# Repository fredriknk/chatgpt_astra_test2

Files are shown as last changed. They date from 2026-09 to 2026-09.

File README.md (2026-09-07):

# Codex EE-design test, human foreword
So, background, i saw the Chatgpt Astra demo for kicad design and wanted to try it out myself, i just have an Open AI plus subscription, so i had to use the LOW setting to not nuke my usage immidiatly. But it managed to make this design within my three usage resets. Im pretty damn impressed with the result, its not perfect, but it is a fully routed design with no drc errors made in under 3 hours with a 20$ subscription. I would say the most lacking part is the schematic, it is not very human readable, but i do understand why it is made as it is as ive tried multiple MCP's for ee design and wires in schematics becomes a hot mess with more than a few components. But now im out of resets so i thought i stop here. 

Initial repo: [my kicad template](https://github.com/fredriknk/kicad_template)
Initial promt: [prompt](https://github.com/fredriknk/chatgpt_astra_test2/blob/main/Prompt.md)

After the initial prompt i basically just said "Sounds like a good idea" to any questions

# ESP32 24 V current-loop interface - Rev A

A 100 x 80 mm, four-layer prototype with an ESP32-S3, one protected 4-20 mA input, and one sourcing 4-20 mA output. Power and signal grounds are shared; this is not an isolated interface.

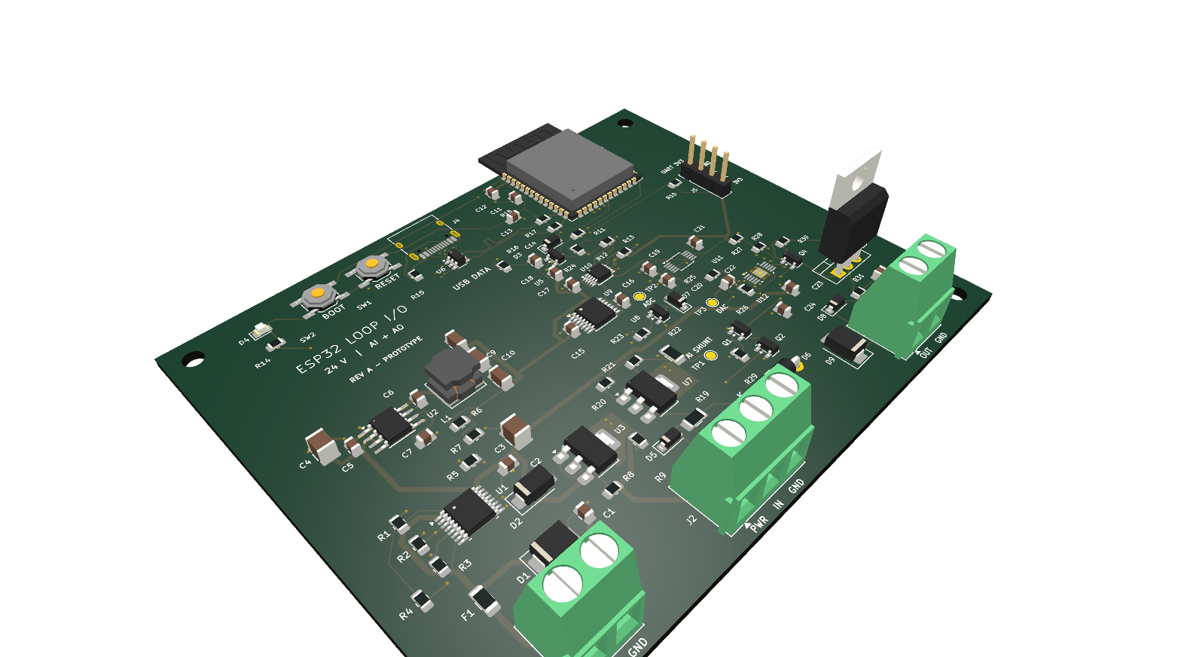
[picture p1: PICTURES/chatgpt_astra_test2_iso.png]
Rev A PCB


The layout is fully routed. Final KiCad 9 checks report **zero ERC violations, zero DRC violations, zero unconnected items, and zero schematic/PCB parity errors**. The independent connectivity check covers 93 components and 273 connected pins. Hardware accuracy, fault survival, thermal performance, EMC and USB interoperability still require prototype testing.

| Start here | Contents |
|---|---|
| [Design and bring-up guide](DOCUMENTATION/DESIGN.md) | Wiring, protection, firmware interface, calibration and bench tests |
| [Fabrication notes](DOCUMENTATION/FABRICATION.md) | Stackup, USB impedance, assembly and procurement |
| [KiCad project](CAD/chatgpt_astra_test2/chatgpt_astra_test2.kicad_pro) | Editable schematic and PCB, with local libraries |
| [Schematic PDF](DOCUMENTATION/chatgpt_astra_test2_schematic.pdf) | Five schematic sheets |
| [Board layers PDF](DOCUMENTATION/chatgpt_astra_test2_board_prints.pdf) | Copper, mask, silkscreen and assembly views |
| [Layout verification](DOCUMENTATION/board_review/README.md) | Checks, USB length audit and milestones |
| [Manufacturing outputs](PRODUCTION/20260907_1303_chatgpt_astra_test2/) | Four copper layers, masks, silk, paste, outline, drills, BOM and placement CSV |
| [CI build log](DOCUMENTATION/ci_build.log) | Successful complete output-pipeline run |

## Regenerate and check

On Windows with KiCad 9 installed, run `generate_outputs.bat`. The equivalent command is:

```text
python build_outputs.py --project CAD/chatgpt_astra_test2/chatgpt_astra_test2.kicad_pro --iso --zip
```

The script fails on ERC/DRC violations and generates a new timestamped production folder. It does not place an order. `generate_outputs.sh` provides the same entry point on systems with KiCad on PATH. Set `KICAD9_3DMODEL_DIR` to the installed KiCad model library if needed.

The BOM is an engineering BOM: semiconductor part numbers are in Value fields, while several passives retain value/rating specifications rather than purchasing MPNs. Review procurement before ordering. Three installed 3D models are missing (USB connector, DAC and current driver); their footprints are present, but the STEP/render is not a complete mechanical assembly model.

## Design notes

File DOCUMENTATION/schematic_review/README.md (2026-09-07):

# Revision A schematic review

Open [the KiCad project](../../CAD/chatgpt_astra_test2/chatgpt_astra_test2.kicad_pro), then its root schematic. The design has five A3 sheets and 93 physical components. Project-local symbol and footprint libraries are included.

## Sheet previews

1. [System interfaces](svg/chatgpt_astra_test2.svg)
2. [Power and sensor supply](svg/chatgpt_astra_test2-02%20_%20POWER%20AND%20SENSOR%20SUPPLY.svg)
3. [ESP32 and USB](svg/chatgpt_astra_test2-03%20_%20ESP32%20AND%20USB.svg)
4. [Current input](svg/chatgpt_astra_test2-04%20_%20PROTECTED%20CURRENT%20INPUT.svg)
5. [Current output](svg/chatgpt_astra_test2-05%20_%20PRECISION%20CURRENT%20OUTPUT.svg)

## Implemented decisions

- TPS26600 entry protection: approximately 399 mA current limit, 16.66 V nominal rising UV threshold and 33.80 V nominal rising OV threshold. RTN is deliberately separate from GND. Its exposed pad connects to RTN.
- LMR36510, 22 uH inductor, 100k/43.2k divider, three 22 uF output capacitors: nominal 3.315 V supply. Capacitor effective capacitance under bias and the exact inductor order code still require purchasing review.
- LT3092 sensor supply limiter: approximately 40.2 mA. LT3092 input limiter: approximately 30.1 mA. Both are configured as floating two-terminal limiters. This replaces the preliminary MAX14626 choice and avoids its bypass ground-current error.
- Input uses 100 ohm shunt, 1 kohm ADC series resistor, LM4040 3 V clamp, TMUX1511 powered-off isolation, and ADS1115.
- ESP32-S3-WROOM-1-N8, native USB-C data/programming, manual boot/reset, UART header and status LED. The board requires 24 V while programming. USB VBUS only serves USB-side ESD protection.
- TPS3839G33 supervises 3.3 V. Its SYS_OK signal inhibits the ADC switch and output enable during undervoltage. A diode couples the supervisor to ESP_EN without shorting the push-pull supervisor output when RESET is pressed.
- DAC80501Z is strapped to I2C address 0x49; ADS1115 uses 0x48. DAC firmware must select REF-DIV=1 and BUFF-GAIN=1 before enabling output.
- XTR111 uses 1.00 kohm RSET. Its local 3 V regulator pulls OD high independently of MCU power. Two series NMOS devices require both AO_ENABLE and SYS_OK to enable the output.
- IRF9540N TO-220 P-MOSFET, PNP current limiter, output RC and reverse-blocking diode. The PNP limit is approximately 33–37 mA per the reference approach, deliberately above the controlled output range. This supersedes the provisional 28–30 mA hardware-limit estimate.

## Checks completed

KiCad 9.0.7 loaded and exported all five sheets. ERC reports **zero errors and zero warnings**, with no exclusions introduced. The exported netlist contains 93 components and 97 nets. An independent export check matched 273 connected physical pins to the capture intent and checked every symbol pin against its assigned footprint's numbered pads. Results are in [verification.json](verification.json) and [erc.json](erc.json).

The schematic was rendered to SVG and PNG for visual review. Supply rails and return branches are connected visibly where aligned; named nets connect the remaining functional blocks. Labels marked as global connect between sheets.

## Engineering limits and bench work

This is a populated engineering prototype schematic, not a fabrication release. ERC does not prove analog performance or fault survival.

1. **Accuracy:** ±16 uA after calibration remains a room-temperature target. Quantify ADC gain/nonlinearity, shunt and RSET tolerance/drift, DAC/reference error, clamp leakage and ADC input loading. Validate independent midpoint readings after two-point calibration.
2. **Input protection:** test sustained +30 V and -30 V miswiring, limiter startup overshoot, 3 V clamp recovery and powered-off isolation. D6 and R19 provide transient limiting, but their pulse-energy coordination has not been qualified to an IEC surge level. The 33 V entry TVS likewise does not establish a downstream 33 V clamp.
3. **Thermal:** the input limiter may dissipate about 0.8 W during a positive miswire; the sensor limiter about 1.2 W into a short at 30 V. Allocate copper for each SOT-223 tab's own net. The output MOSFET dissipates roughly 0.6 W into a short at 20 mA/30 V. A -30 V externally forced output can roughly double this; assess heatsinking and DC SOA before promising continuous negative-output fault survival.
4. **Compliance:** at 18 V and 20 mA/500 ohms, 8 V remains for driver, resistors, diode, cable and entry losses. This looks feasible but requires worst-case and bench confirmation. Sensor voltage is reduced by BOTH sensor-supply and input protection drops; verify the actual sensor's minimum voltage, especially at 18 V.
5. **Startup/failure:** test reset, supply ramps and brownout. XTR111 OD does not guarantee absolutely zero startup glitch. No independent firmware watchdog is fitted; a firmware stall that leaves AO_ENABLE asserted can hold the last current command.
6. **Procurement/layout:** finalize exact fuse, inductor, precision resistor and capacitor manufacturer codes, verify package dimensions, and review the layout before manufacturing. Footprint pad coverage is checked; it is not a substitute for the final manufacturer land-pattern review. The PCB file remains the original empty template.

## Firmware pin assignment

| Function | ESP32 GPIO |
|---|---|
| I2C SDA / SCL | 8 / 9 |
| AO enable, active high | 10 |
| AO fault, active low | 11 |
| ADC ready | 12 |
| Status LED | 13 |
| USB D- / D+ | 19 / 20 |
| UART TX / RX | 43 / 44 |
| ROM boot strap | 0 |

## Reproducibility

[build_schematic.py](../../CODE/build_schematic.py) generated the schematic and local libraries. It overwrites generated schematic files when run; preserve manual KiCad edits before regenerating. It reads the existing local KiCad libraries specified near its top. [check_schematic.py](../../CODE/check_schematic.py) checks a freshly exported XML netlist and ERC report. The editable KiCad files do not require either script to open.

Manufacturer references are embedded in IC properties and linked in the [design plan](../esp32_4-20mA_design_plan.md). Additional references: [LT3092](https://www.analog.com/media/en/technical-documentation/data-sheets/lt3092.pdf), [LM4040](https://www.ti.com/lit/ds/symlink/lm4040-n.pdf), [TMUX1511](https://www.ti.com/lit/ds/symlink/tmux1511.pdf), [TPS3839](https://www.ti.com/lit/ds/symlink/tps3839.pdf).

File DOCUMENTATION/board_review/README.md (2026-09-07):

# Rev A layout verification

The prototype is fully routed: **0 DRC violations, 0 unconnected items and 0 schematic-parity errors**. See [native DRC JSON](drc.json), [CI DRC report](../chatgpt_astra_test2_drc.rpt) and [USB audit](usb_audit.json).

| Property | Final state |
|---|---|
| Board | 100 x 80 mm, nominal 1.6 mm, four copper layers |
| Components | 93 schematic components plus four M3 mounting holes |
| Copper | 1010 track segments and 106 vias |
| F.Cu / In2.Cu / B.Cu segments | 898 / 75 / 37 |
| In1.Cu | Ground-reference plane; no signal tracks |
| USB | Manual pair, top-layer protected section, symmetric connector joins |
| USB pair skew | Approximately 0.10 mm for both USB-C orientations |
| Thermal copper | U1 EF_RTN and U3/U7 OUT heat-spreading areas; correct nets verified |

[Top copper](routing.svg), [bottom copper](routing_bottom.svg), [top assembly render](../../PICTURES/chatgpt_astra_test2_top.png), [isometric render](../../PICTURES/chatgpt_astra_test2_iso.png), and [board-layer PDF](../chatgpt_astra_test2_board_prints.pdf).

USB data contacts use two through-board transitions per electrical path at the connector-side crossover. Ground return vias and a local In2.Cu ground area reference that bottom-layer section. The remainder runs on F.Cu above In1.Cu. The ESD device's equivalent channels were exchanged consistently in schematic and PCB, and the series resistors moved close to the module. The reported skew measures copper paths plus nominal via depth; internal component paths are excluded. Length matching does not certify impedance: order the specified stackup and have the fabricator confirm 90 ohms differential, +/-10%.

The overall prototype still needs the electrical, thermal and fault tests in [DESIGN.md](../DESIGN.md). CAD checks do not establish measured accuracy, surge immunity or continuous-fault survival. [FABRICATION.md](../FABRICATION.md) records procurement and mechanical-model limitations.

## Milestones

| Commit | Checkpoint |
|---|---|
| 26806e6 | Schematic |
| 2561262 | 100 x 80 mm placement |
| 73e48d3 | Initial buck and DAC routing |
| 2b1e08d | Feedback and analog sensing |
| 8d3c7f9 | Corrected persisted routing classes and fabrication constraints |
| 7b6780f | Bulk routing |
| ae18761 | Ground stitch and routing review |
| 490d238 | Fully connected, DRC-clean PCB |
| 024ed17 | USB refinement, thermal copper and named stackup |

The placement PNG/SVG/JSON and `board_3d.png` in this folder are historical placement-checkpoint artifacts. Use the current routing drawings and `PICTURES/` renders for Rev A.

The Python layout scripts record individual construction steps and expect their respective input checkpoints. **Do not run the placement/schematic generators over the finished project**: they can overwrite routed copper, local footprint refinements and later layout decisions. Open the current KiCad files for normal editing. The repeatable final output entry point is `generate_outputs.bat` or `generate_outputs.sh`.

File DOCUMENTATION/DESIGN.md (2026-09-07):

# Rev A design and bring-up guide

## Purpose and status

This board accepts nominal 24 V DC, measures one 4-20 mA process signal, and generates one sourcing 4-20 mA signal under ESP32-S3 control. The schematic and PCB are complete and the output pipeline passes. Firmware is not included.

The intended input range is 18-30 V DC. The room-temperature accuracy target is approximately +/-16 uA after calibration; this is not a measured specification. There is no galvanic isolation or system-level IEC qualification.

## Connector wiring

Pin numbers refer to the schematic and square/pin-1 PCB pads. Field terminals also have silkscreen labels.

| Connector | Pin | Function |
|---|---:|---|
| J1, DC input | 1 | Positive nominal 24 V |
| J1 | 2 | GND |
| J2, current input | 1 | Current-limited sensor supply, approximately 40 mA limit |
| J2 | 2 | AI_IN: positive current input |
| J2 | 3 | GND |
| J3, current output | 1 | AO_OUT: sourcing current output |
| J3 | 2 | GND / receiver return |
| J4 | USB-C | Native ESP32 USB data; does not power the board |
| J5 | 1 | GND |
| J5 | 2 | ESP32 UART TX, GPIO43 |
| J5 | 3 | ESP32 UART RX, GPIO44 |
| J5 | 4 | Board 3.3 V; logic reference, not a second power input |

For a two-wire loop-powered transmitter, connect J2.1 to its positive supply terminal and its negative/current return terminal to J2.2. For an independently powered current output, connect its output to J2.2 and its reference to J2.3; leave J2.1 unused. Do not parallel J2.1 with another supply.

Connect J3.1 to a passive receiver's current-input positive terminal and its return to J3.2. This output supplies loop current; it is not a two-wire passive transmitter. Available load compliance depends on supply voltage, cable resistance and driver/transistor/protection drops. Verify it at minimum supply voltage and maximum intended load. All field and USB grounds are common.

## Power and protection

| Block | Devices and intended behavior |
|---|---|
| Input protection | F1 500 mA fuse, D1 SMBJ33CA TVS and U1 TPS26600 eFuse |
| eFuse settings | R1/R2: nominal 16.66 V undervoltage threshold; R3/R4: nominal 33.80 V overvoltage threshold; R5: approximately 399 mA current limit; C2: controlled startup ramp |
| Protected rail | V24_PROT, with bulk capacitance and D2 negative-output clamp |
| Logic regulator | U2 LMR36510, L1 22 uH and R6/R7 feedback; nominal 3.315 V |
| Sensor supply | U3 LT3092 and R8/R9 limit J2.1 current to approximately 40.2 mA |
| Reset supervision | U5 TPS3839 monitors 3.3 V; D3 couples its output to ESP_EN without shorting the supervisor's push-pull output when RESET is pressed |

Thresholds/current limits are nominal calculations; tolerances, hysteresis and transients matter. Protection must be verified with a current-limited source before deployment. The eFuse's RTN/thermal pad is its own net, not GND. LT3092 tabs are OUT. Q3's tab is its drain. The layout preserves these net assignments.

## Current input

The path is J2.2 -> D5 -> R19 -> D6/U7 protection -> R22 shunt -> GND. U7 limits abnormal positive input current to approximately 30.1 mA. R22 is 100 ohms, 0.01%, target 10 ppm/degree C. It develops 0.4 V at 4 mA and 2.0 V at 20 mA.

R23, U8 LM4040-3.0 and D7 clamp the measurement node. U9 TMUX1511 disconnects the ADC path when SYS_OK is low. U10 ADS1115 measures AI_ADC single-ended against ground. The shunt has a dedicated sense takeoff and a return to the reference plane.

For ADS1115 configured to +/-4.096 V full scale:

```text
Vshunt = signed_adc_code * 125 uV
Iinput = Vshunt / 100 ohms = signed_adc_code * 1.25 uA
```

Ideal readings are approximately 3200 counts at 4 mA and 16000 counts at 20 mA. The ADC range setting does not permit the input pin to exceed its supply rails. Reject communication failures and out-of-range readings in firmware; choose filtering/data rate for the required response and noise level.

## Current output

U11 DAC80501Z drives U12 XTR111. R26 is 1 kohm, 0.01%, target 10 ppm/degree C:

```text
Ioutput = 10 * Vdac / R26 = 10 mA/V * Vdac
```

Configure the DAC for an effective 2.5 V full-scale span: internal reference enabled, REF-DIV=1 and BUFF-GAIN=1. Nominal 4 mA and 20 mA codes are approximately 10486 and 52429. Confirm register programming and actual DAC span during bring-up before enabling the output.

R25/C22 filter the DAC output. Q3 IRF9540 provides high-side drive. Q4/R30 add a fallback current limit, nominally 33-37 mA rather than a precision limit. R31/C25, D8 and D9 provide output filtering and fault/transient protection. Load compliance must account for their series drops.

R27 pulls XTR_OD high, disabling output independently of the MCU supply. Q1/Q2 pull it low only when AO_ENABLE and SYS_OK are high. AO_FAULT_N reports the driver's active-low error output. The design defaults to disabled at reset, but startup/shutdown current glitches still require measurement. There is no independent watchdog that forces zero current if firmware stalls with AO_ENABLE high.

## Firmware interface

| Signal | ESP32-S3 GPIO | Notes |
|---|---:|---|
| I2C SDA / SCL | 8 / 9 | 4.7 kohm pull-ups to 3.3 V |
| AO_ENABLE | 10 | Active high; keep low until analog configuration is verified |
| AO_FAULT_N | 11 | Active-low XTR111 fault |
| ADC_RDY | 12 | ADS1115 ALERT/RDY, with pull-up |
| Status LED | 13 | Green LED through R14 |
| USB D- / D+ | 19 / 20 | Native USB, 22 ohm series resistors and ESD protection |
| UART TX / RX | 43 / 44 | J5, 3.3 V logic |
| BOOT | 0 | BOOT button / download strap |

ADS1115 uses 7-bit address **0x48**; DAC80501 uses **0x49**. Select ESP32 firmware/USB settings appropriate to the module and programming method.

Startup sequence:

1. Hold AO_ENABLE low, initialize GPIOs/I2C, and verify both analog devices respond.
2. Configure the DAC reference/divider/gain and write a safe code while output remains disabled.
3. Configure ADS1115 channel/range/rate and discard unsettled readings.
4. Load valid calibration coefficients, check supply state and AO_FAULT_N, then enable output deliberately.
5. Clamp normal commands to the supported range. Disable output on detected analog communication or supply faults and define recovery behavior explicitly.

## Calibration

Calibrate at stable temperature using instruments comfortably more accurate than the target board accuracy. For input calibration, apply known currents I1/I2 near 4/20 mA and record codes C1/C2. Use `I = I1 + (C-C1)*(I2-I1)/(C2-C1)`. Check intermediate points and repeat after power cycling.

For output calibration, measure currents at two safe DAC codes and derive code-versus-current slope/offset. Validate at 4, 8, 12, 16 and 20 mA with representative loads. Store coefficients with a version/checksum, board serial number, date, temperature and reference instrument. Reject missing/corrupt calibration rather than presenting calibrated accuracy.

## Bring-up and acceptance tests

| Step | Check |
|---|---|
| Unpowered inspection | Orientation, bridges, exposed-pad joints, precision grades, polarity and rail resistance |
| First power | Current-limited source, no field loads; inspect V24_PROT, 3.3 V, consumption and temperature |
| Programming | RESET/BOOT, UART, both USB-C orientations, enumeration, sustained transfers and reconnects |
| Analog supplies | XTR regulator and DAC reference/span; AO_ENABLE low must leave output disabled |
| Input transfer | 0, 4, 12, 20 and modest overrange current, noise/settling, power-off injection |
| Output transfer | Representative loads, minimum-supply compliance, open/short load and fault indication |
| Sequencing | Ramps, brownouts, rapid cycling, USB-only connection, loss of MCU supply, reset during output |
| Faults | Incremental current-limited field miswiring/reversal; record clamp waveforms and temperature |
| Thermal | Maximum normal load and sensor/output shorts at intended ambient/enclosure conditions |

TP1 is the shunt node, TP2 the ADC-side node, and TP3 the filtered DAC voltage. Use a nearby ground when probing fast clamp behavior.

U3 can dissipate approximately 1.2 W during a 30 V sensor-supply short; U7 can approach 0.8 W during a positive input fault. Copper spreads heat but does not replace thermal testing. Q3 dissipates roughly 0.6 W at 20 mA into a short from a 30 V rail; externally forcing the output negative increases dissipation. Establish fault duration and any heatsink/ambient derating before sustained-fault use.

## References

- [Espressif layout guidance](https://docs.espressif.com/projects/esp-hardware-design-guidelines/en/latest/esp32s3/pcb-layout-design.html): reference plane and USB requirements.
- [TPS2660](https://www.ti.com/lit/ds/symlink/tps2660.pdf), [LMR36510](https://www.ti.com/lit/ds/symlink/lmr36510.pdf): power/protection.
- [LT3092](https://www.analog.com/media/en/technical-documentation/data-sheets/3092fc.pdf): current limiting/thermal behavior.
- [ADS1115](https://www.ti.com/lit/ds/symlink/ads1115.pdf), [DAC80501](https://www.ti.com/lit/ds/symlink/dac80501.pdf), [XTR111](https://www.ti.com/lit/ds/symlink/xtr111.pdf): conversion and configuration.
- [ST USBLC6-2](https://www.st.com/resource/en/datasheet/usblc6-2.pdf): equivalent ESD channels and short reference connections.

Earlier planning notes retain calculation history. This guide and the current CAD files describe final Rev A.

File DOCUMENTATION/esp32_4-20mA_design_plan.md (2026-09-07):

# ESP32 24 V / 4–20 mA controller — preliminary design

Status: revision A schematic captured, 2026-09-07. Five sheets, 93 components, zero KiCad ERC violations. See the [schematic review](schematic_review/README.md) for implemented component choices, verification and remaining bench work. The preliminary choices below are retained as planning context; the schematic review supersedes them where noted.

## Scope and provisional requirements

Confirmed: ESP32 controller, nominal 24 V input, read and generate 4–20 mA.

Accepted architecture: one input and one output; common ground; input accepts an externally powered transmitter or a two-wire transmitter powered from a dedicated board terminal; output sources current into a passive receiver. The output is not a passive two-wire loop-powered transmitter. Exact connected equipment is not yet specified.

## Protection recommendation, 2026-09-07

- Main entry: fuse, bidirectional TVS, TPS26600-class eFuse with reverse polarity blocking, adjustable overvoltage cutoff, current limiting and soft start. Provisional cutoff about 33 V and current limit about 0.4 A; finalize tolerances and inrush. Coordinate TVS clamping at the specified pulse current with eFuse ratings and downstream transient exposure. A nominal TVS voltage is not its clamping voltage.
- Sensor supply: separate current-limited switch, provisionally 35–50 mA, so a cable short does not reset the controller; verify sensor startup current.
- Analog input: MAX14626 is a purpose-built candidate with 27–33 mA current limit, reverse-input blocking and thermal protection. It requires additional transient coordination and ADC protection. Its ground current (40 µA typical, 56 µA maximum under specified conditions) can bypass the shunt in the conventional connection, exceeding the 16 µA accuracy target before calibration. Do not freeze this part until residual error and drift are budgeted; use a lower-leakage limiter/disconnect arrangement if needed. Allow up to 2.8 V protector drop at 24 mA per datasheet. At 33 mA, the 100 ohm shunt develops 3.3 V, so resistor tolerance, limiter overshoot and ADC power-off protection matter.
- ADC branch: series resistance, RC filtering and low-leakage voltage clamps or a fault-protected switch that remains protective with 3.3 V off. Do not rely on internal ADC diodes or a rail clamp that back-powers 3.3 V.
- Analog output: datasheet XTR111 external current-limit network, thermally sized P-MOSFET, reverse-current blocking toward the driver and coordinated terminal transient clamp. Check both polarities of externally applied terminal voltage, including when the board is off. Provisional hardware current limit about 28–30 mA, subject to tolerance and thermal analysis.
- USB: low-capacitance data-line ESD array at connector; keep VBUS out of board power path for this revision.

Protection targets are sustained ±30 V field miswiring where applicable, output/sensor shorts and ordinary handling/hot-plug transients. No IEC surge or ESD compliance is claimed without a selected test level and validation.

Sources: [TPS2660 family](https://www.ti.com/product/TPS2660), [MAX14626 datasheet](https://www.analog.com/media/en/technical-documentation/data-sheets/max14626.pdf), and XTR111 reference below. Component values remain preliminary.

- Supply target: 18–30 V DC continuous.
- Input measurement range: 0–25 mA, nominal signal 4–20 mA.
- Output nominal range: 4–20 mA; allow controlled diagnostic overrange up to about 24 mA.
- Load target: 0–500 ohms including cable resistance, across supply range.
- Update target: 10 readings/s and 10 output updates/s.
- Initial accuracy target: ±16 µA (0.1% of 16 mA span), after individual two-point calibration at room temperature. Temperature range and drift requirement remain open; resolution alone does not establish accuracy.
- Provisional boot/reset behavior: output disabled until DAC configuration and application initialization succeed. Running-firmware failure requires an independent watchdog if guaranteed shutdown is required.

## Circuit blocks and candidate parts

1. Power: fused/current-limited entry, reverse-polarity protection and coordinated TVS clamp; LMR36510-class 65 V / 1 A buck to 3.3 V. Filter the analog supply locally. Choose final clamp and surge circuitry against the lowest rated downstream part, not only the buck rating. XTR111 operating supply tops out at 44 V.
2. MCU: ESP32-S3-WROOM-1 module; select memory variant later. USB data programming, ESD protection, boot/reset controls and UART test pads. Initially require 24 V board power while programming; USB VBUS must not backfeed the board. Follow Espressif supply, strap-pin and antenna rules.
3. Input: protected low-side 100 ohm precision shunt, Kelvin sensing, RC filtering, ADS1115 at 3.3 V. Start with ±4.096 V PGA range to preserve overrange measurement; analog pins still must remain within their supply limits.
4. Output: DAC80501 at 3.3 V with 2.5 V output range, XTR111, external P-channel MOSFET and datasheet current-limiting circuit. Use RSET = 1.00 kohm, preferably 0.01%, low temperature coefficient. Filter DAC output with settling time appropriate for 10 Hz operation.
5. Diagnostics: route XTR111 error flag to MCU with compatible pull-up; hardware default-disable on OD with sequencing checked. Add test points for shunt voltage, DAC voltage, protected supply and 3.3 V. Error flag does not replace measured output-current feedback.

## Calculations

Input: V = I × 100 ohms. At 4 / 20 / 25 mA, voltage is 0.4 / 2.0 / 2.5 V. Shunt dissipation at 25 mA is 62.5 mW; start with a 0.25 W precision part and verify derating. At ±4.096 V ADC range, nominal LSB is 125 µV, equivalent to 1.25 µA. Noise and error budget must be assessed separately.

A direct 24 V miswire across 100 ohms would dissipate 5.76 W. Therefore the bare shunt plus ADC clamp is insufficient. Select a series fault-current limiter/disconnect and coordinated clamps; verify continuous 30 V miswire, reverse voltage, leakage error and power-off behavior before schematic release. Extra series voltage drop reduces available sensor voltage.

Output: XTR111 transfer is IOUT = 10 × VIN / RSET. With 1.00 kohm, 0.4 V gives 4 mA and 2.0 V gives 20 mA; 2.4 V gives 24 mA. A 2.5 V / 16-bit DAC gives approximately 0.381 µA per code. Firmware shall clamp the normal command range and calibration results.

At 20 mA through 500 ohms, the load consumes 10 V. At 18 V input, 8 V remains before supply protection, cable and driver losses. At 24 mA it leaves 6 V. Complete the worst-case compliance calculation using the chosen transistor and protection network.

At 30 V and a near-zero-ohm load, total linear output-stage dissipation approaches 0.60 W at 20 mA or 0.72 W at 24 mA. Select the MOSFET using DC safe operating area and thermal resistance, not only on-resistance; allocate PCB copper and test short-circuit temperatures.

Reserve 3.3 V × 1 A = 3.3 W supply capacity for MCU and local electronics; this is a design allowance, not a measured consumption. Two 24 mA loops add up to 48 mA from the field supply. At 18 V and assumed 85% buck efficiency the combined allowance is about 0.264 A before margin and auxiliary loads. Start with a 24 V / 0.5 A bench supply; finalize fuse, inrush and sensor-power limits separately.

## Proposed terminals and wiring

| Connector | Pins | Purpose |
|---|---|---|
| J1 | VIN24, GND | Board power |
| J2 | SENSOR_PWR, AI_IN, GND | Protected sensor supply and current input |
| J3 | AO_OUT, GND | Sourcing current output |
| J4 | USB | Programming/data; 24 V required initially |

Two-wire input sensor: SENSOR_PWR → sensor +; sensor − → AI_IN. Current returns through the board shunt. Sensor-power terminal needs its own current limit. Minimum sensor voltage is protected supply minus shunt, protection and cable drops.

Externally powered current transmitter: signal current output → AI_IN, signal return → GND, provided the transmitter supports this common-ground connection. Leave SENSOR_PWR unused.

Output: AO_OUT → passive receiver +; receiver − → GND. Do not connect this sourcing output to a receiver terminal that supplies loop power.

All GND terminals and USB ground are electrically common. Isolation remains an architectural decision before schematic capture.

## KiCad structure and layout

Use existing CAD/chatgpt_astra_test2 project. Proposed sheets: top-level interfaces; power/protection; ESP32/USB; analog input; analog output.

Four-layer PCB with continuous ground plane. Keep switch-node copper compact and away from ADC, shunt and DAC. Kelvin-route the shunt and RSET ground return. Place terminal protection near connectors. Keep output transistor heat away from precision resistors. Follow module antenna copper/component keepout. Final dimensions and mounting holes remain open.

## Verification and remaining design work

Before capture: settle channel count/isolation/receiver type; choose exact protection parts and MOSFET; complete worst-case error, compliance and thermal budgets; check all pin logic levels, DAC startup variant, watchdog behavior and power sequencing.

After capture: verify symbols/footprints against manufacturer pinouts, run ERC and review loop paths. After layout: DRC, thermal/return-path review and fabrication outputs.

Bench acceptance: current-limited power-up at 18/24/30 V; input readings at 0/4/12/20/25 mA; output measurements at 4/12/20 mA into 0/250/500 ohms; two-point calibration with independent midpoint checks; open-loop and short-load behavior; reset/brownout/firmware-stall behavior; controlled miswire tests after protection analysis; Wi-Fi activity noise check. Temperature accuracy requires a separately agreed range and test.

## Manufacturer references

- [XTR111 datasheet](https://www.ti.com/lit/ds/symlink/xtr111.pdf): transfer function, compliance, external transistor and protection recommendations.
- [ADS1115](https://www.ti.com/product/ADS1115): ADC ranges and specifications.
- [DAC80501](https://www.ti.com/product/DAC80501): DAC supply, range, reference and startup variants.
- [LMR36510](https://www.ti.com/product/LMR36510): buck candidate.
- [ESP32-S3 schematic checklist](https://docs.espressif.com/projects/esp-hardware-design-guidelines/en/latest/esp32s3/schematic-checklist.html): MCU implementation requirements.

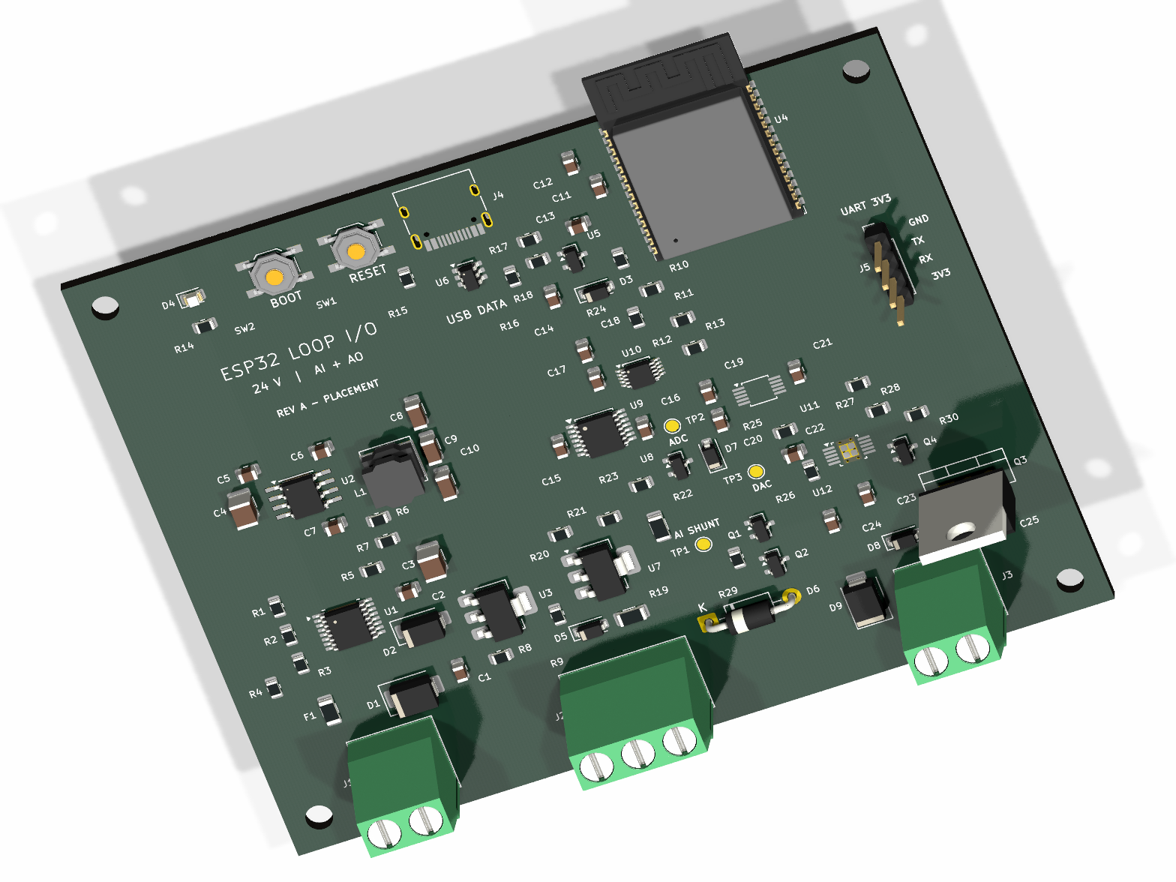
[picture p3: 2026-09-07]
DOCUMENTATION/board_review/board_3d.png

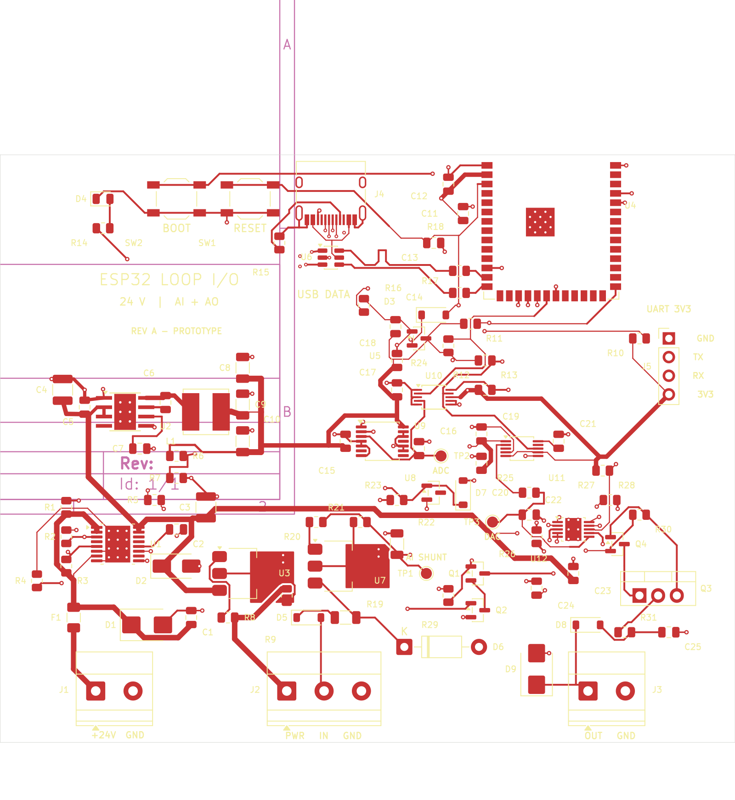
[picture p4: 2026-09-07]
DOCUMENTATION/board_review/routing.png

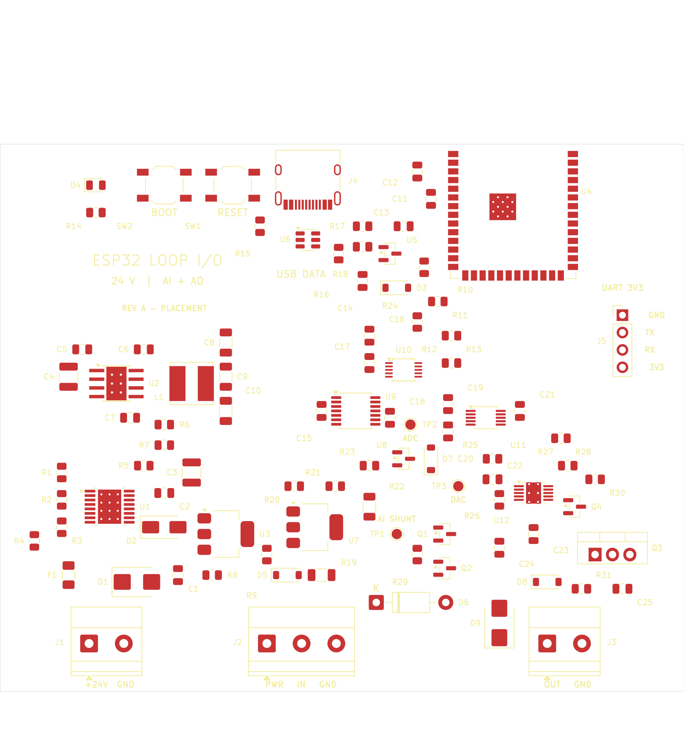
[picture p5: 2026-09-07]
DOCUMENTATION/board_review/placement.png

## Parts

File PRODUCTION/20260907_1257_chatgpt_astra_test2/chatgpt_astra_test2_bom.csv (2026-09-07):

Refs | Value | Footprint | Qty | Manufacturer | MPN | Datasheet | DNP
C1 | 100n / 100V | LoopIO:C_0805_2012Metric | 1 |  |  | ~
C2 | 10n / 50V | LoopIO:C_0805_2012Metric | 1 |  |  | ~
C3 | 22u / 63V | LoopIO:C_1210_3225Metric | 1 |  |  | ~
C4 | 2.2u / 100V | LoopIO:C_1210_3225Metric | 1 |  |  | ~
C5 | 220n / 100V | LoopIO:C_0805_2012Metric | 1 |  |  | ~
C6,C12,C14-C17,C19,C21 | 100n / 16V | LoopIO:C_0805_2012Metric | 8 |  |  | ~
C7,C18,C20,C22,C24 | 1u / 16V | LoopIO:C_0805_2012Metric | 5 |  |  | ~
C8-C10 | 22u / 10V | LoopIO:C_1206_3216Metric | 3 |  |  | ~
C11 | 10u / 10V | LoopIO:C_0805_2012Metric | 1 |  |  | ~
C13 | 1u / 10V | LoopIO:C_0805_2012Metric | 1 |  |  | ~
C23 | 100n / 50V | LoopIO:C_0805_2012Metric | 1 |  |  | ~
C25 | 10n / 100V | LoopIO:C_0805_2012Metric | 1 |  |  | ~
D1,D9 | SMBJ33CA | LoopIO:D_SMB | 2 |  |  | ~
D2 | SS110 | LoopIO:D_SMA | 1 |  |  | ~
D3,D7 | BAT54W | LoopIO:D_SOD-123 | 2 |  |  | ~
D4 | GREEN | LoopIO:LED_0805_2012Metric | 1 |  |  | ~
D5,D8 | BAV21W | LoopIO:D_SOD-123 | 2 |  |  | ~
D6 | BZX85C33 / 1.3W | LoopIO:D_DO-41_SOD81_P10.16mm_Horizontal | 1 |  |  | ~
F1 | 500mA / >=60V | LoopIO:Fuse_1206_3216Metric | 1 |  |  | ~
J1 | 18-30 V DC | LoopIO:TerminalBlock_Phoenix_MKDS-1,5-2-5.08_1x02_P5.08mm_Horizontal | 1 |  |  | ~
J2 | CURRENT INPUT | LoopIO:TerminalBlock_Phoenix_MKDS-1,5-3-5.08_1x03_P5.08mm_Horizontal | 1 |  |  | ~
J3 | CURRENT OUTPUT | LoopIO:TerminalBlock_Phoenix_MKDS-1,5-2-5.08_1x02_P5.08mm_Horizontal | 1 |  |  | ~
J4 | USB-C | LoopIO:USB_C_Receptacle_HRO_TYPE-C-31-M-12 | 1 |  |  | https://www.usb.org/sites/default/files/documents/usb_type-c.zip
J5 | UART / 3.3 V ONLY | LoopIO:PinHeader_1x04_P2.54mm_Vertical | 1 |  |  | ~
L1 | 22uH / Isat >=2A | LoopIO:L_Bourns_SRN6045TA | 1 |  |  | ~
Q1,Q2 | 2N7002 | LoopIO:SOT-23 | 2 |  |  | https://www.onsemi.com/pub/Collateral/NDS7002A-D.PDF
Q3 | IRF9540NPBF | LoopIO:TO-220-3_Vertical | 1 |  |  | http://www.irf.com/product-info/datasheets/data/irf9540n.pdf
Q4 | MMBT3906 | LoopIO:SOT-23 | 1 |  |  | https://www.onsemi.com/pdf/datasheet/pzt3906-d.pdf
R1 | 130k / 0.1% | LoopIO:R_0805_2012Metric | 1 |  |  | ~
R2,R4 | 10k / 0.1% | LoopIO:R_0805_2012Metric | 2 |  |  | ~
R3 | 274k / 0.1% | LoopIO:R_0805_2012Metric | 1 |  |  | ~
R5 | 30.1k / 1% | LoopIO:R_0805_2012Metric | 1 |  |  | ~
R6 | 100k / 0.1% | LoopIO:R_0805_2012Metric | 1 |  |  | ~
R7 | 43.2k / 0.1% | LoopIO:R_0805_2012Metric | 1 |  |  | ~
R8 | 40.2k / 0.1% | LoopIO:R_0805_2012Metric | 1 |  |  | ~
R9,R21 | 10R / 0.1% | LoopIO:R_0805_2012Metric | 2 |  |  | ~
R10,R11,R24,R27,R28 | 10k | LoopIO:R_0805_2012Metric | 5 |  |  | ~
R12,R13 | 4.7k | LoopIO:R_0805_2012Metric | 2 |  |  | ~
R14,R25 | 1k | LoopIO:R_0805_2012Metric | 2 |  |  | ~
R15,R16 | 5.1k / 1% | LoopIO:R_0805_2012Metric | 2 |  |  | ~
R17,R18 | 22R | LoopIO:R_0805_2012Metric | 2 |  |  | ~
R19 | 33R / pulse rated | LoopIO:R_1206_3216Metric | 1 |  |  | ~
R20 | 30.1k / 0.1% | LoopIO:R_0805_2012Metric | 1 |  |  | ~
R22 | 100R / 0.01% / 10ppm | LoopIO:R_1206_3216Metric | 1 |  |  | ~
R23 | 1k / 0.1% | LoopIO:R_0805_2012Metric | 1 |  |  | ~
R26 | 1k / 0.01% / 10ppm | LoopIO:R_0805_2012Metric | 1 |  |  | ~
R29 | 100k | LoopIO:R_0805_2012Metric | 1 |  |  | ~
R30,R31 | 15R | LoopIO:R_0805_2012Metric | 2 |  |  | ~
SW1 | RESET | LoopIO:SW_SPST_TL3342 | 1 |  |  | ~
SW2 | BOOT | LoopIO:SW_SPST_TL3342 | 1 |  |  | ~
TP1 | AI_SHUNT | LoopIO:TestPoint_Pad_D1.5mm | 1 |  |  | ~
TP2 | AI_ADC | LoopIO:TestPoint_Pad_D1.5mm | 1 |  |  | ~
TP3 | DAC_FILTER | LoopIO:TestPoint_Pad_D1.5mm | 1 |  |  | ~
U1 | TPS26600PWPR | LoopIO:HTSSOP-16-1EP_4.4x5mm_P0.65mm_EP3.4x5mm_Mask2.66x2.46mm_ThermalVias | 1 |  |  | https://www.ti.com/lit/ds/symlink/tps2660.pdf
U2 | LMR36510ADDAR | LoopIO:Texas_HTSOP-8-1EP_3.9x4.9mm_P1.27mm_EP2.95x4.9mm_Mask2.4x3.1mm_ThermalVias | 1 |  |  | http://www.ti.com/lit/ds/symlink/lmr36510.pdf
U3,U7 | LT3092EST#PBF | LoopIO:SOT-223-3_TabPin2 | 2 |  |  | https://www.analog.com/media/en/technical-documentation/data-sheets/lt3092.pdf
U4 | ESP32-S3-WROOM-1-N8 | LoopIO:ESP32-S3-WROOM-1 | 1 |  |  | https://www.espressif.com/sites/default/files/documentation/esp32-s3-wroom-1_wroom-1u_datasheet_en.pdf
U5 | TPS3839G33DBZR | LoopIO:SOT-23 | 1 |  |  | http://www.ti.com/lit/ds/sbvs193d/sbvs193d.pdf
U6 | USBLC6-2SC6 | LoopIO:SOT-23-6 | 1 |  |  | https://www.st.com/resource/en/datasheet/usblc6-2.pdf
U8 | LM4040AIM3-3.0 | LoopIO:SOT-23 | 1 |  |  | http://www.ti.com/lit/ds/symlink/lm4040-n.pdf
U9 | TMUX1511PWR | LoopIO:TSSOP-14_4.4x5mm_P0.65mm | 1 |  |  | https://www.ti.com/lit/ds/symlink/tmux1511.pdf
U10 | ADS1115IDGSR | LoopIO:TSSOP-10_3x3mm_P0.5mm | 1 |  |  | http://www.ti.com/lit/ds/symlink/ads1113.pdf
U11 | DAC80501ZDGSR | LoopIO:VSSOP-10_3x3mm_P0.5mm | 1 |  |  | https://www.ti.com/lit/ds/symlink/dac80501.pdf
U12 | XTR111AIDGQR | LoopIO:MSOP-10-1EP_3x3mm_P0.5mm_EP2.2x3.1mm_Mask1.83x1.89mm_ThermalVias | 1 |  |  | https://www.ti.com/lit/ds/symlink/xtr111.pdf

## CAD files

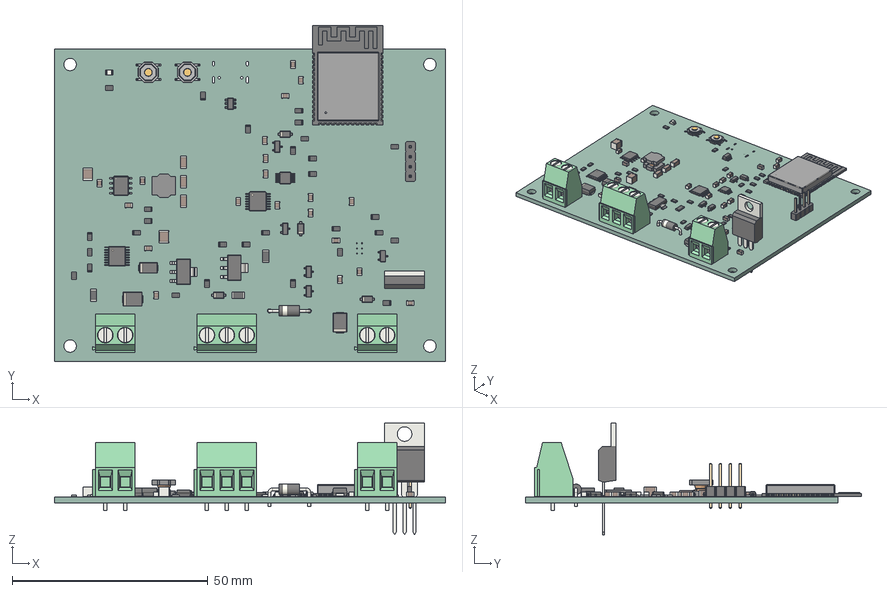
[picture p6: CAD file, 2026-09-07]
3D_MODEL/chatgpt_astra_test2.step
100.0 x 86.0 x 28.5 mm
R_0805_2012Metric x 29
C_0805_2012Metric x 20
D_SOD-123 x 4
TSSOP-14_4.4x5mm_P0.65mm
Texas_HTSOP-8-1EP_3.9x4.9mm_P1.27mm_EP2.85x4.9mm_Mask2.4x3.1mm_ ThermalVias
PinHeader_1x04_P2.54mm_Vertical
R_1206_3216Metric x 2
D_SMB x 2
TSSOP-10_3x3mm_P0.5mm
C_1210_3225Metric x 2
D_SMA
C_1206_3216Metric x 3
D_DO-41_SOD81_P10.16mm_Horizontal
SOT-223 x 2
ESP32-S3-WROOM-1
Fuse_1206_3216Metric
TerminalBlock_Phoenix_MKDS-1,5-2-5.08_1x02_P5.08mm_Horizontal x 2
TO-220-3_Vertical
LED_0805_2012Metric
SW_SPST_TL3342 x 2
SOT-23-6
HTSSOP-16-1EP_4.4x5mm_P0.65mm_EP3.4x5mm_Mask2.66x2.46mm
SOT-23 x 5
L_Bourns_SRN6045TA
TerminalBlock_Phoenix_MKDS-1,5-3-5.08_1x03_P5.08mm_Horizontal
chatgpt_astra_test2_PCB

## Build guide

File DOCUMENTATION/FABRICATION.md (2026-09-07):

# Rev A fabrication and assembly

| Item | Specification |
|---|---|
| Outline | 100 x 80 mm; X=50-150 mm, Y=50-130 mm |
| Mounting | Four 3.2 mm NPTH M3 holes, 92 x 72 mm centre spacing |
| Stackup | Nominal 1.6 mm, four layers; JLC04161H-7628 reference construction |
| Finish | ENIG selected in board stackup |
| Outer / inner copper | 35 um / 15.2 um nominal |
| Outer prepreg | 0.2104 mm FR4 7628 each side, nominal Dk 4.4 |
| Core | 1.065 mm FR4, nominal Dk 4.6 |
| Minimum trace / clearance | 0.15 / 0.15 mm; ordinary nets use 0.2 mm clearance |
| Ordinary vias | 0.6 mm land / 0.3 mm drill |
| USB-area vias | 0.5 mm land / 0.25 mm drill, with ground returns |
| Copper-to-edge | At least 0.3 mm, except intentional component overhang |
| USB impedance | Request 90 ohms differential, +/-10%; 0.25 mm width / 0.15 mm gap on paired sections, with local fanout exceptions |

Dielectric/copper values follow the [JLCPCB published stackup](https://jlcpcb.com/impedance). Finished thickness includes process tolerances and coatings; constituent dimensions are not an exact finished-thickness promise. For another fabricator/stackup, recalculate USB geometry. Obtain fabricator impedance confirmation; KiCad width/gap settings and length checks are not a field-solver result.

F.Cu contains primary routing and local thermal copper. In1.Cu is ground with no signal tracks. In2.Cu carries secondary routing and a local ground reference beneath the bottom-layer USB crossover. B.Cu contains short secondary routes and heat-spreading copper.

The antenna overhangs the board by approximately 6.2 mm. Preserve its keepout and allow enclosure clearance for antenna, plugs, terminal access and cable bends. Keep metal away from the antenna region.

## Assembly

- U1's thermal pad/copper is **EF_RTN**, not GND. U3/U7 tabs/copper are their respective **OUT** nets. Top/bottom copper and adjacent vias spread their heat.
- U1/U4/U12 exposed-pad footprints have 0.3 mm plated holes with 0.6 mm lands. Review paste coverage and via tenting/filling with the assembler to manage solder wicking.
- Q3's tab is its drain. Any heatsink must respect insulation/clearance; none is included in the mechanical model.
- All 93 electrical components are on top. Mounting holes are mechanical-only. Assemble through-hole parts separately; the generic position CSV is not a filtered SMT machine program.
- R22/R26 require their stated precision and temperature coefficient. Ceramic capacitors must retain suitable effective capacitance under DC bias. L1 needs the required inductance, saturation/current rating and physical fit.

The engineering BOM retains value/rating specifications for several passives; manufacturer/MPN columns are not fully populated. Confirm purchasing parts and substitutions before ordering or using an assembly service. No vendor-specific assembly package or purchasing order was generated.

## Package and mechanical model

The successful output run is `PRODUCTION/20260907_1303_chatgpt_astra_test2/`. Its ZIP includes Gerbers and drill files. Check the fabricator preview for four copper layers, masks, silk, outline, plated drills and NPTH drills. Paste layers are included for stencil use.

The STEP/renders omit three unavailable library models: J4 USB-C, U11 DAC and U12 XTR111. Their electrical footprints/BOM entries are present. Use PCB/F.Fab geometry and component drawings for those positions; the STEP is not a complete enclosure collision check.

This is a routed prototype with passing CAD checks. [Bring-up and fault tests](DESIGN.md) establish actual operating limits before deployment.

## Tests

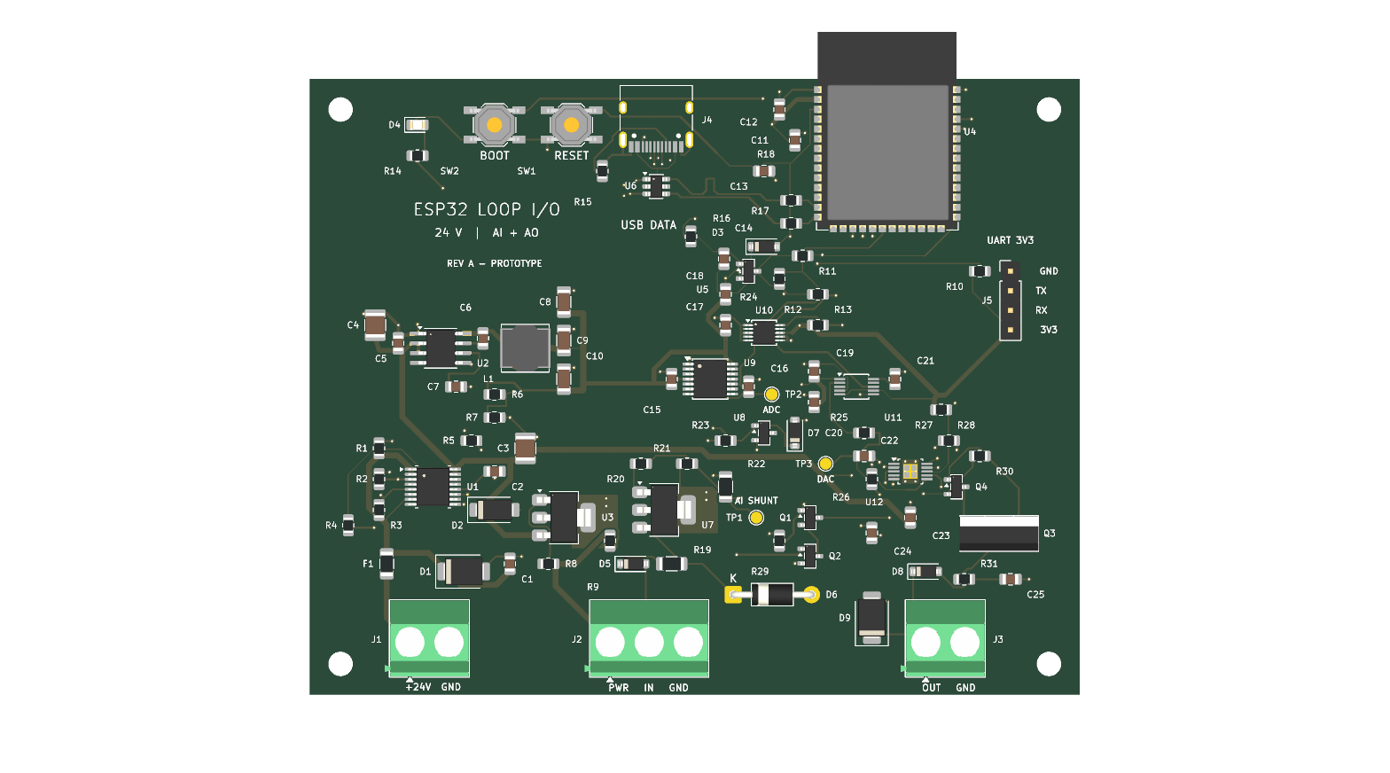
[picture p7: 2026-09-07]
PICTURES/chatgpt_astra_test2_top.png

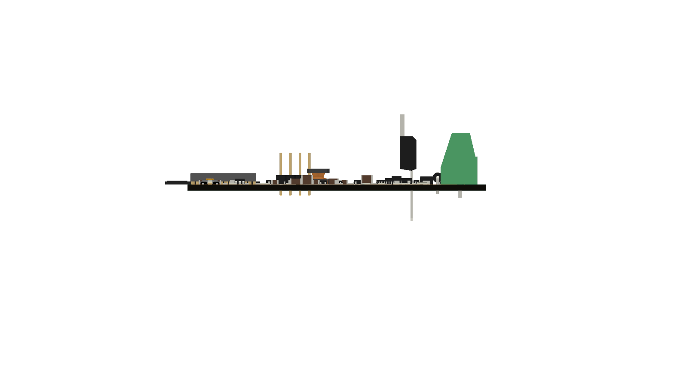
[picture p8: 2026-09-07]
PICTURES/chatgpt_astra_test2_side.png

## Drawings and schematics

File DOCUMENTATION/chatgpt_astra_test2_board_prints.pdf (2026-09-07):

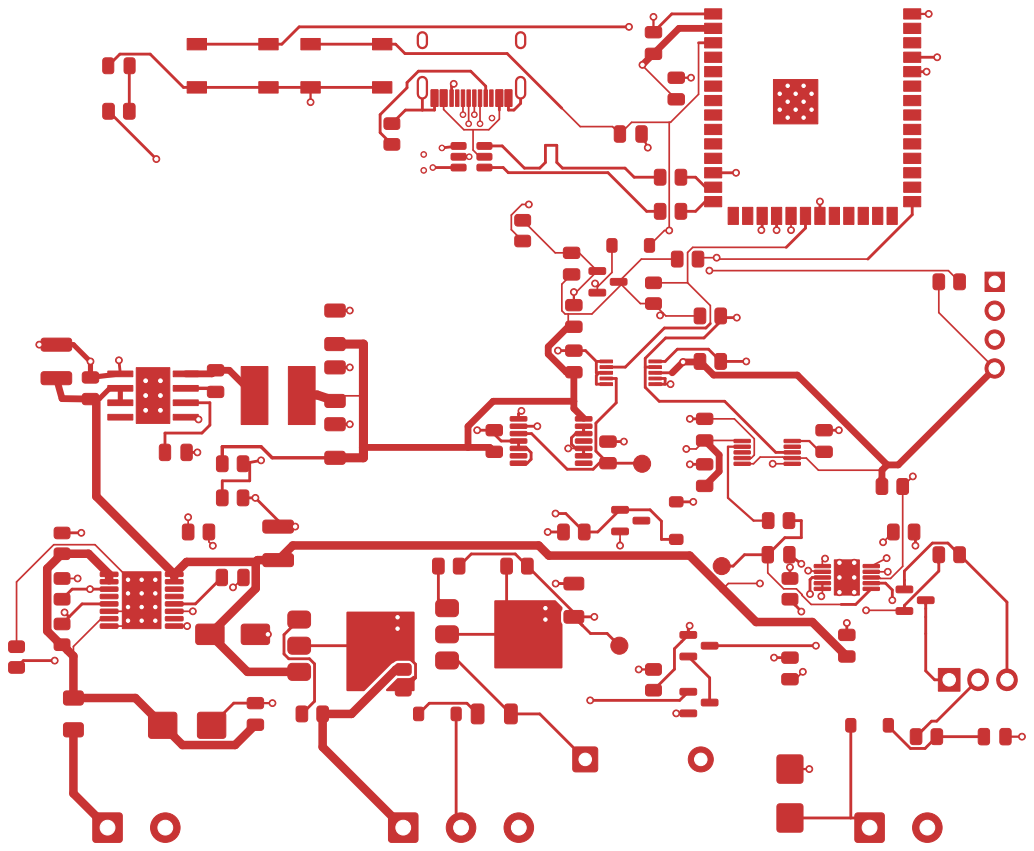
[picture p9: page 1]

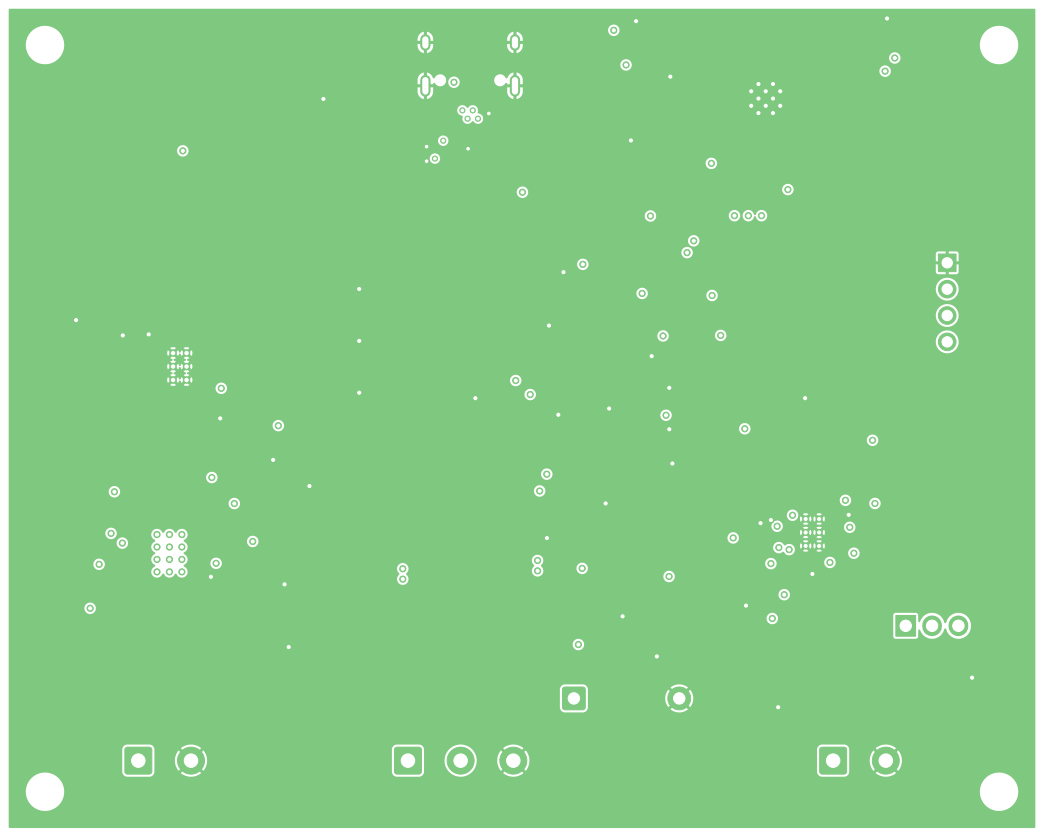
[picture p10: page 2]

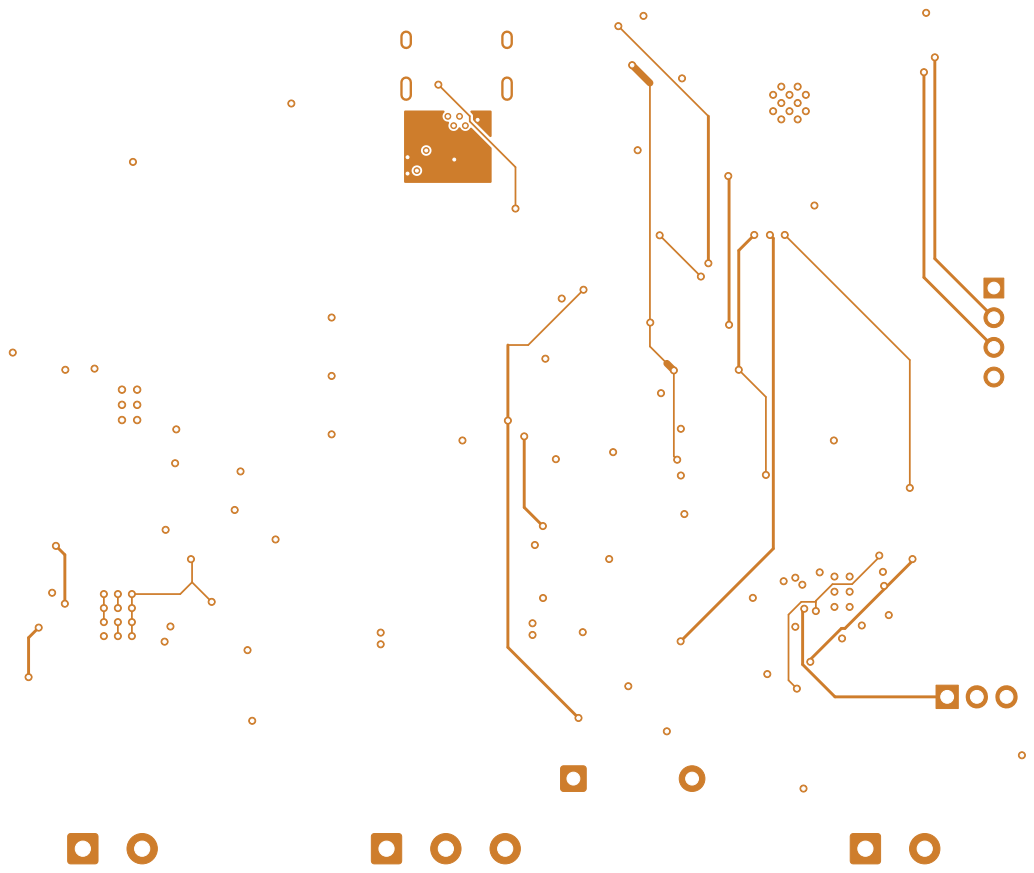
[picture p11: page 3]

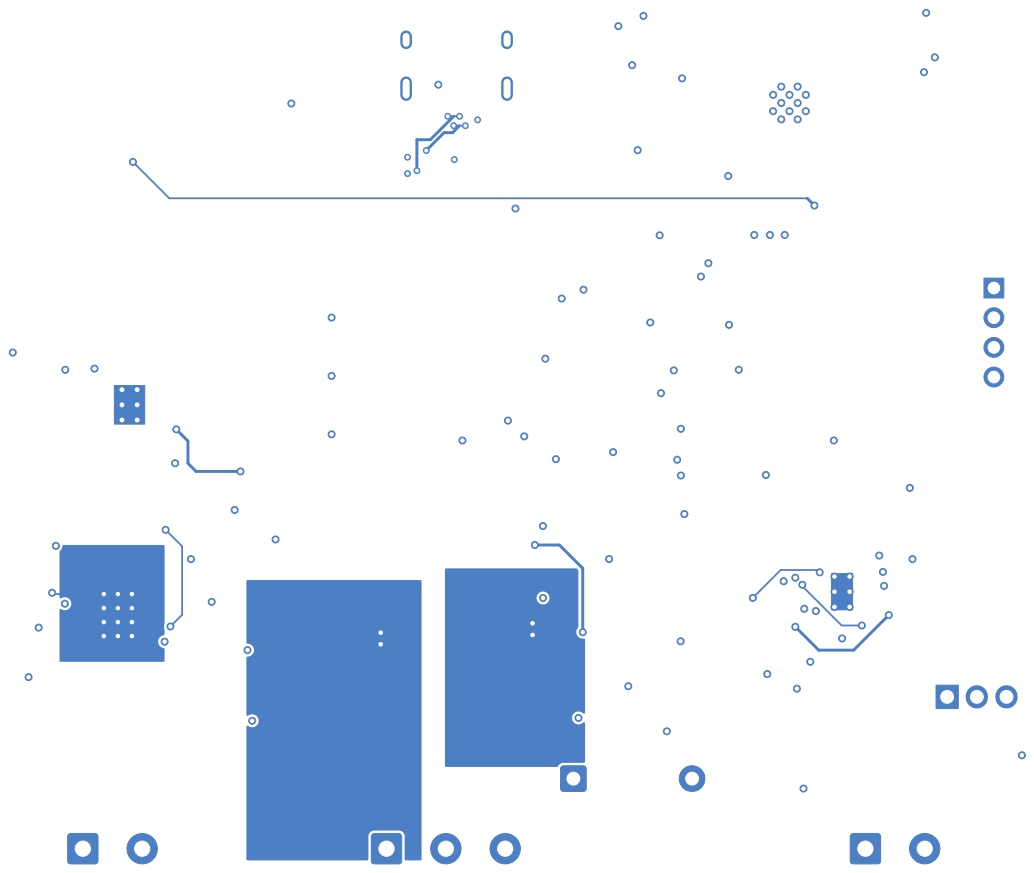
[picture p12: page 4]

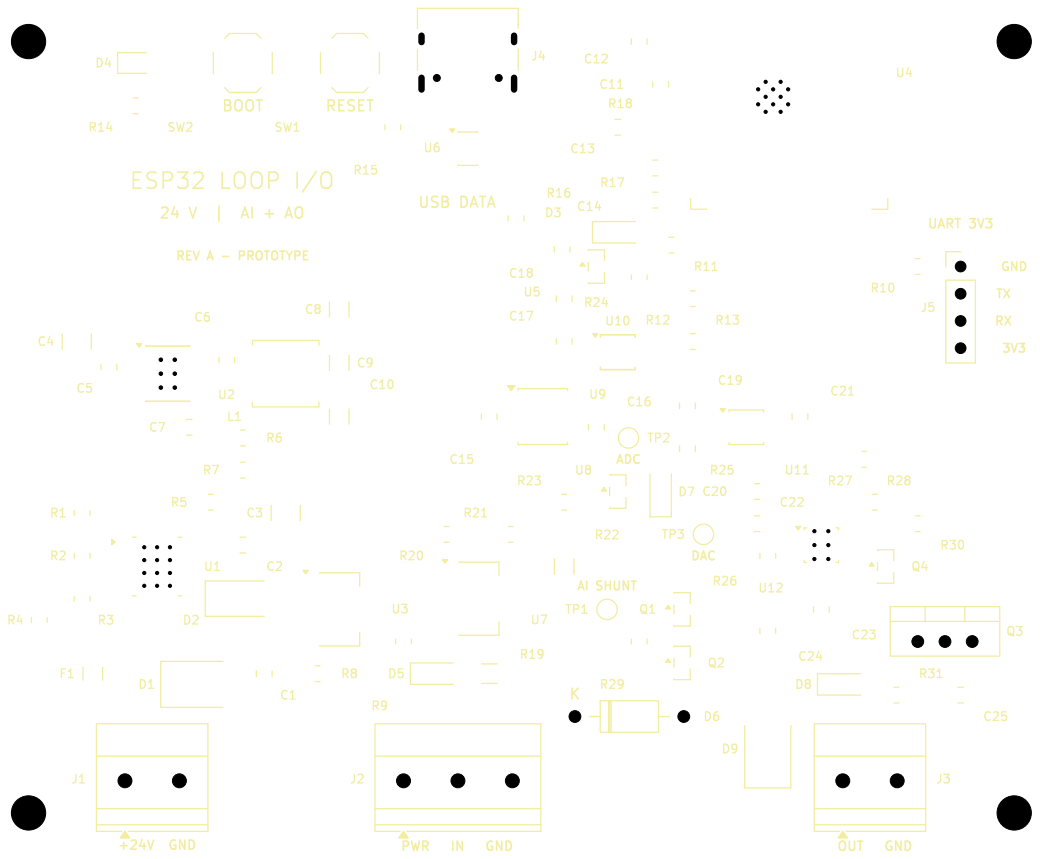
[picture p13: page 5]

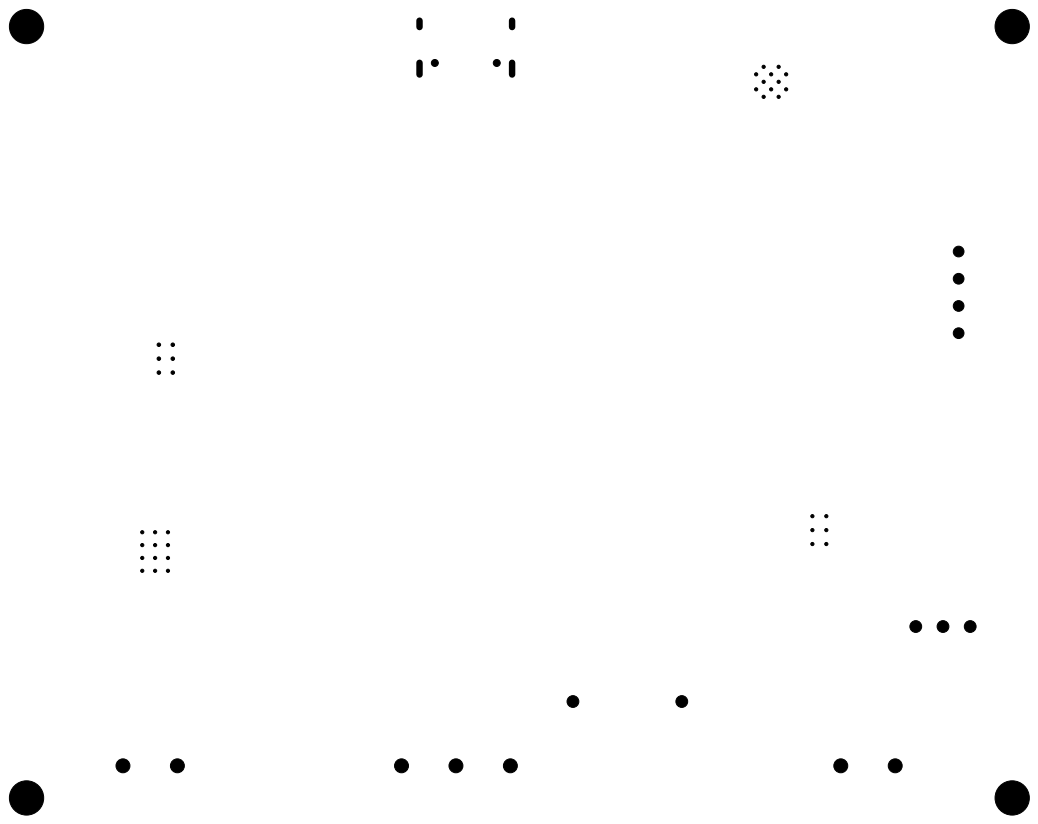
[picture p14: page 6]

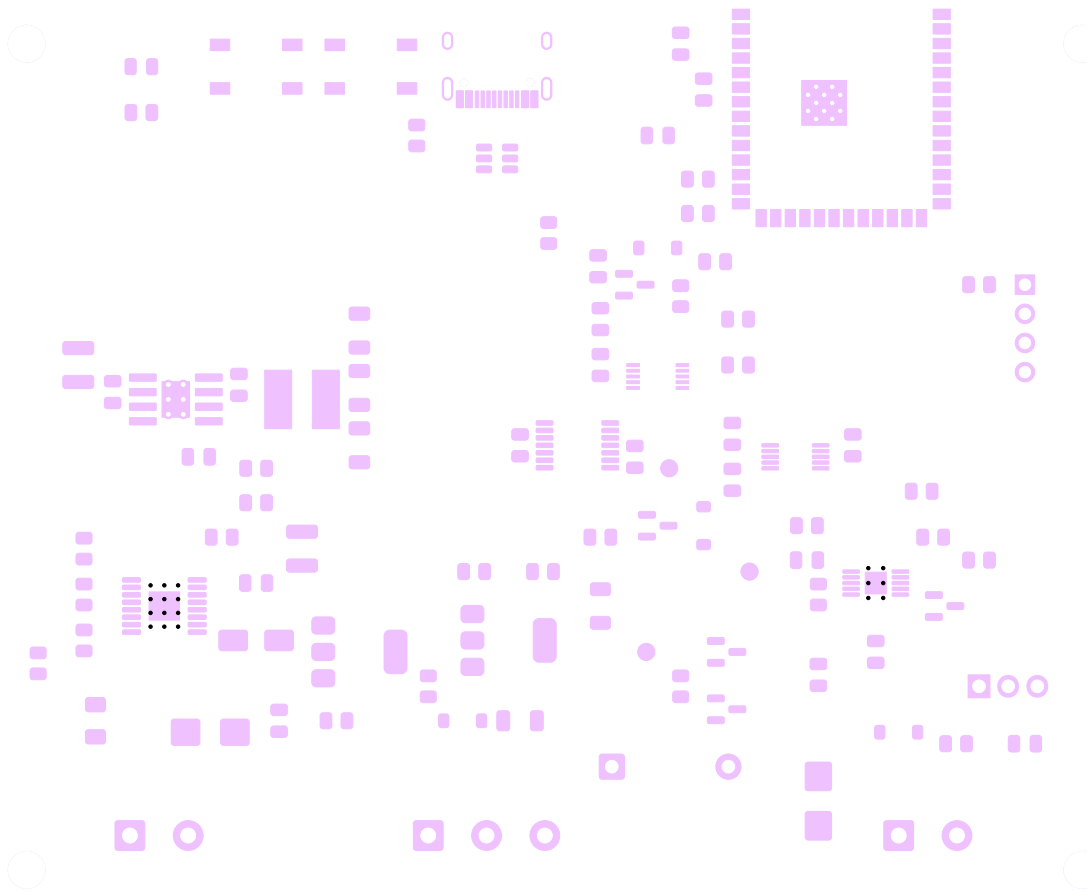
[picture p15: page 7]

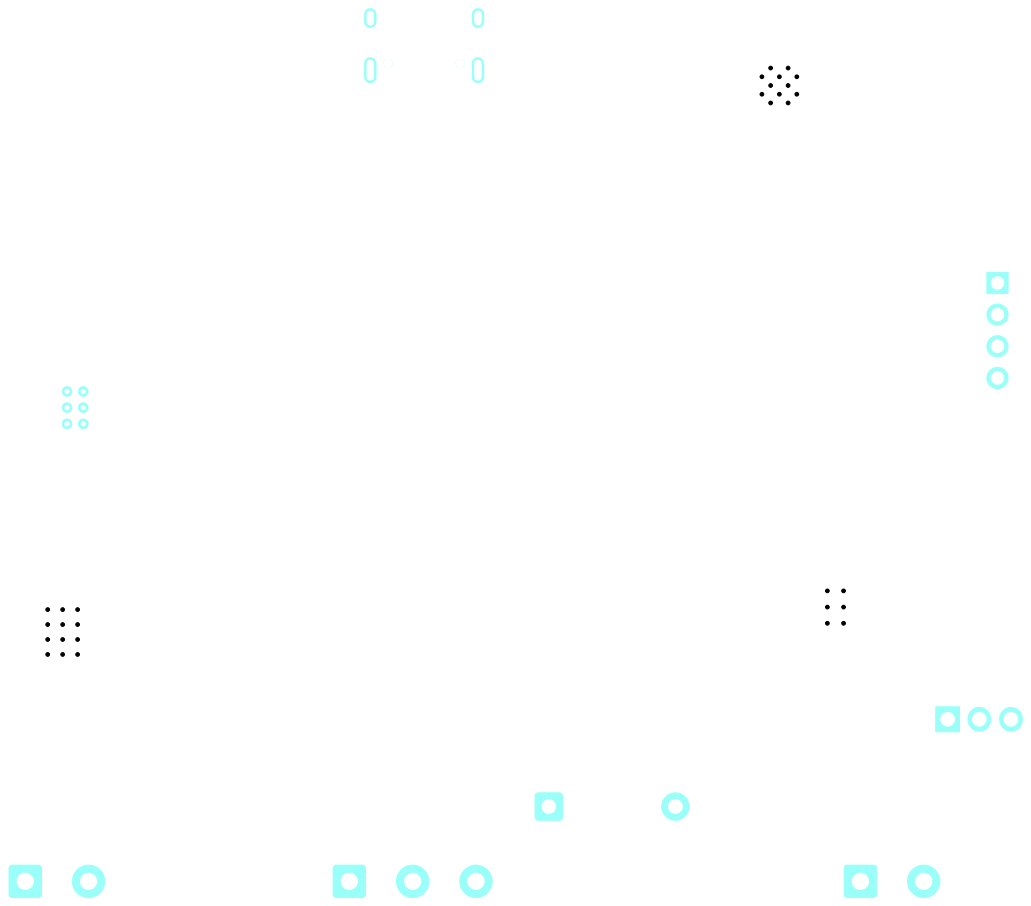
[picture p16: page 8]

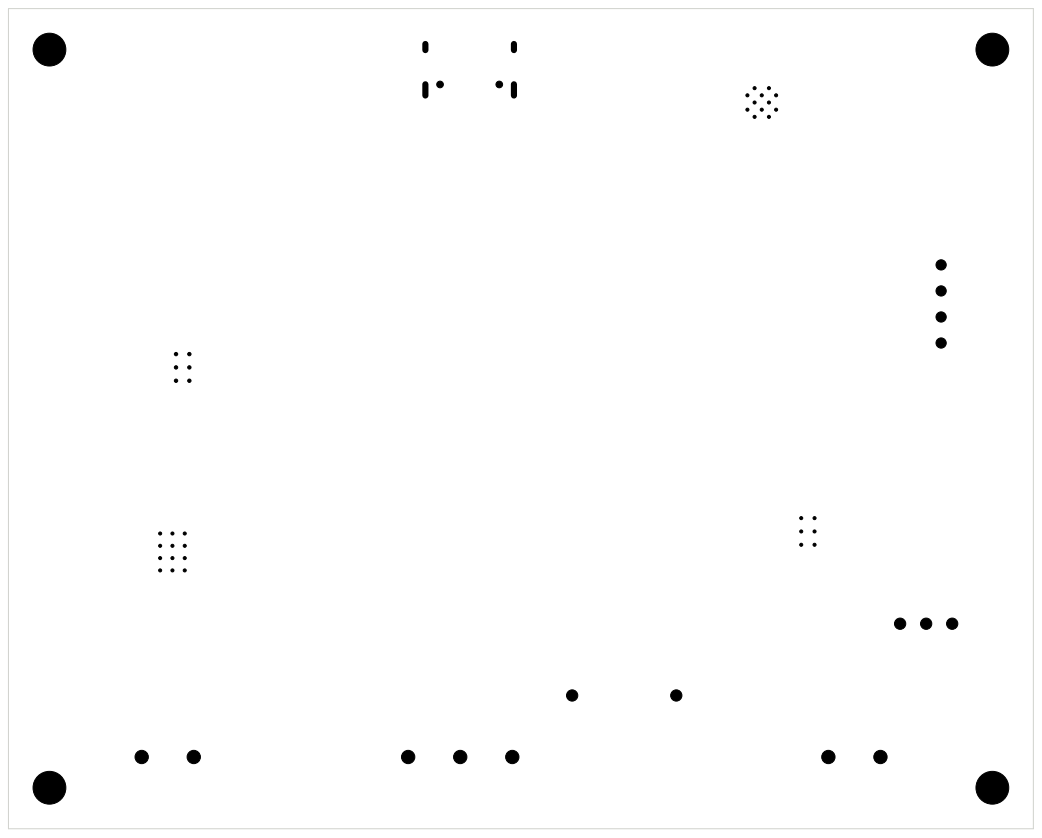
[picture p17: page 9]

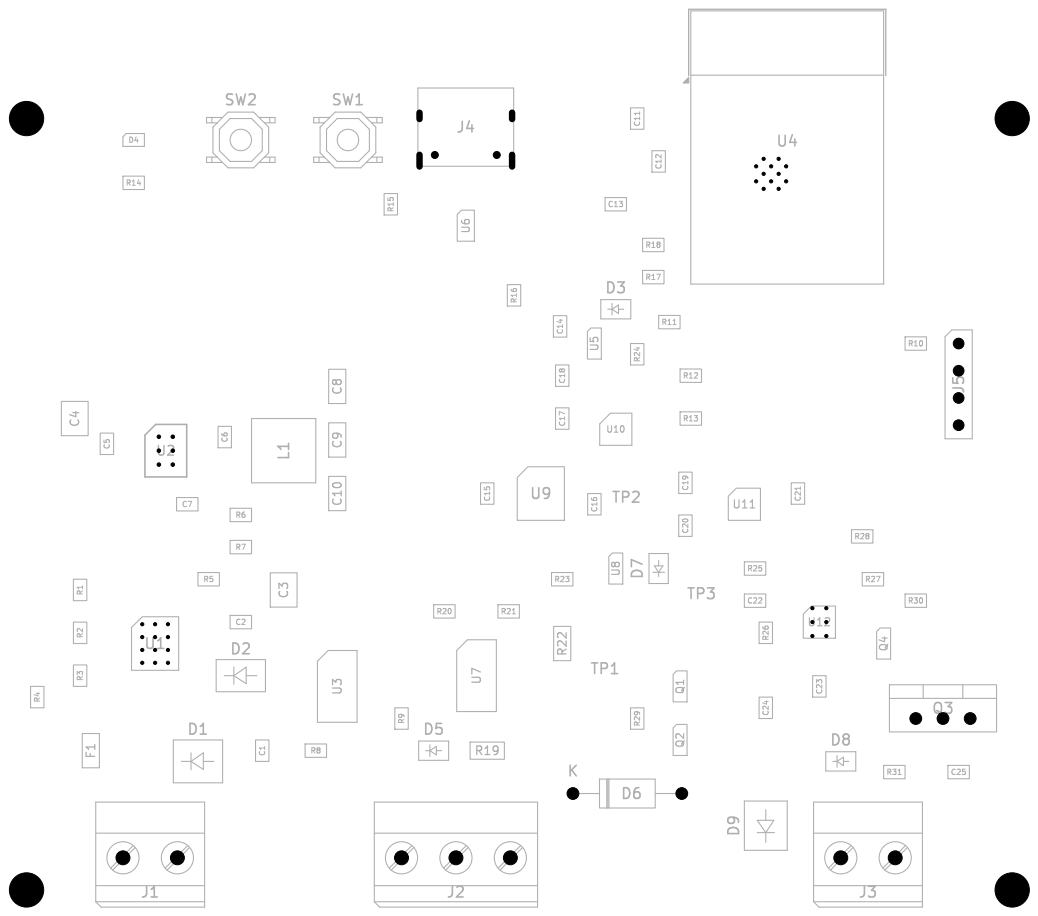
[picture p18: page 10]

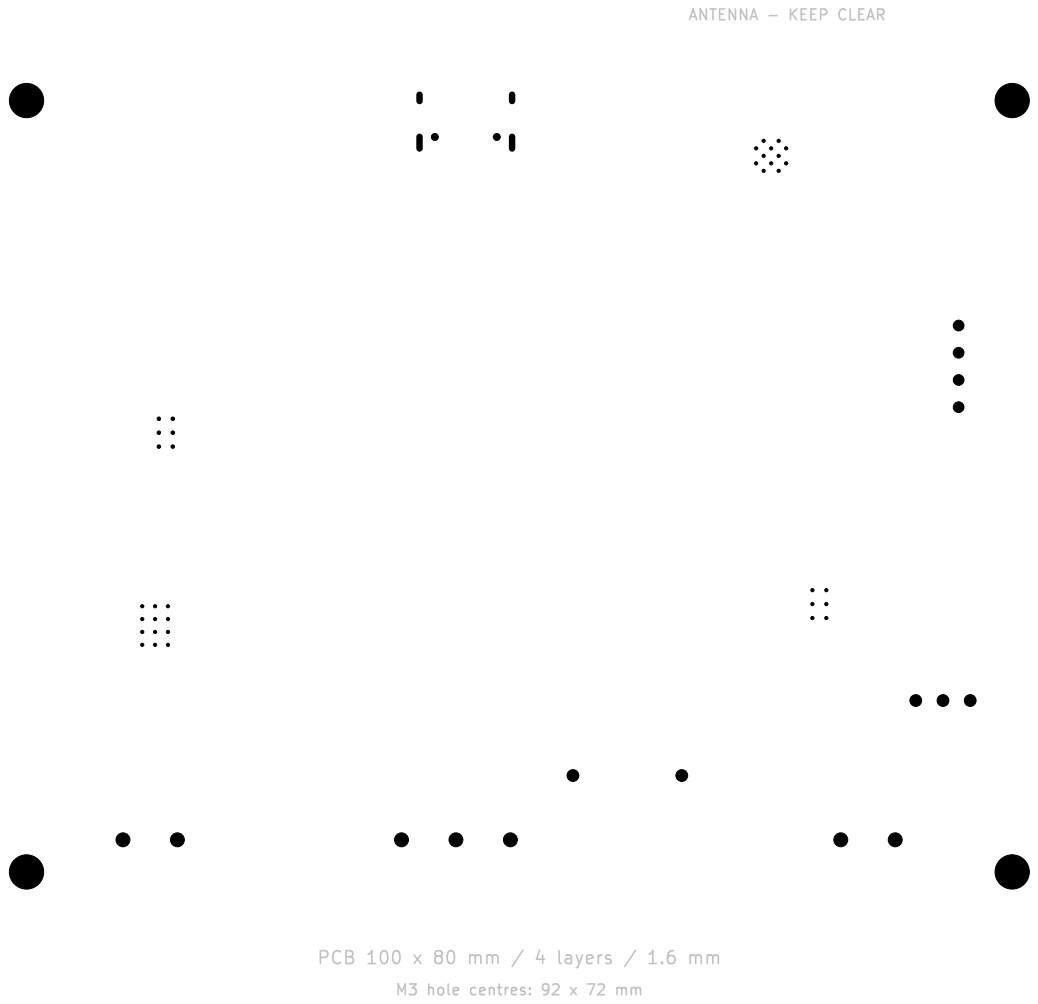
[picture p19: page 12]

PCB 100 x 80 mm / 4 layers / 1.6 mm

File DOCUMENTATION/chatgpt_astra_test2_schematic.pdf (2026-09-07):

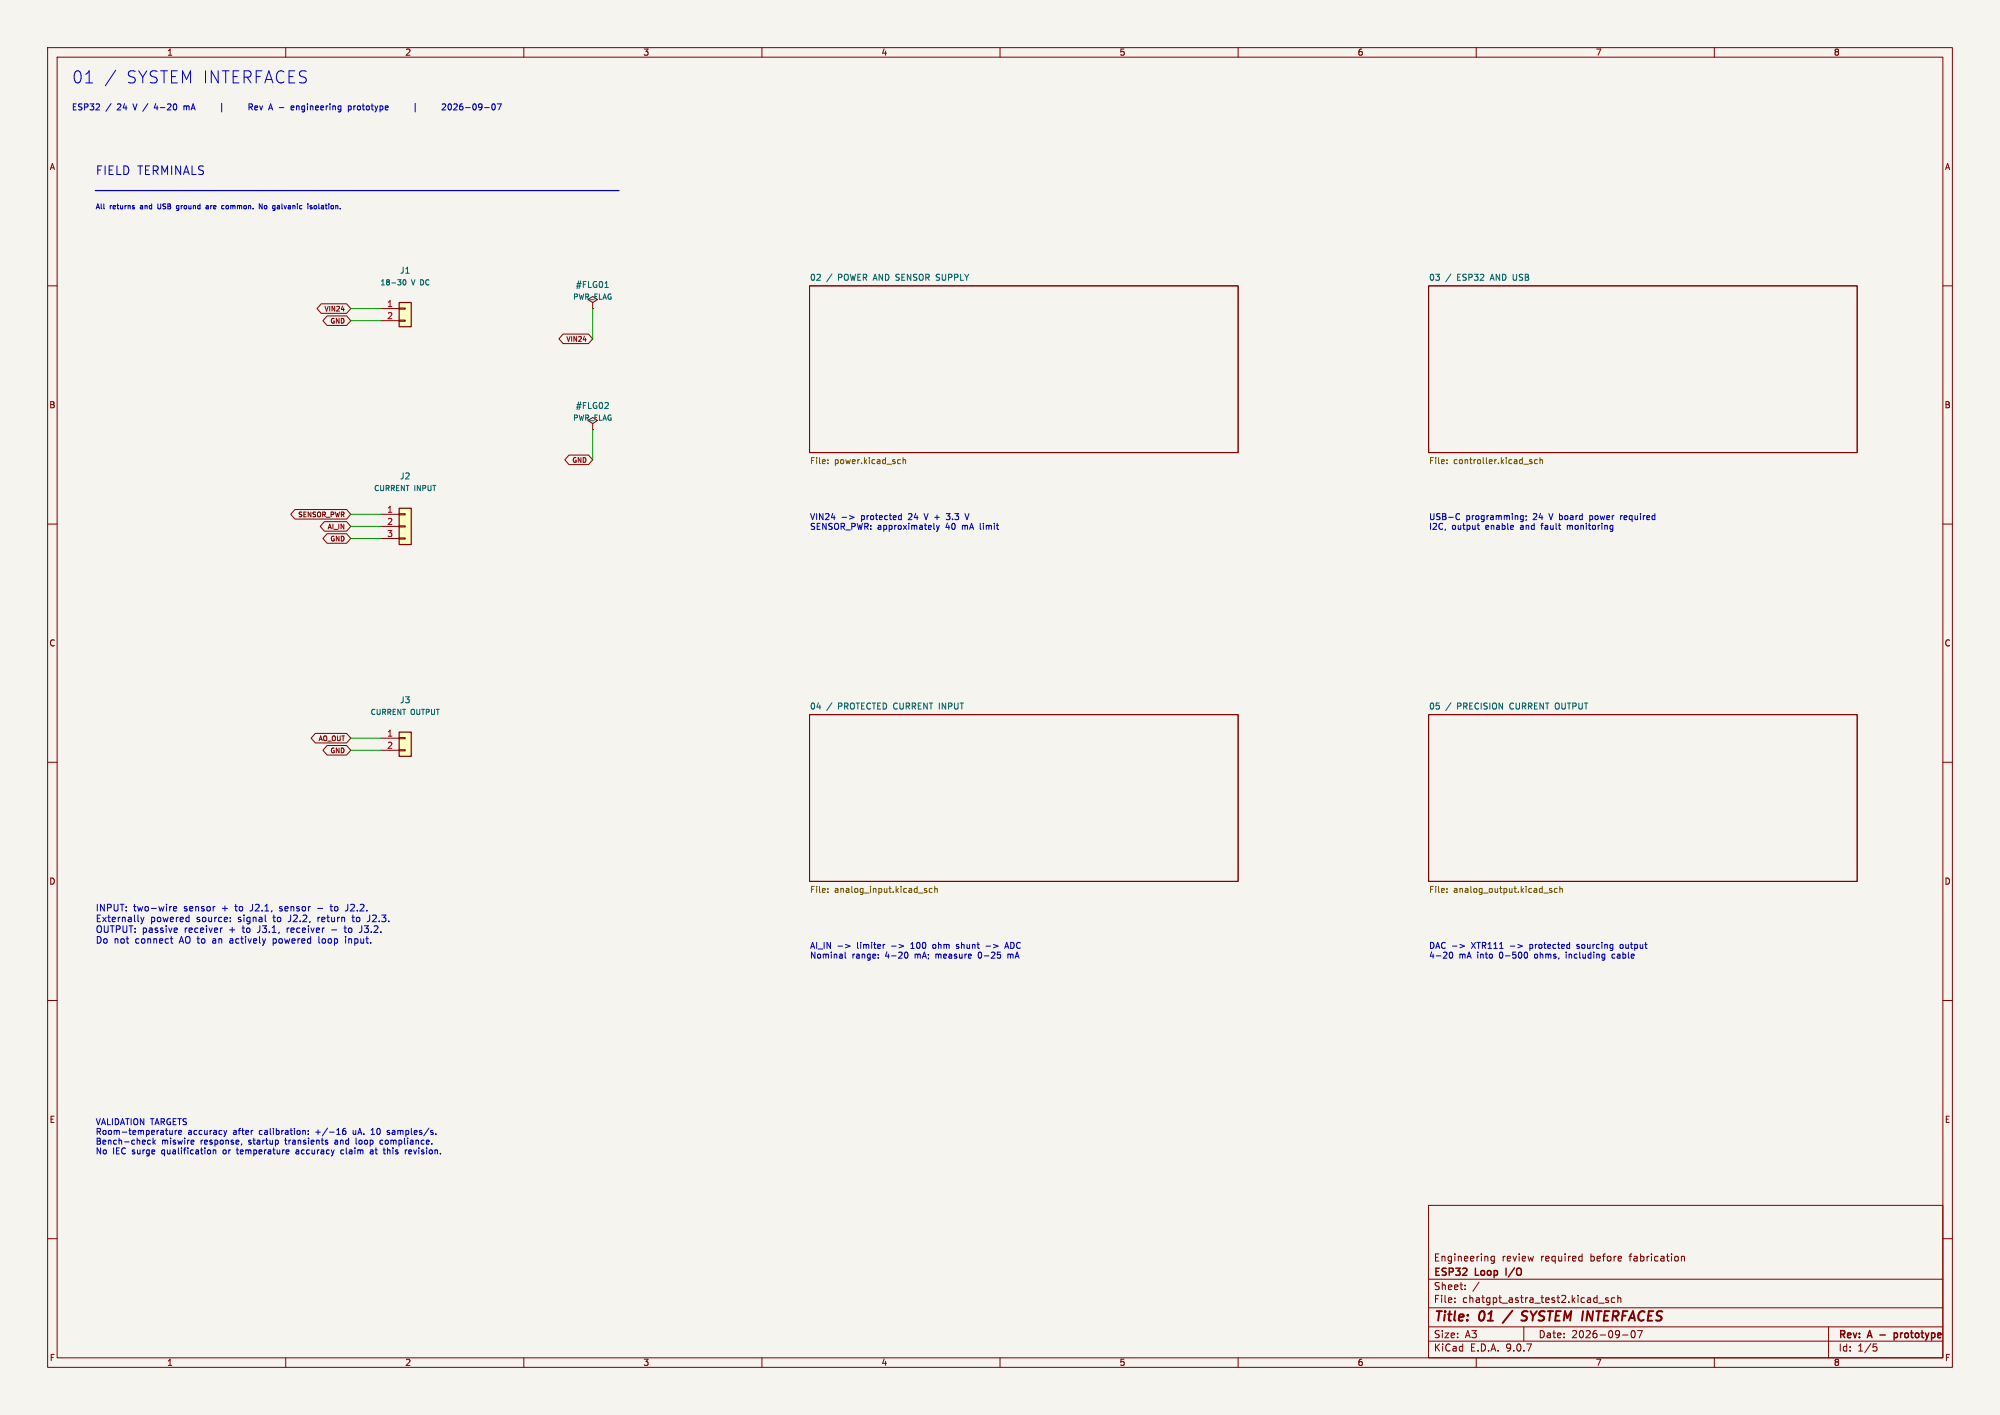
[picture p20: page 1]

02 / POWER AND SENSOR SUPPLY

I2C, output enable and fault monitoring

Id: 1/5 Title: 01 / SYSTEM INTERFACES


02 / POWER AND SENSOR SUPPLY

9 BOOT 7 SW 8 FB 5 PG 4 U2

SENSOR SUPPLY / 40 mA LIMIT

Id: 2/5 Title: 02 / POWER AND SENSOR SUPPLY


J5 UART / 3.3 V ONLY D4 GREEN PSRAM

Id: 3/5 Title: 03 / ESP32 AND USB


Id: 4/5 Title: 04 / PROTECTED CURRENT INPUT


3 2 Q4 MMBT3906 REGF 5 REGS 4 VIN 6 SET 7 VSP

Id: 5/5 Title: 05 / PRECISION CURRENT OUTPUT

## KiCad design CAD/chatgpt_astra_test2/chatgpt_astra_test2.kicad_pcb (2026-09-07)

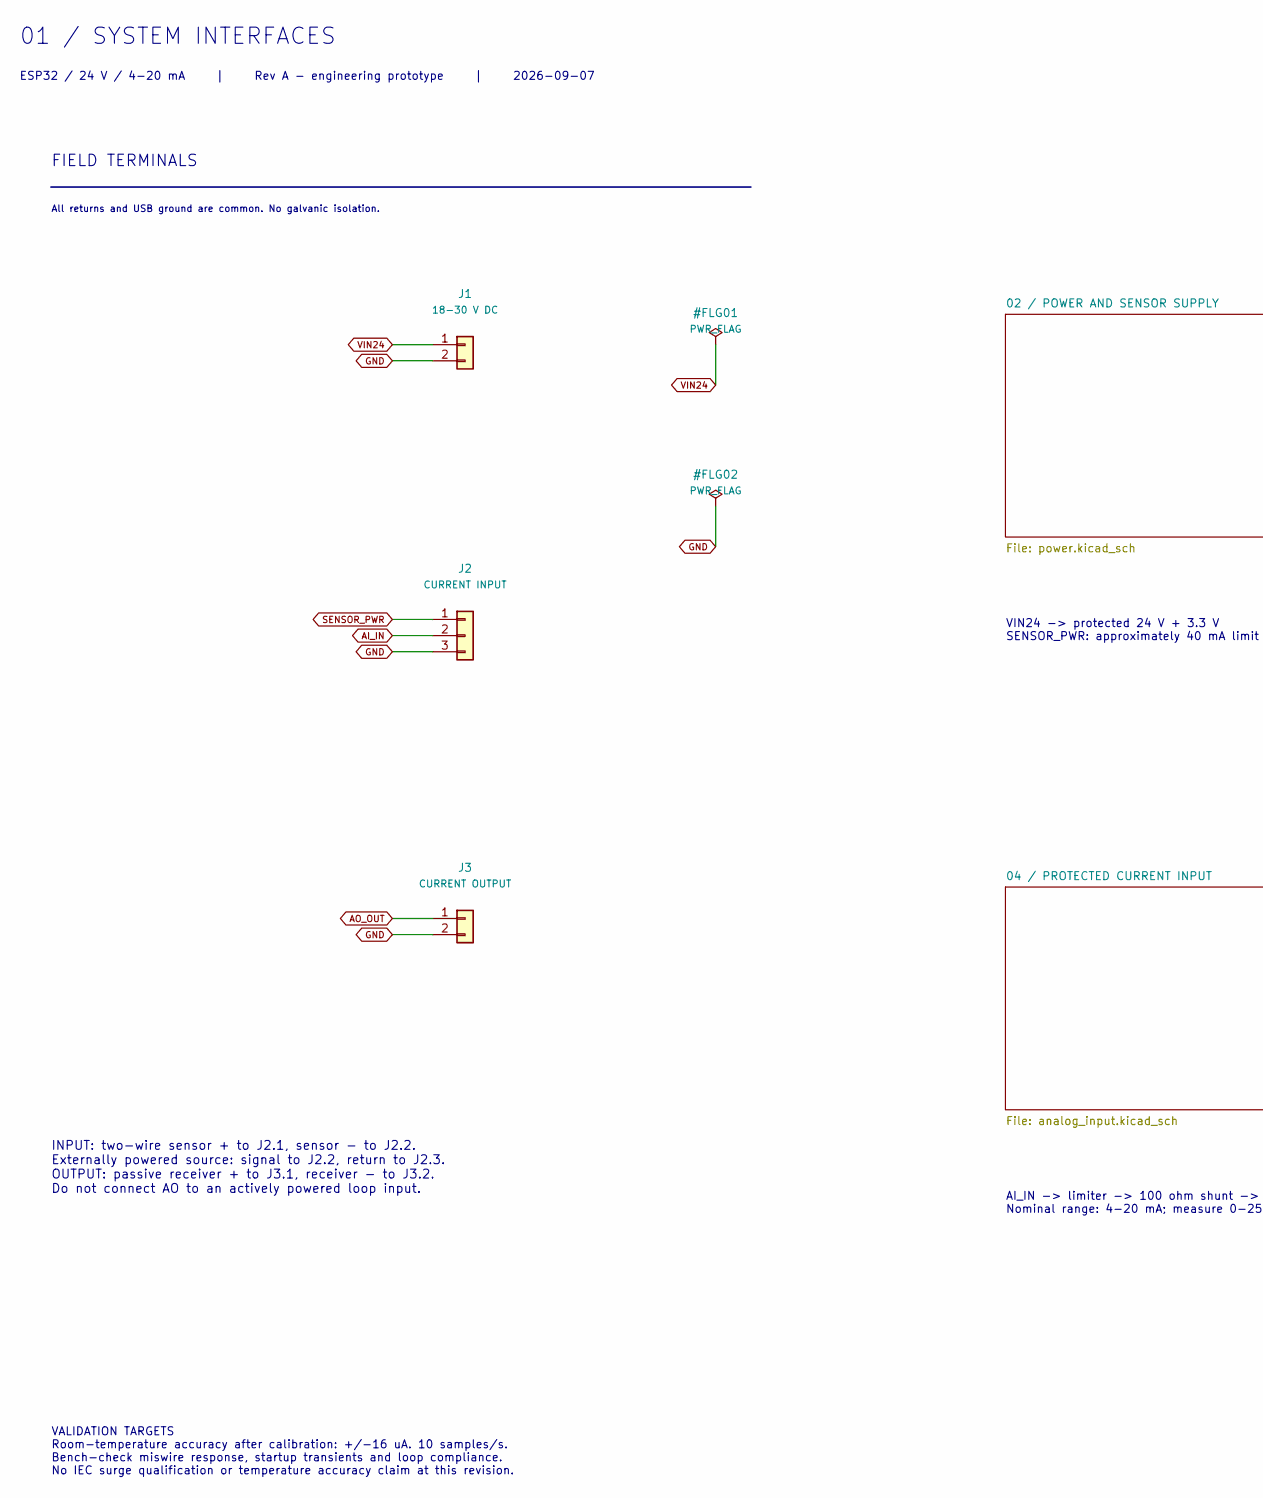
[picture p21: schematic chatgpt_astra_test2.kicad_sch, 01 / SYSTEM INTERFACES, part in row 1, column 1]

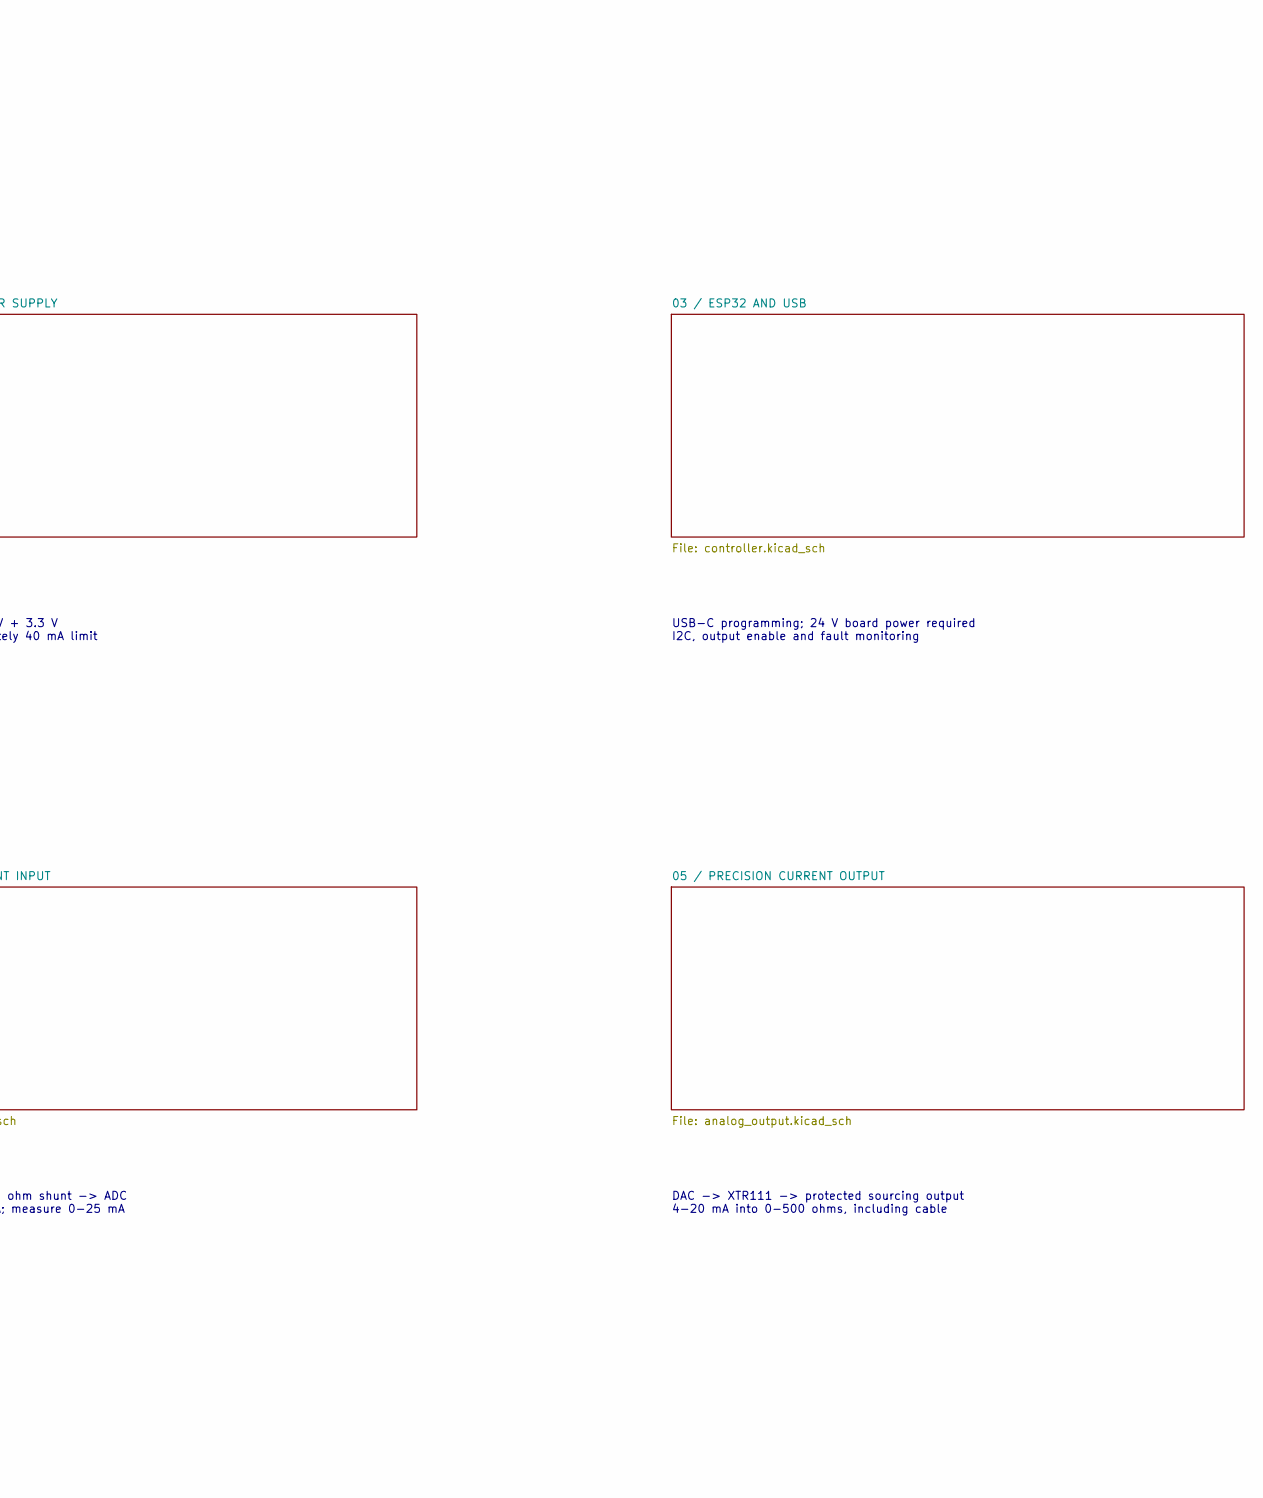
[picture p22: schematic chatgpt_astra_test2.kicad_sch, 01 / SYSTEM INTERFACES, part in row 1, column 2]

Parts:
J1: 18-30 V DC; TerminalBlock_Phoenix_MKDS-1,5-2-5.08_1x02_P5.08mm_Horizont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
J2: CURRENT INPUT; TerminalBlock_Phoenix_MKDS-1,5-3-5.08_1x03_P5.08mm_Horizont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
J3: CURRENT OUTPUT; TerminalBlock_Phoenix_MKDS-1,5-2-5.08_1x02_P5.08mm_Horizont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

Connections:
AI_IN: J2.2; also elsewhere on the board
AO_OUT: J3.1; also elsewhere on the board
GND: J1.2, J2.3, J3.2; also elsewhere on the board
SENSOR_PWR: J2.1; also elsewhere on the board
VIN24: J1.1; also elsewhere on the board

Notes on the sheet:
01 / SYSTEM INTERFACES
ESP32 / 24 V / 4-20 mA | Rev A - engineering prototype | 2026-09-07
FIELD TERMINALS
All returns and USB ground are common. No galvanic isolation.
INPUT: two-wire sensor + to J2.1, sensor - to J2.2. Externally powered source: signal to J2.2, return to J2.3. OUTPUT: passive receiver + to J3.1, receiver - to J3.2. Do not connect AO to an actively powered loop input.
VIN24 -> protected 24 V + 3.3 V SENSOR_PWR: approximately 40 mA limit
USB-C programming; 24 V board power required I2C, output enable and fault monitoring
AI_IN -> limiter -> 100 ohm shunt -> ADC Nominal range: 4-20 mA; measure 0-25 mA
DAC -> XTR111 -> protected sourcing output 4-20 mA into 0-500 ohms, including cable
VALIDATION TARGETS Room-temperature accuracy after calibration: +/-16 uA. 10 samples/s. Bench-check miswire response, startup transients and loop compliance. No IEC surge qualification or temperature accuracy claim at this revision.

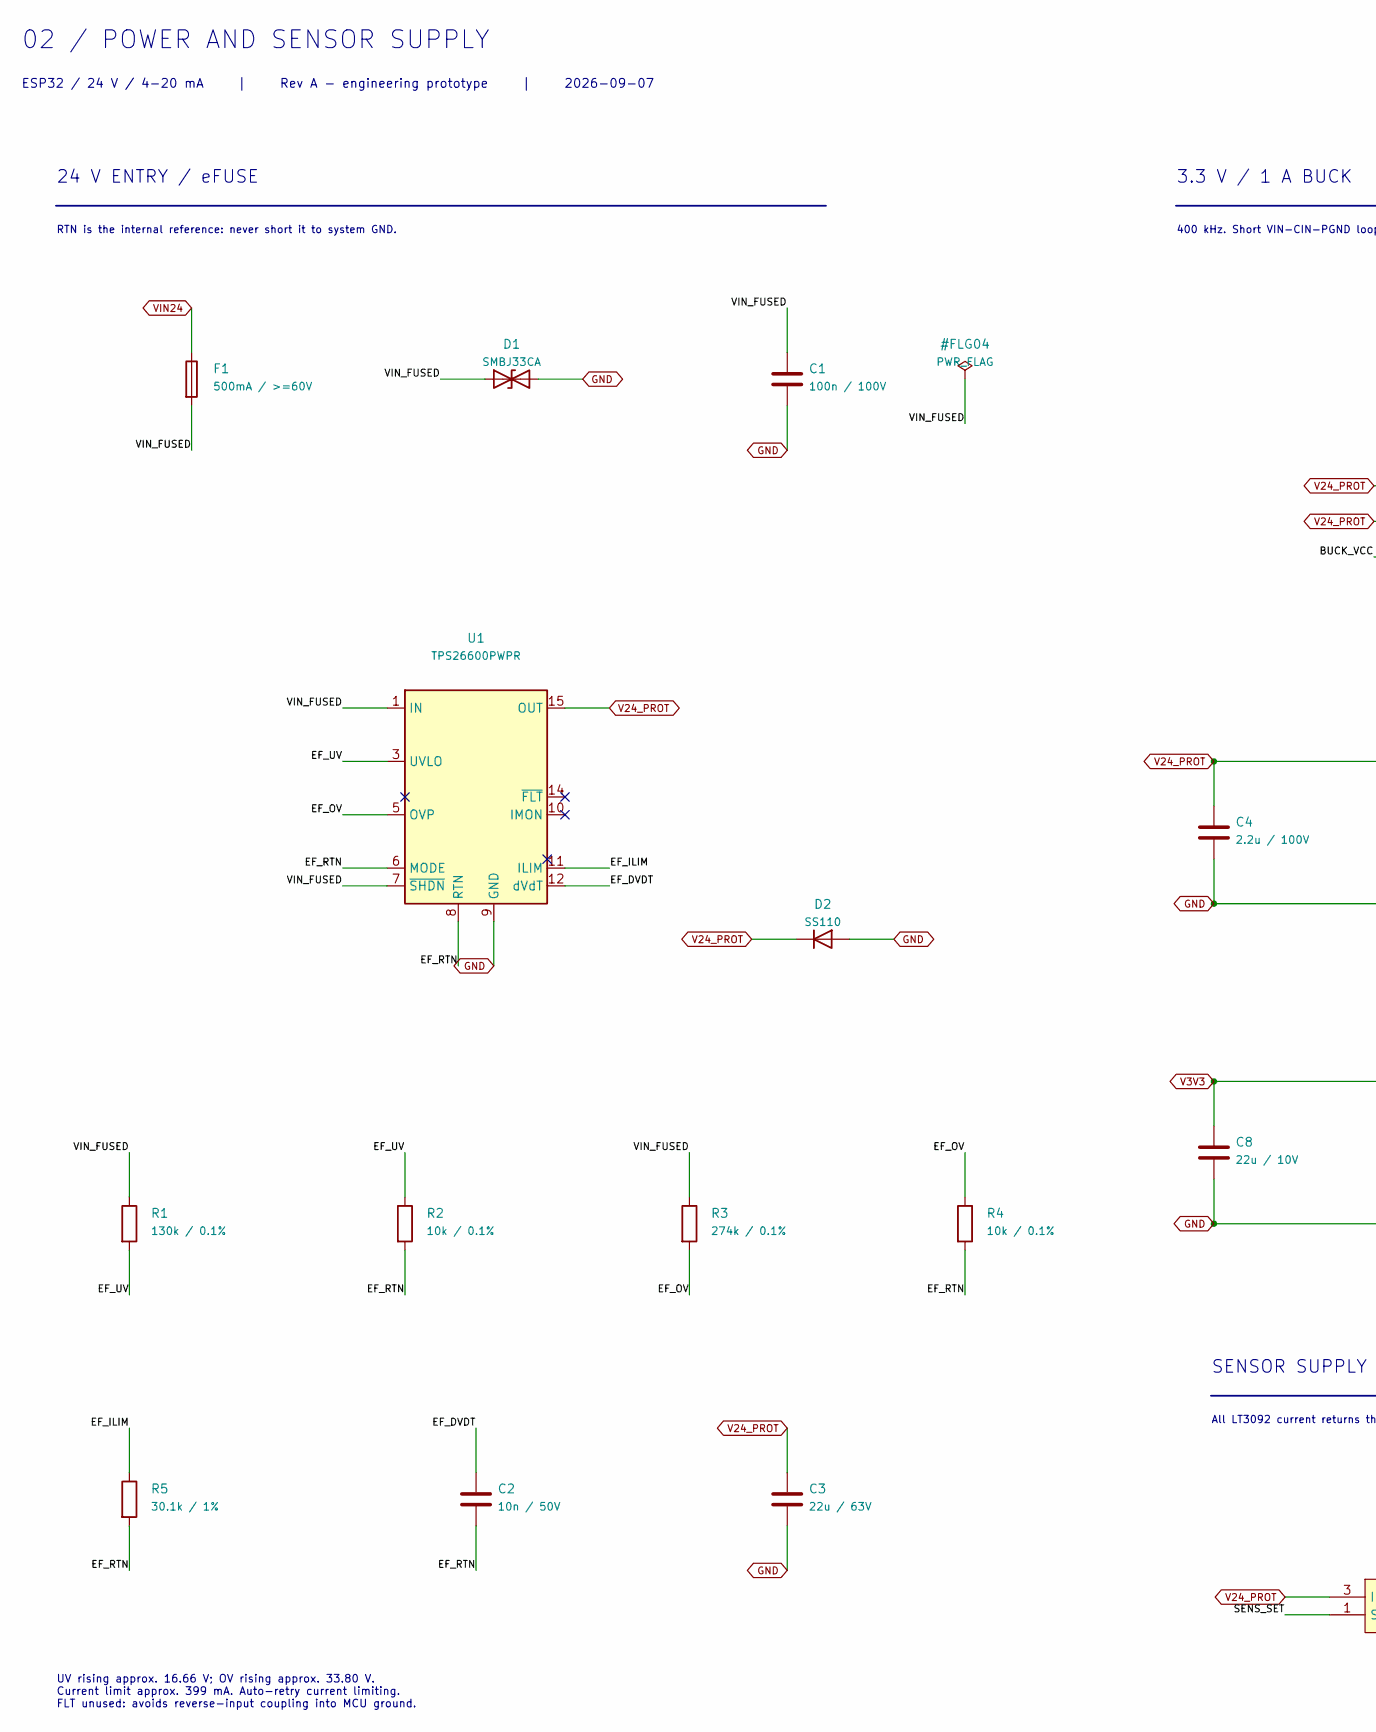
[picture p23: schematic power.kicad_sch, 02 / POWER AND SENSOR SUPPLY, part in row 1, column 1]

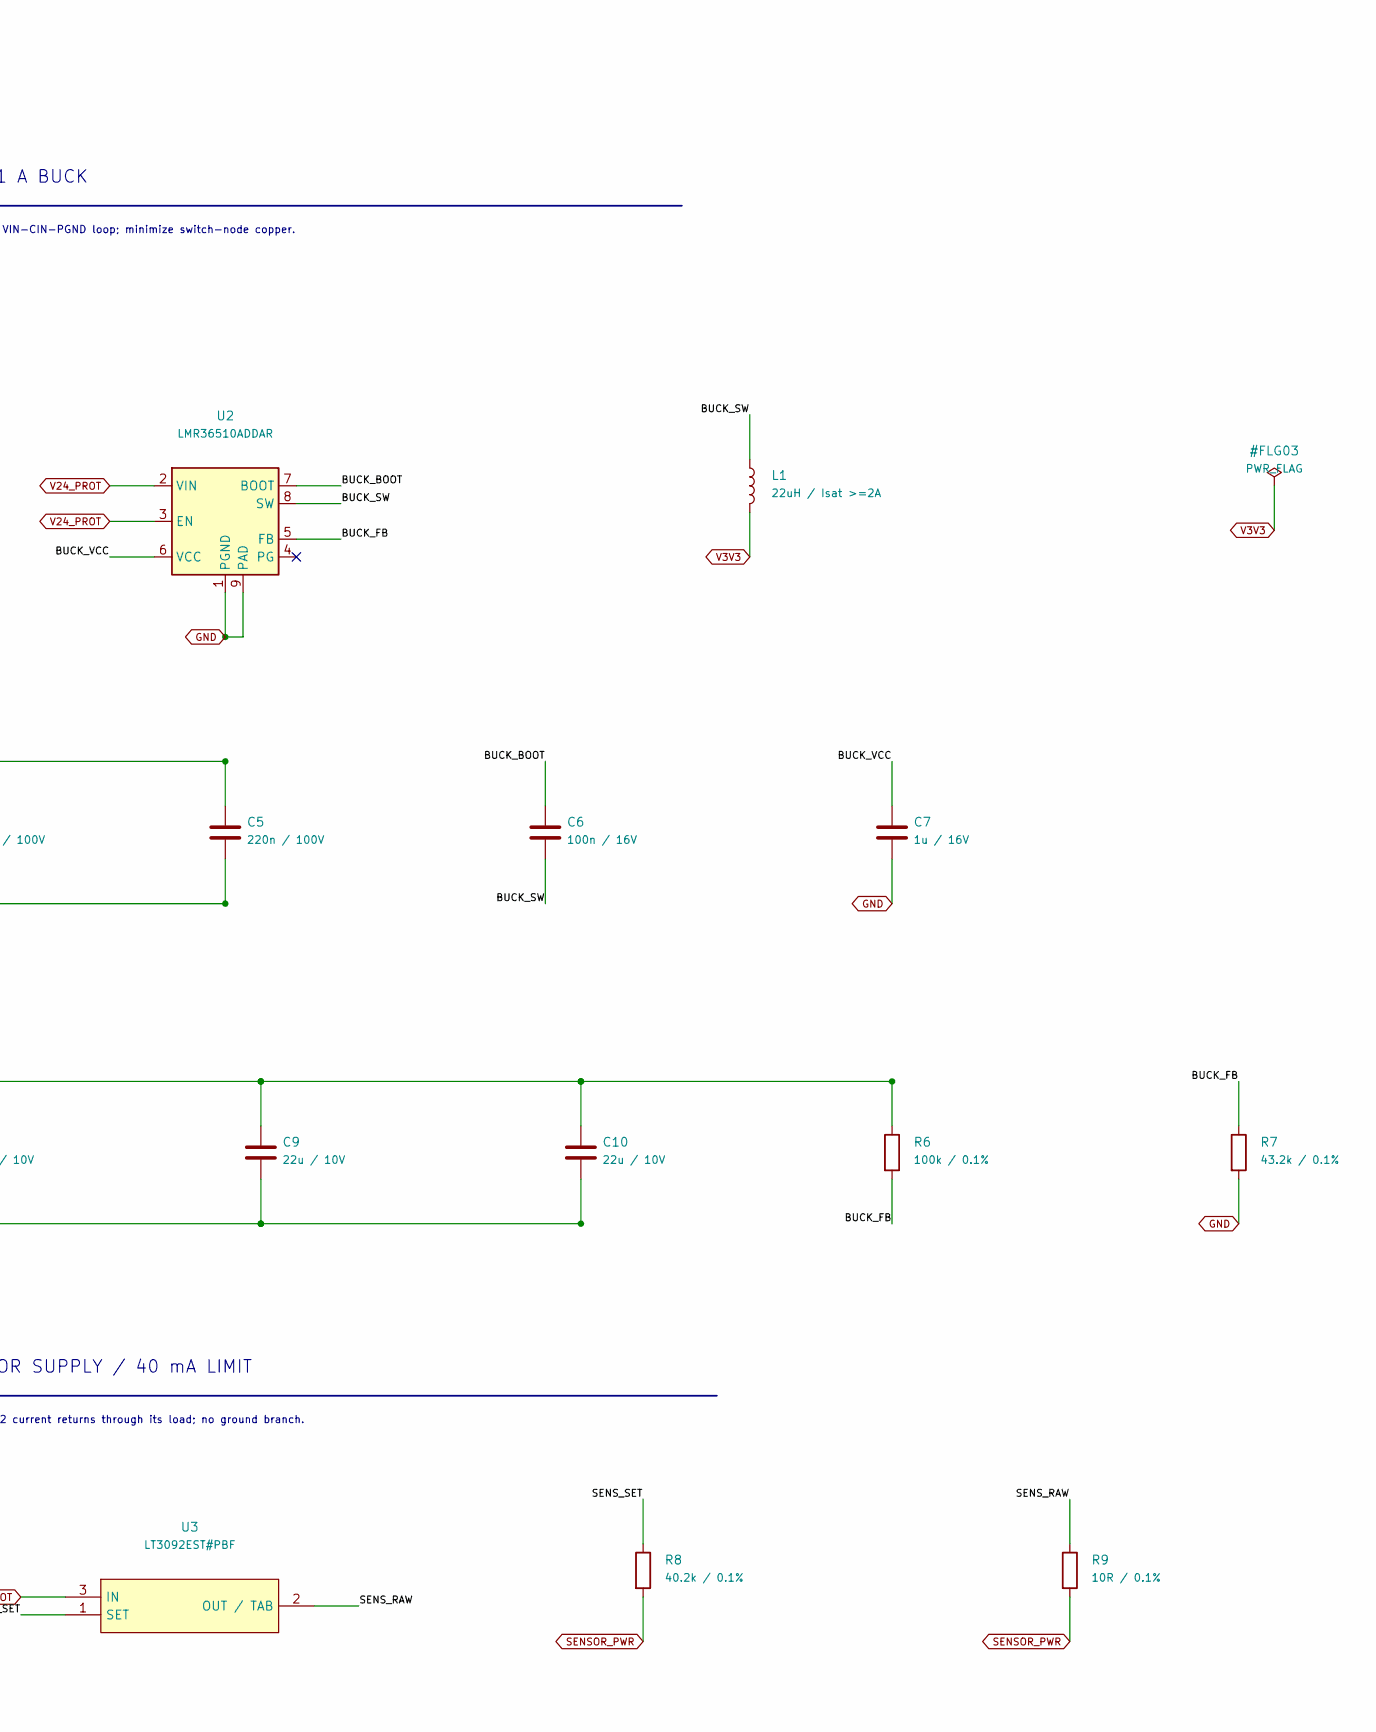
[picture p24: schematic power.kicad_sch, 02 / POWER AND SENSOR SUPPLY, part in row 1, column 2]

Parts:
C1: 100n / 100V; C_0805_2012Metric
C2: 10n / 50V; C_0805_2012Metric
C3: 22u / 63V; C_1210_3225Metric
C4: 2.2u / 100V; C_1210_3225Metric
C5: 220n / 100V; C_0805_2012Metric
C6: 100n / 16V; C_0805_2012Metric
C7: 1u / 16V; C_0805_2012Metric
C8, C9, C10: 22u / 10V; C_1206_3216Metric
D1: SMBJ33CA; D_SMB
D2: SS110; D_SMA
F1: 500mA / >=60V; Fuse_1206_3216Metric
L1: 22uH / Isat >=2A; L_Bourns_SRN6045TA
R1: 130k / 0.1%; R_0805_2012Metric
R2, R4: 10k / 0.1%; R_0805_2012Metric
R3: 274k / 0.1%; R_0805_2012Metric
R5: 30.1k / 1%; R_0805_2012Metric
R6: 100k / 0.1%; R_0805_2012Metric
R7: 43.2k / 0.1%; R_0805_2012Metric
R8: 40.2k / 0.1%; R_0805_2012Metric
R9: 10R / 0.1%; R_0805_2012Metric
U1: TPS26600PWPR; HTSSOP-16-1EP_4.4x5mm_P0.65mm_EP3.4x5mm_Mask2.66x2.46mm_The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
U2: LMR36510ADDAR; Texas_HTSOP-8-1EP_3.9x4.9mm_P1.27mm_EP2.95x4.9mm_Mask2.4x3.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
U3: LT3092EST#PBF; SOT-223-3_TabPin2

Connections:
/02 / POWER AND SENSOR SUPPLY/BUCK_BOOT: C6.1, U2.7 (BOOT)
/02 / POWER AND SENSOR SUPPLY/BUCK_FB: R6.2, R7.1, U2.5 (FB)
/02 / POWER AND SENSOR SUPPLY/BUCK_SW: C6.2, L1.1, U2.8 (SW)
/02 / POWER AND SENSOR SUPPLY/BUCK_VCC: C7.1, U2.6 (VCC)
/02 / POWER AND SENSOR SUPPLY/EF_DVDT: C2.1, U1.12 (dVdT)
/02 / POWER AND SENSOR SUPPLY/EF_ILIM: R5.1, U1.11 (ILIM)
/02 / POWER AND SENSOR SUPPLY/EF_OV: R3.2, R4.1, U1.5 (OVP)
/02 / POWER AND SENSOR SUPPLY/EF_RTN: C2.2, R2.2, R4.2, R5.2, U1.6 (MODE), U1.8 (RTN), U1.17 (RTN)
/02 / POWER AND SENSOR SUPPLY/EF_UV: R1.2, R2.1, U1.3 (UVLO)
/02 / POWER AND SENSOR SUPPLY/SENS_RAW: R9.1, U3.2 (OUT / TAB)
/02 / POWER AND SENSOR SUPPLY/SENS_SET: R8.1, U3.1 (SET)
/02 / POWER AND SENSOR SUPPLY/VIN_FUSED: C1.1, D1.1 (A1), F1.2, R1.1, R3.1, U1.1 (IN), U1.2 (IN), U1.7 (~SHDN)
GND: C1.2, C3.2, C4.2, C5.2, C7.2, C8.2, C9.2, C10.2, D1.2 (A2), D2.2 (A), R7.2, U1.9 (GND), U2.1 (PGND), U2.9 (PAD); also elsewhere on the board
SENSOR_PWR: R8.2, R9.2; also elsewhere on the board
V3V3: C8.1, C9.1, C10.1, L1.2, R6.1; also elsewhere on the board
V24_PROT: C3.1, C4.1, C5.1, D2.1 (K), U1.15 (OUT), U1.16 (OUT), U2.2 (VIN), U2.3 (EN), U3.3 (IN); also elsewhere on the board
VIN24: F1.1; also elsewhere on the board

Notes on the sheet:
02 / POWER AND SENSOR SUPPLY
ESP32 / 24 V / 4-20 mA | Rev A - engineering prototype | 2026-09-07
24 V ENTRY / eFUSE
RTN is the internal reference: never short it to system GND.
UV rising approx. 16.66 V; OV rising approx. 33.80 V. Current limit approx. 399 mA. Auto-retry current limiting. FLT unused: avoids reverse-input coupling into MCU ground.
3.3 V / 1 A BUCK
400 kHz. Short VIN-CIN-PGND loop; minimize switch-node copper.
SENSOR SUPPLY / 40 mA LIMIT
All LT3092 current returns through its load; no ground branch.

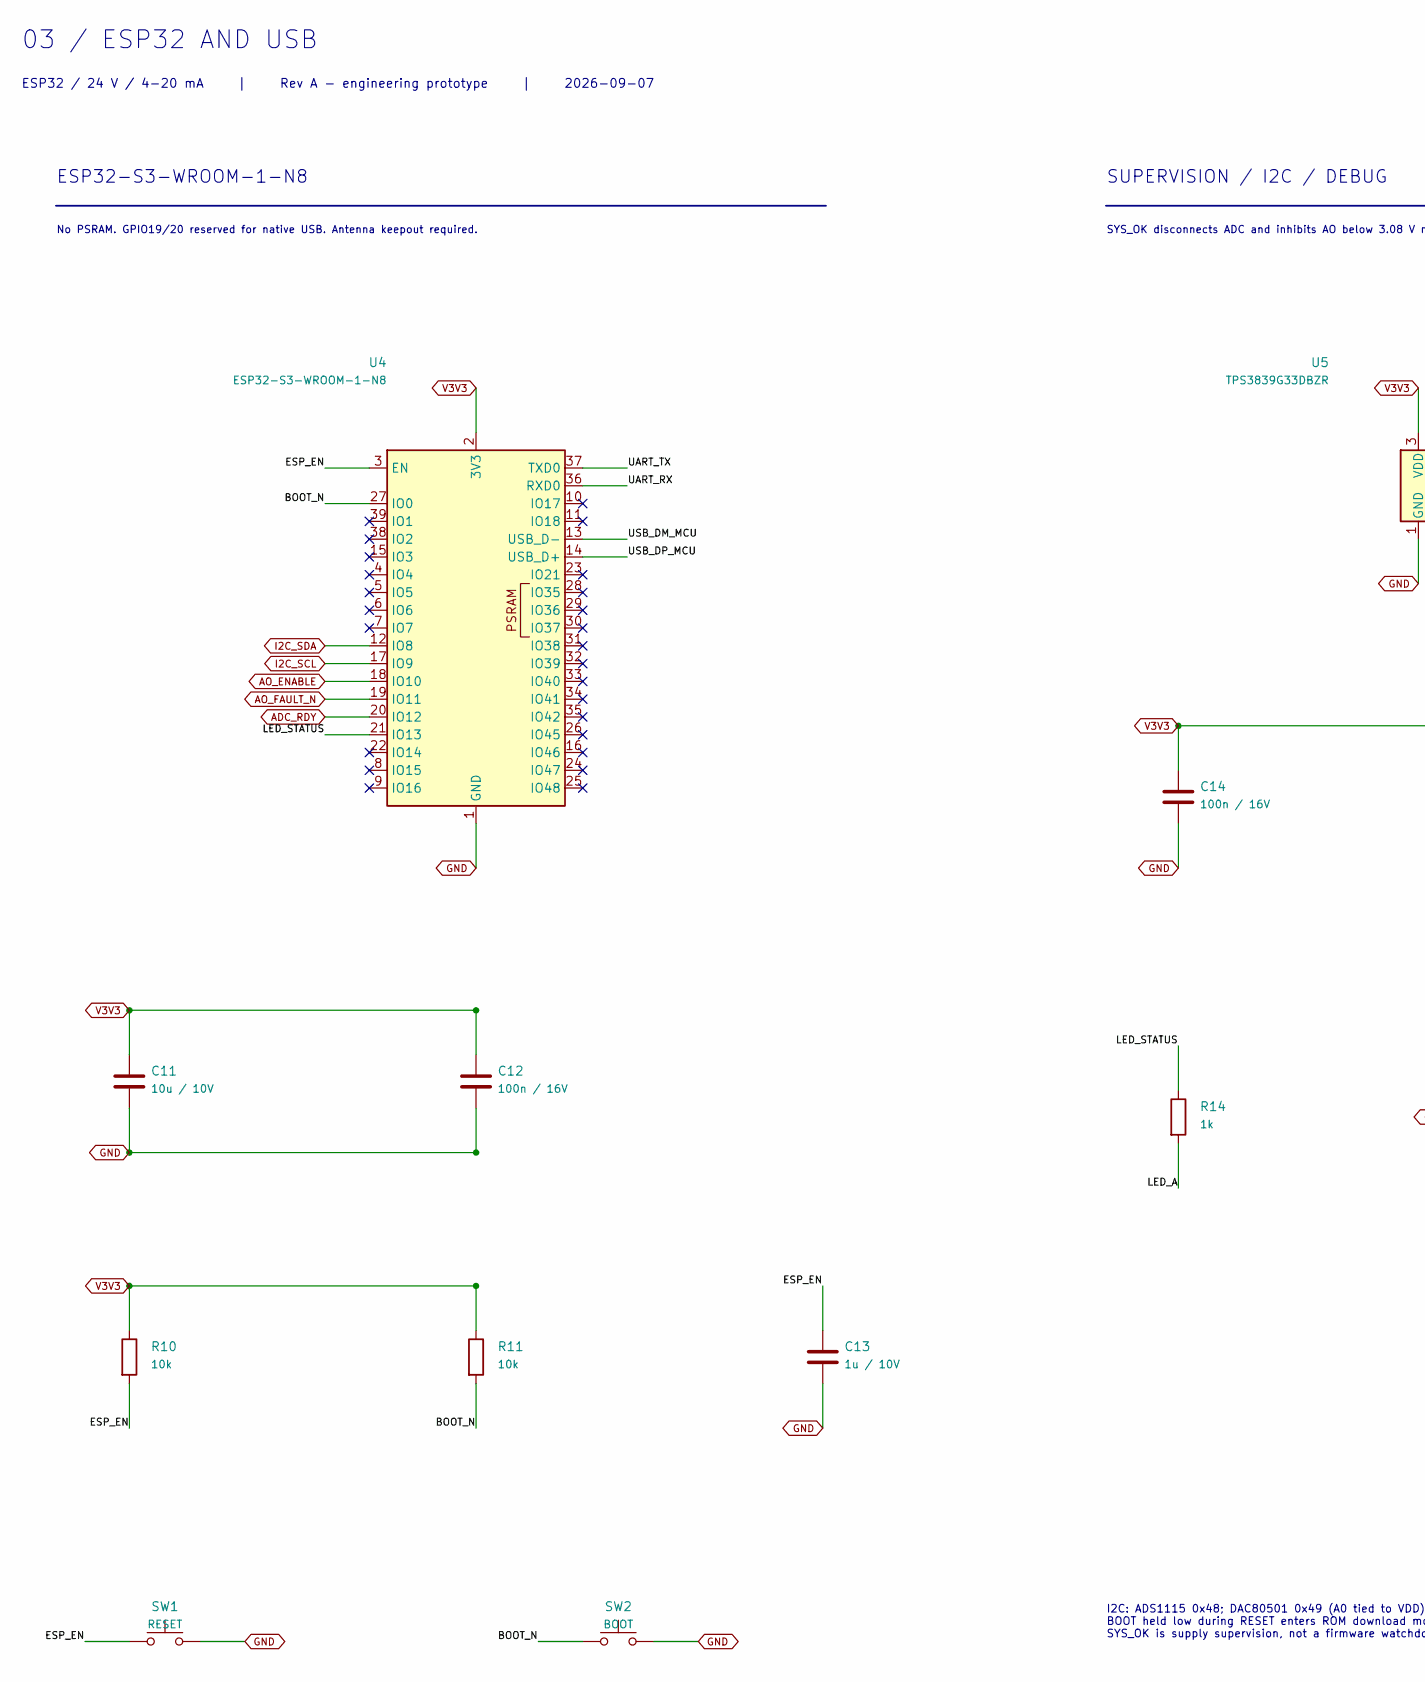
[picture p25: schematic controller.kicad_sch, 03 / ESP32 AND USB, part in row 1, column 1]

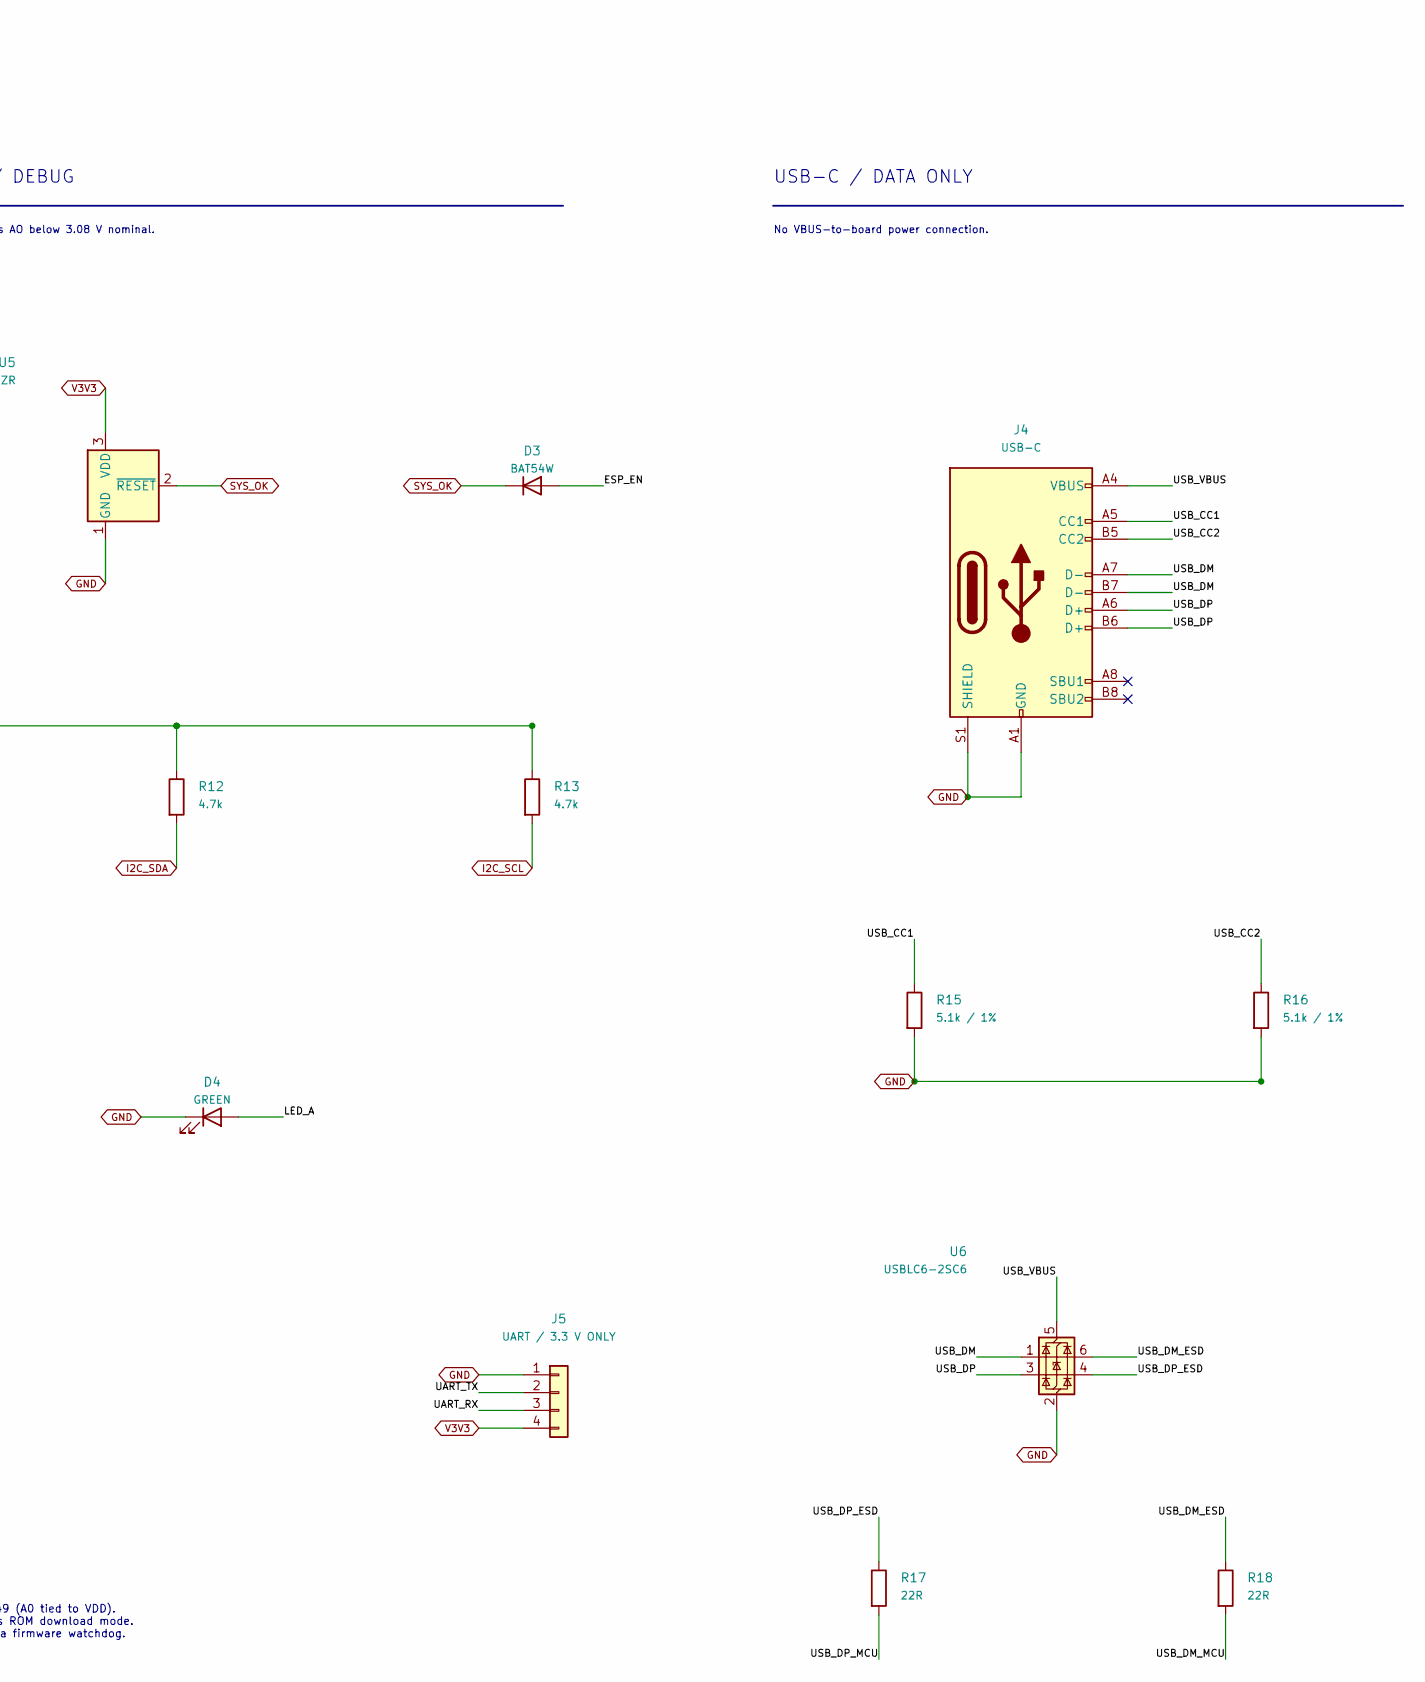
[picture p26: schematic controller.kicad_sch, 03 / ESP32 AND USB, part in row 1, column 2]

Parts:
C11: 10u / 10V; C_0805_2012Metric
C12, C14: 100n / 16V; C_0805_2012Metric
C13: 1u / 10V; C_0805_2012Metric
D3: BAT54W; D_SOD-123
D4: GREEN; LED_0805_2012Metric
J4: USB-C; USB_C_Receptacle_HRO_TYPE-C-31-M-12
J5: UART / 3.3 V ONLY; PinHeader_1x04_P2.54mm_Vertical
R10, R11: 10k; R_0805_2012Metric
R12, R13: 4.7k; R_0805_2012Metric
R14: 1k; R_0805_2012Metric
R15, R16: 5.1k / 1%; R_0805_2012Metric
R17, R18: 22R; R_0805_2012Metric
SW1: RESET; SW_SPST_TL3342
SW2: BOOT; SW_SPST_TL3342
U4: ESP32-S3-WROOM-1-N8; ESP32-S3-WROOM-1
U5: TPS3839G33DBZR; SOT-23
U6: USBLC6-2SC6; SOT-23-6

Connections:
/03 / ESP32 AND USB/BOOT_N: R11.2, SW2.1, U4.27 (IO0)
/03 / ESP32 AND USB/ESP_EN: C13.1, D3.2 (A), R10.2, SW1.1, U4.3 (EN)
/03 / ESP32 AND USB/LED_A: D4.2 (A), R14.2
/03 / ESP32 AND USB/LED_STATUS: R14.1, U4.21 (IO13)
/03 / ESP32 AND USB/UART_RX: J5.3, U4.36 (RXD0)
/03 / ESP32 AND USB/UART_TX: J5.2, U4.37 (TXD0)
/03 / ESP32 AND USB/USB_CC1: J4.A5 (CC1), R15.1
/03 / ESP32 AND USB/USB_CC2: J4.B5 (CC2), R16.1
/03 / ESP32 AND USB/USB_DM: J4.A7 (D-), J4.B7 (D-), U6.1 (I/O1)
/03 / ESP32 AND USB/USB_DM_ESD: R18.1, U6.6 (I/O1)
/03 / ESP32 AND USB/USB_DM_MCU: R18.2, U4.13 (USB_D-)
/03 / ESP32 AND USB/USB_DP: J4.A6 (D+), J4.B6 (D+), U6.3 (I/O2)
/03 / ESP32 AND USB/USB_DP_ESD: R17.1, U6.4 (I/O2)
/03 / ESP32 AND USB/USB_DP_MCU: R17.2, U4.14 (USB_D+)
/03 / ESP32 AND USB/USB_VBUS: J4.A4 (VBUS), J4.A9 (VBUS), J4.B4 (VBUS), J4.B9 (VBUS), U6.5 (VBUS)
ADC_RDY: U4.20 (IO12); also elsewhere on the board
AO_ENABLE: U4.18 (IO10); also elsewhere on the board
AO_FAULT_N: U4.19 (IO11); also elsewhere on the board
GND: C11.2, C12.2, C13.2, C14.2, D4.1 (K), J4.A1 (GND), J4.A12 (GND), J4.B1 (GND), J4.B12 (GND), J4.S1 (SHIELD), J5.1, R15.2, R16.2, SW1.2, SW2.2, U4.1 (GND), U4.40 (GND), U4.41 (GND), U5.1 (GND), U6.2 (GND); also elsewhere on the board
I2C_SCL: R13.2, U4.17 (IO9); also elsewhere on the board
I2C_SDA: R12.2, U4.12 (IO8); also elsewhere on the board
SYS_OK: D3.1 (K), U5.2 (~RESET); also elsewhere on the board
V3V3: C11.1, C12.1, C14.1, J5.4, R10.1, R11.1, R12.1, R13.1, U4.2 (3V3), U5.3 (VDD); also elsewhere on the board

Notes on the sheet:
03 / ESP32 AND USB
ESP32 / 24 V / 4-20 mA | Rev A - engineering prototype | 2026-09-07
ESP32-S3-WROOM-1-N8
No PSRAM. GPIO19/20 reserved for native USB. Antenna keepout required.
SUPERVISION / I2C / DEBUG
SYS_OK disconnects ADC and inhibits AO below 3.08 V nominal.
I2C: ADS1115 0x48; DAC80501 0x49 (A0 tied to VDD). BOOT held low during RESET enters ROM download mode. SYS_OK is supply supervision, not a firmware watchdog.
USB-C / DATA ONLY
No VBUS-to-board power connection.

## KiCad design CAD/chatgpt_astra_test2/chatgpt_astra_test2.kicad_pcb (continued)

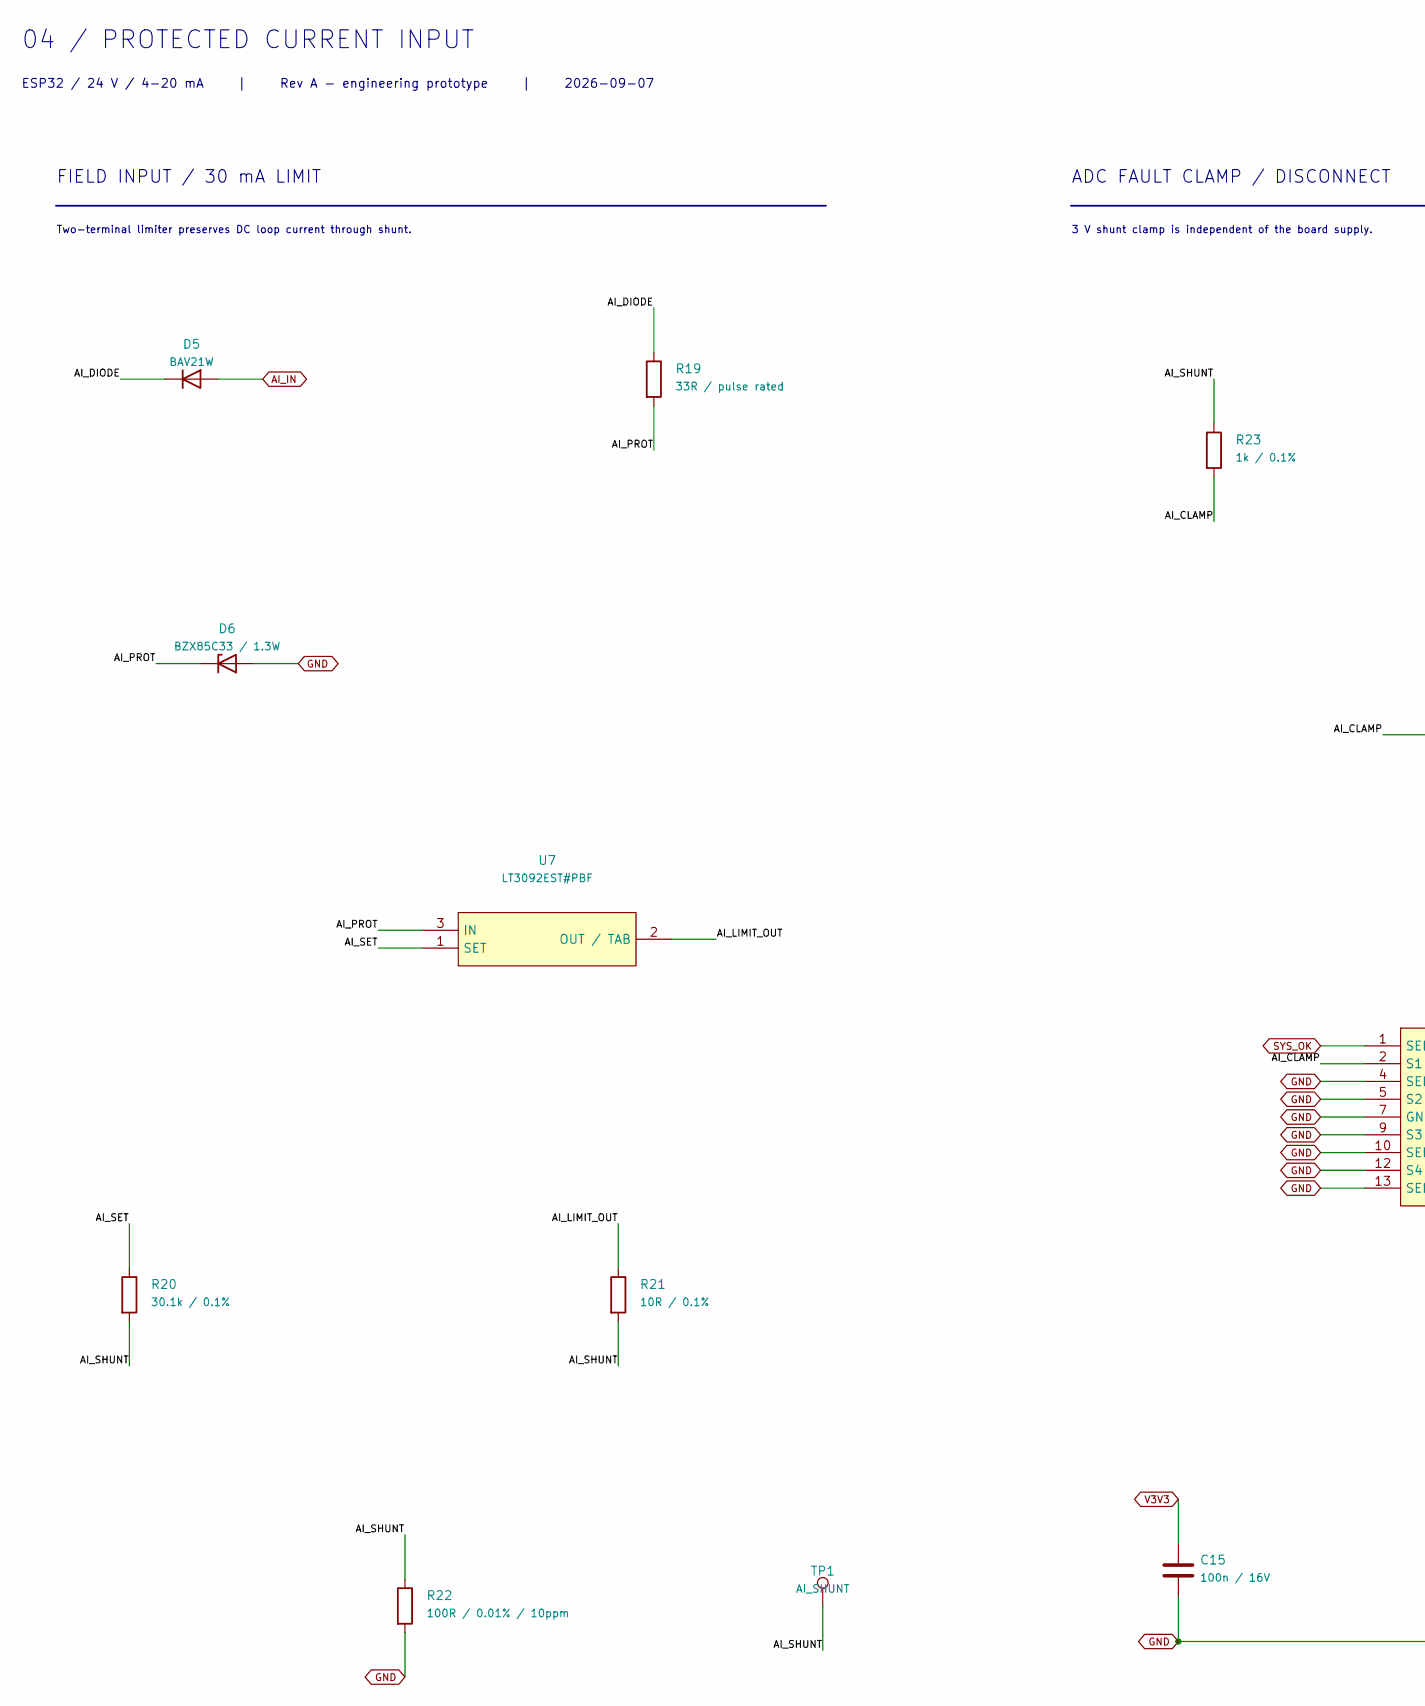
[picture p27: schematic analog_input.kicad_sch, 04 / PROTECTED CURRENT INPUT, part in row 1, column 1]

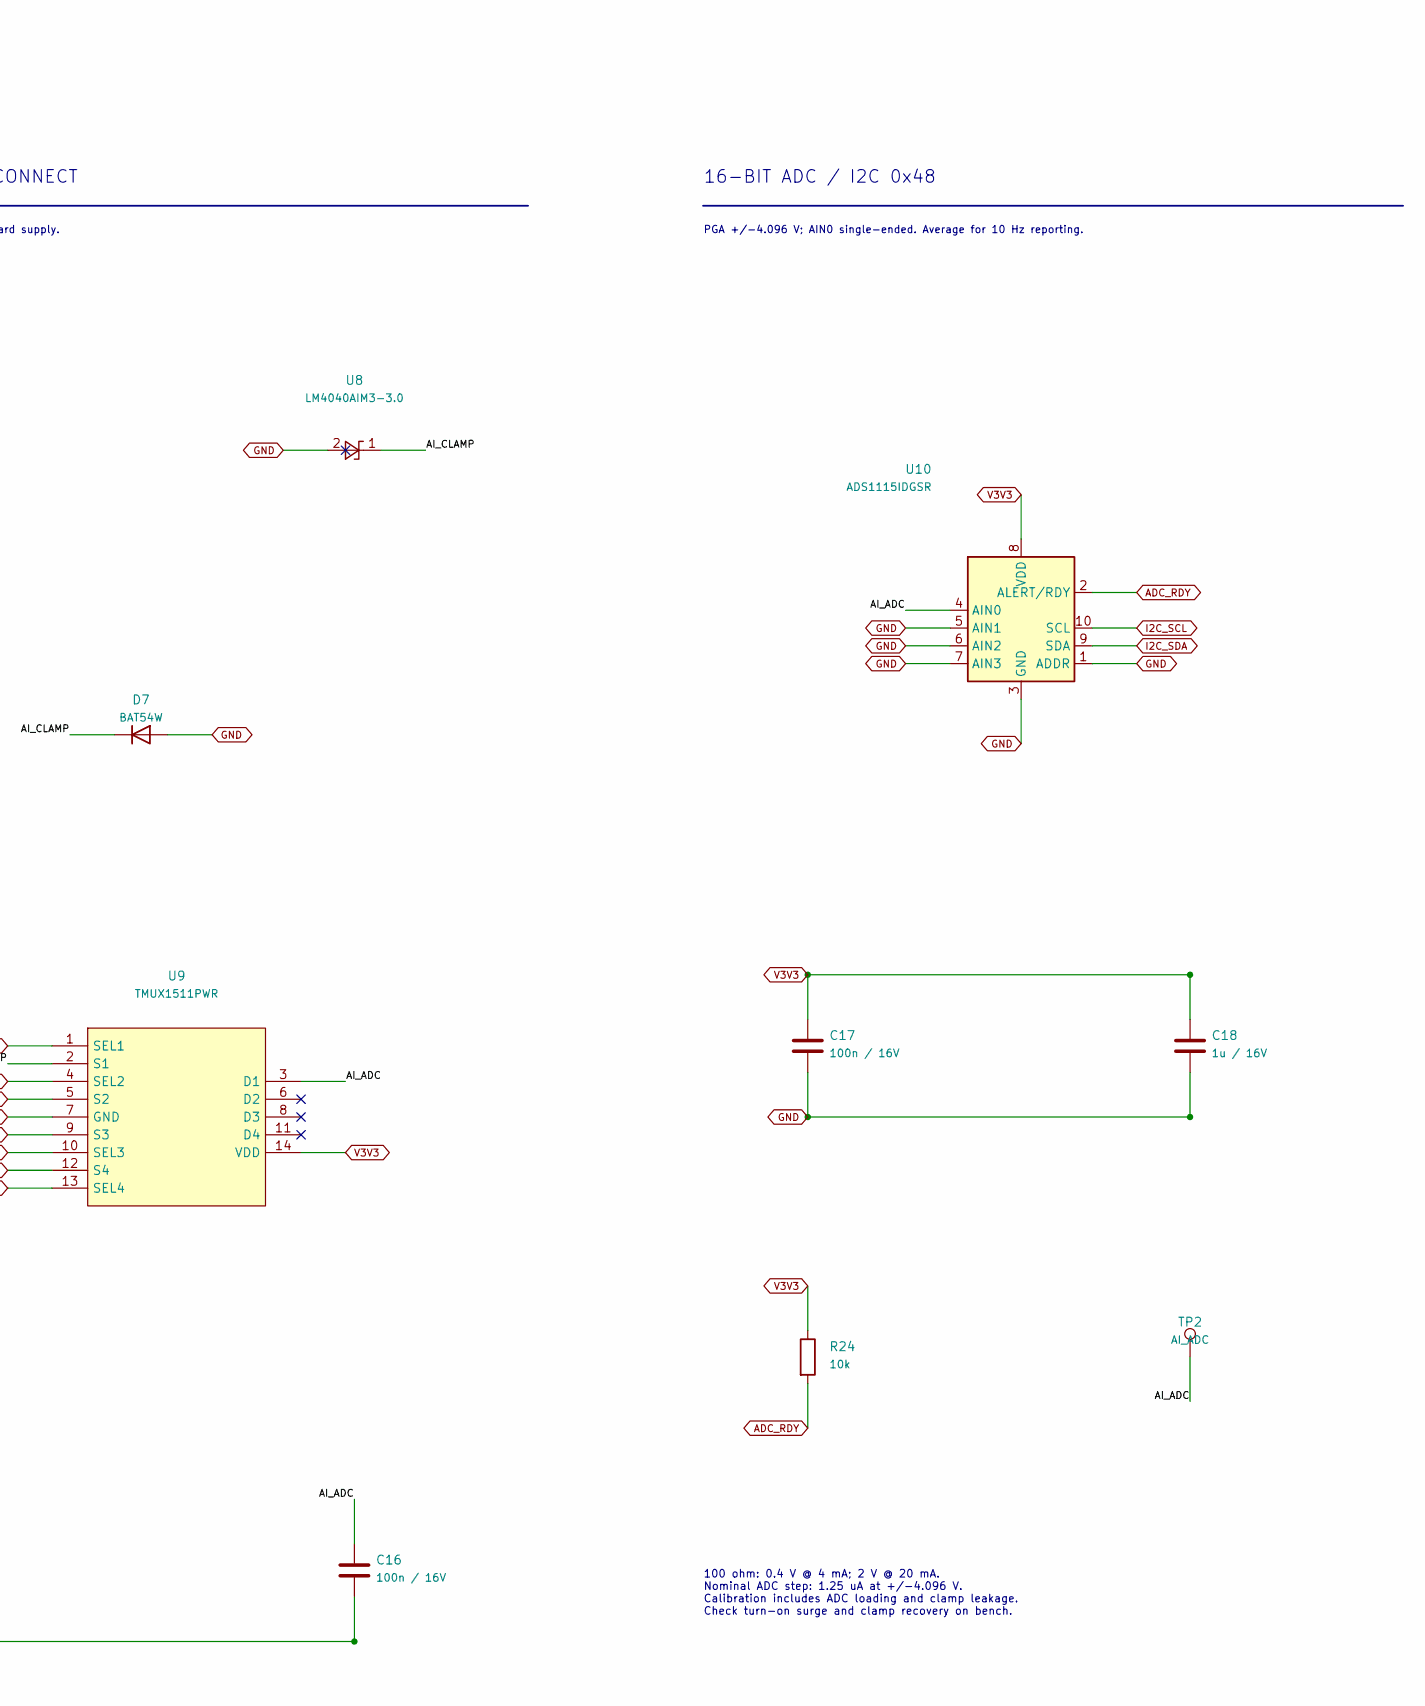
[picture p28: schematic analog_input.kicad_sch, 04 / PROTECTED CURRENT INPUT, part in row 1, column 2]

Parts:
C15, C16, C17: 100n / 16V; C_0805_2012Metric
C18: 1u / 16V; C_0805_2012Metric
D5: BAV21W; D_SOD-123
D6: BZX85C33 / 1.3W; D_DO-41_SOD81_P10.16mm_Horizontal
D7: BAT54W; D_SOD-123
R19: 33R / pulse rated; R_1206_3216Metric
R20: 30.1k / 0.1%; R_0805_2012Metric
R21: 10R / 0.1%; R_0805_2012Metric
R22: 100R / 0.01% / 10ppm; R_1206_3216Metric
R23: 1k / 0.1%; R_0805_2012Metric
R24: 10k; R_0805_2012Metric
TP1: AI_SHUNT; TestPoint_Pad_D1.5mm
TP2: AI_ADC; TestPoint_Pad_D1.5mm
U7: LT3092EST#PBF; SOT-223-3_TabPin2
U8: LM4040AIM3-3.0; SOT-23
U9: TMUX1511PWR; TSSOP-14_4.4x5mm_P0.65mm
U10: ADS1115IDGSR; TSSOP-10_3x3mm_P0.5mm

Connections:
/04 / PROTECTED CURRENT INPUT/AI_ADC: C16.1, TP2.1, U9.3 (D1), U10.4 (AIN0)
/04 / PROTECTED CURRENT INPUT/AI_CLAMP: D7.1 (K), R23.2, U8.1 (K), U9.2 (S1)
/04 / PROTECTED CURRENT INPUT/AI_DIODE: D5.1 (K), R19.1
/04 / PROTECTED CURRENT INPUT/AI_LIMIT_OUT: R21.1, U7.2 (OUT / TAB)
/04 / PROTECTED CURRENT INPUT/AI_PROT: D6.1 (K), R19.2, U7.3 (IN)
/04 / PROTECTED CURRENT INPUT/AI_SET: R20.1, U7.1 (SET)
/04 / PROTECTED CURRENT INPUT/AI_SHUNT: R20.2, R21.2, R22.1, R23.1, TP1.1
ADC_RDY: R24.2, U10.2 (ALERT/RDY); also elsewhere on the board
AI_IN: D5.2 (A); also elsewhere on the board
GND: C15.2, C16.2, C17.2, C18.2, D6.2 (A), D7.2 (A), R22.2, U8.2 (A), U9.4 (SEL2), U9.5 (S2), U9.7 (GND), U9.9 (S3), U9.10 (SEL3), U9.12 (S4), U9.13 (SEL4), U10.1 (ADDR), U10.3 (GND), U10.5 (AIN1), U10.6 (AIN2), U10.7 (AIN3); also elsewhere on the board
I2C_SCL: U10.10 (SCL); also elsewhere on the board
I2C_SDA: U10.9 (SDA); also elsewhere on the board
SYS_OK: U9.1 (SEL1); also elsewhere on the board
V3V3: C15.1, C17.1, C18.1, R24.1, U9.14 (VDD), U10.8 (VDD); also elsewhere on the board

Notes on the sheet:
04 / PROTECTED CURRENT INPUT
ESP32 / 24 V / 4-20 mA | Rev A - engineering prototype | 2026-09-07
FIELD INPUT / 30 mA LIMIT
Two-terminal limiter preserves DC loop current through shunt.
ADC FAULT CLAMP / DISCONNECT
3 V shunt clamp is independent of the board supply.
16-BIT ADC / I2C 0x48
PGA +/-4.096 V; AIN0 single-ended. Average for 10 Hz reporting.
100 ohm: 0.4 V @ 4 mA; 2 V @ 20 mA. Nominal ADC step: 1.25 uA at +/-4.096 V. Calibration includes ADC loading and clamp leakage. Check turn-on surge and clamp recovery on bench.

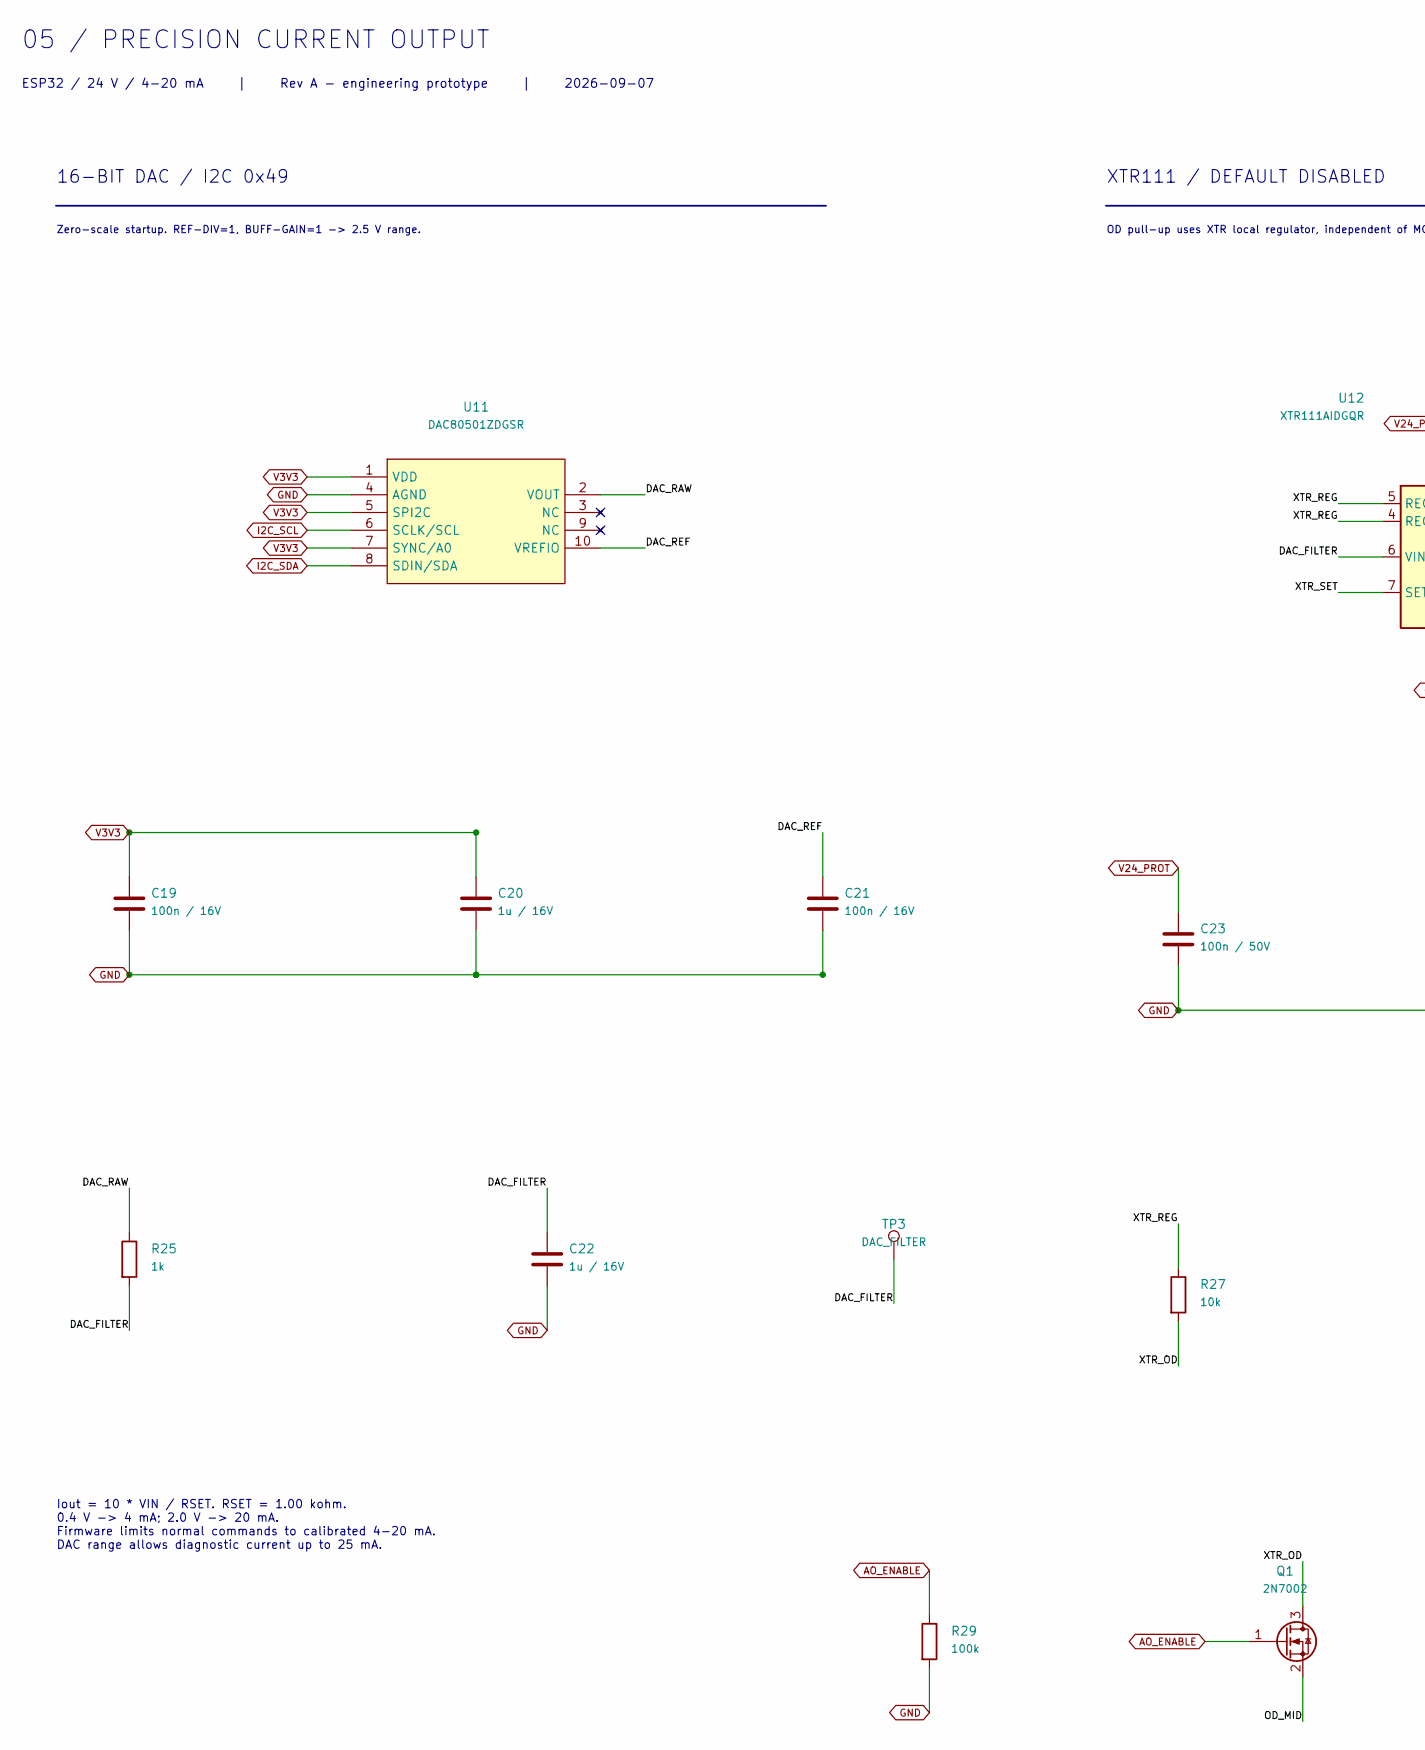
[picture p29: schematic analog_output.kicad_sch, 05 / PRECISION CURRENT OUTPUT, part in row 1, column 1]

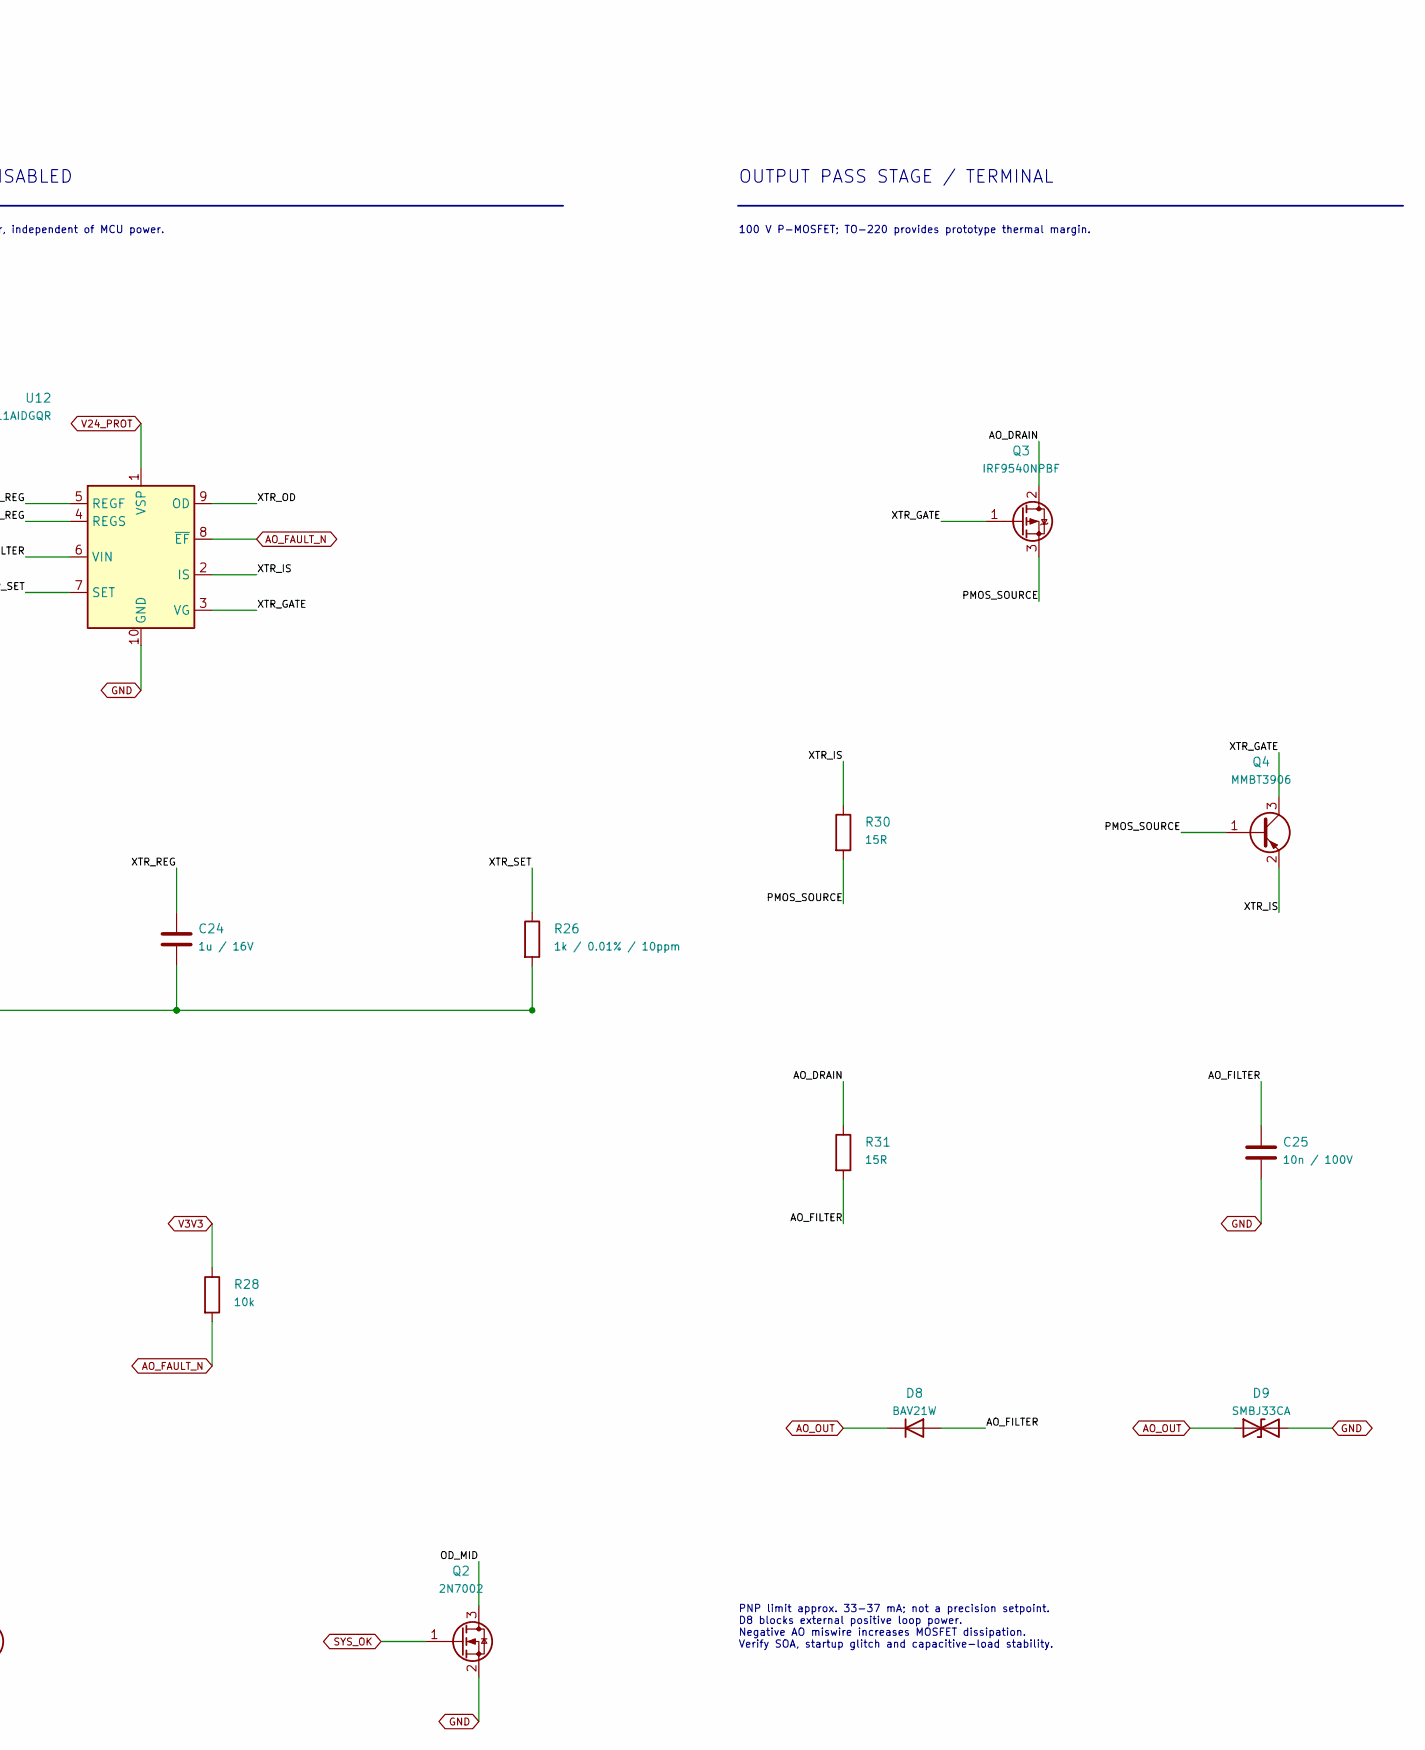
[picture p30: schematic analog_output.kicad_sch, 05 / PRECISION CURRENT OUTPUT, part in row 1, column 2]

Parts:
C19, C21: 100n / 16V; C_0805_2012Metric
C20, C22, C24: 1u / 16V; C_0805_2012Metric
C23: 100n / 50V; C_0805_2012Metric
C25: 10n / 100V; C_0805_2012Metric
D8: BAV21W; D_SOD-123
D9: SMBJ33CA; D_SMB
Q1, Q2: 2N7002; SOT-23
Q3: IRF9540NPBF; TO-220-3_Vertical
Q4: MMBT3906; SOT-23
R25: 1k; R_0805_2012Metric
R26: 1k / 0.01% / 10ppm; R_0805_2012Metric
R27, R28: 10k; R_0805_2012Metric
R29: 100k; R_0805_2012Metric
R30, R31: 15R; R_0805_2012Metric
TP3: DAC_FILTER; TestPoint_Pad_D1.5mm
U11: DAC80501ZDGSR; VSSOP-10_3x3mm_P0.5mm
U12: XTR111AIDGQR; MSOP-10-1EP_3x3mm_P0.5mm_EP2.2x3.1mm_Mask1.83x1.89mm_Therma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

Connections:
/05 / PRECISION CURRENT OUTPUT/AO_DRAIN: Q3.2 (D), R31.1
/05 / PRECISION CURRENT OUTPUT/AO_FILTER: C25.1, D8.2 (A), R31.2
/05 / PRECISION CURRENT OUTPUT/DAC_FILTER: C22.1, R25.2, TP3.1, U12.6 (VIN)
/05 / PRECISION CURRENT OUTPUT/DAC_RAW: R25.1, U11.2 (VOUT)
/05 / PRECISION CURRENT OUTPUT/DAC_REF: C21.1, U11.10 (VREFIO)
/05 / PRECISION CURRENT OUTPUT/OD_MID: Q1.2 (S), Q2.3 (D)
/05 / PRECISION CURRENT OUTPUT/PMOS_SOURCE: Q3.3 (S), Q4.1 (B), R30.2
/05 / PRECISION CURRENT OUTPUT/XTR_GATE: Q3.1 (G), Q4.3 (C), U12.3 (VG)
/05 / PRECISION CURRENT OUTPUT/XTR_IS: Q4.2 (E), R30.1, U12.2 (IS)
/05 / PRECISION CURRENT OUTPUT/XTR_OD: Q1.3 (D), R27.2, U12.9 (OD)
/05 / PRECISION CURRENT OUTPUT/XTR_REG: C24.1, R27.1, U12.4 (REGS), U12.5 (REGF)
/05 / PRECISION CURRENT OUTPUT/XTR_SET: R26.1, U12.7 (SET)
AO_ENABLE: Q1.1 (G), R29.1; also elsewhere on the board
AO_FAULT_N: R28.2, U12.8 (~EF); also elsewhere on the board
AO_OUT: D8.1 (K), D9.1 (A1); also elsewhere on the board
GND: C19.2, C20.2, C21.2, C22.2, C23.2, C24.2, C25.2, D9.2 (A2), Q2.2 (S), R26.2, R29.2, U11.4 (AGND), U12.10 (GND), U12.11 (GND); also elsewhere on the board
I2C_SCL: U11.6 (SCLK/SCL); also elsewhere on the board
I2C_SDA: U11.8 (SDIN/SDA); also elsewhere on the board
SYS_OK: Q2.1 (G); also elsewhere on the board
V3V3: C19.1, C20.1, R28.1, U11.1 (VDD), U11.5 (SPI2C), U11.7 (SYNC/A0); also elsewhere on the board
V24_PROT: C23.1, U12.1 (VSP); also elsewhere on the board

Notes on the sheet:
05 / PRECISION CURRENT OUTPUT
ESP32 / 24 V / 4-20 mA | Rev A - engineering prototype | 2026-09-07
16-BIT DAC / I2C 0x49
Zero-scale startup. REF-DIV=1, BUFF-GAIN=1 -> 2.5 V range.
Iout = 10 * VIN / RSET. RSET = 1.00 kohm. 0.4 V -> 4 mA; 2.0 V -> 20 mA. Firmware limits normal commands to calibrated 4-20 mA. DAC range allows diagnostic current up to 25 mA.
XTR111 / DEFAULT DISABLED
OD pull-up uses XTR local regulator, independent of MCU power.
OUTPUT PASS STAGE / TERMINAL
100 V P-MOSFET; TO-220 provides prototype thermal margin.
PNP limit approx. 33-37 mA; not a precision setpoint. D8 blocks external positive loop power. Negative AO miswire increases MOSFET dissipation. Verify SOA, startup glitch and capacitive-load stability.

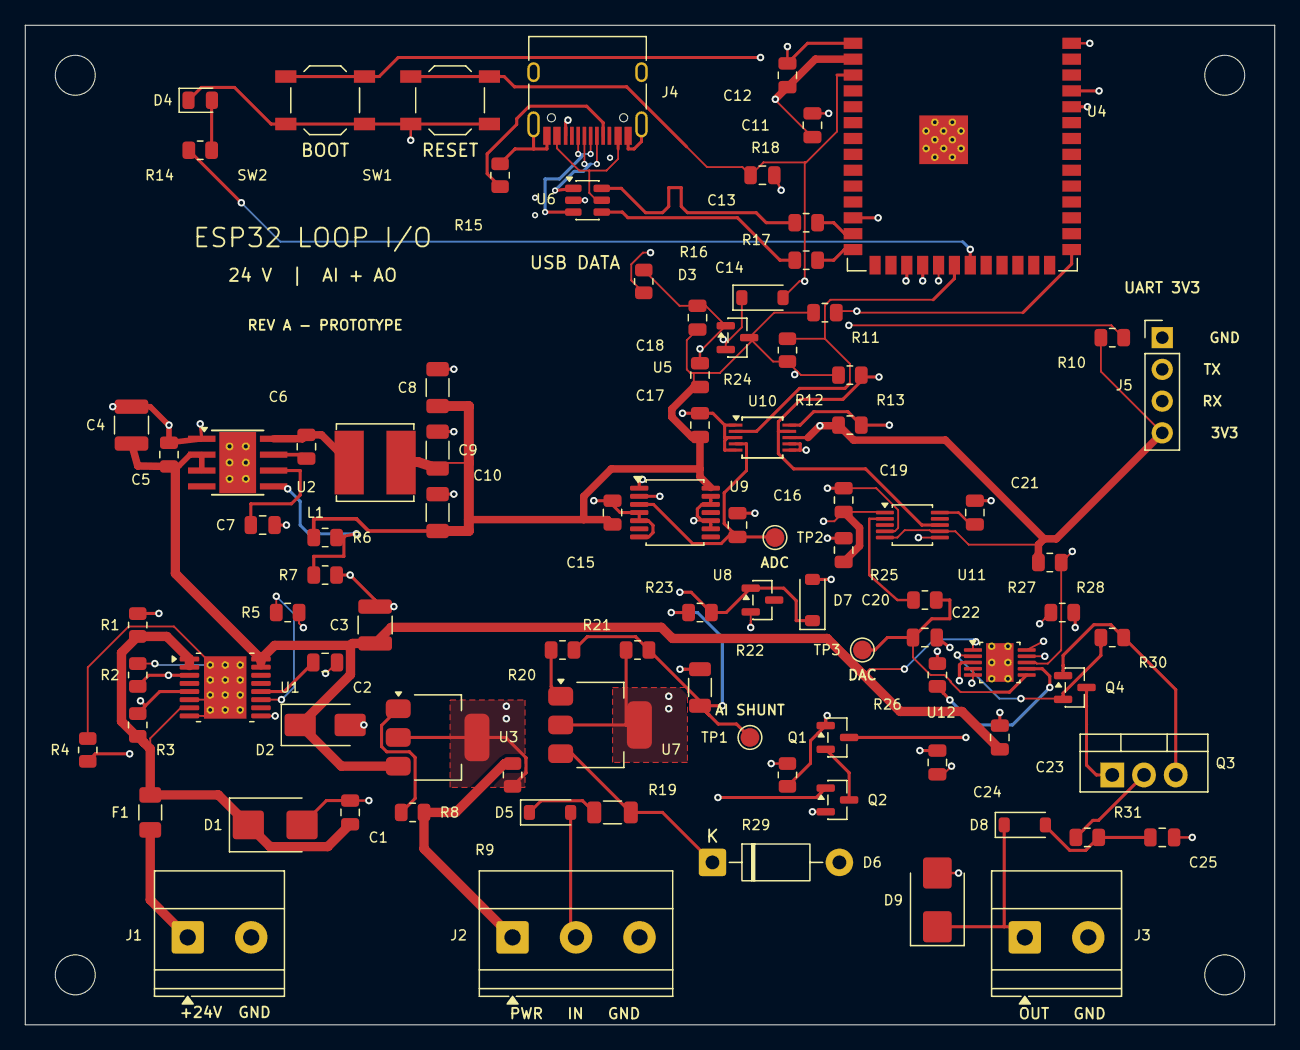
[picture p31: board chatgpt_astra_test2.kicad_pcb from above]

Board: 4 copper layers, 100.0 x 80.0 mm, 97 parts (0 on the bottom side), 59 nets.

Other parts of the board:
H1, H2, H3, H4: M3 / 3.2mm; MountingHole_3.2mm_M3

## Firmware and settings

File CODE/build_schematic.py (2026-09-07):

"""Generate the revision-A KiCad schematic and its project-local libraries.

All schematic objects have deterministic UUIDs. Run only to regenerate the
generated design; manual schematic edits should be preserved separately first.
"""
from pathlib import Path
import re, json, uuid, copy, math, shutil

ROOT = Path(__file__).resolve().parents[1]
PROJECT = ROOT / 'CAD/chatgpt_astra_test2'
LIBROOT = Path('C:/Users/fnk/Documents/KiCad/Kicad-Libraries/kicad_8_libs')

def parse(t):
    toks = re.findall(r'"(?:\\.|[^"\\])*"|\(|\)|[^\s()]+', t)
    stack=[]; root=[]; cur=root
    for s in toks:
        if s=='(':
            n=[]; cur.append(n); stack.append(cur); cur=n
        elif s==')': cur=stack.pop()
        else: cur.append(s)
    return root[0]

def q(s): return json.dumps(str(s), ensure_ascii=False)
def uq(s): return json.loads(s) if s.startswith('"') else s
def children(n,key): return [v for v in n if isinstance(v,list) and v and v[0]==key]
def child(n,key): return next(iter(children(n,key)),None)
def dump(n): return '('+' '.join(dump(v) if isinstance(v,list) else v for v in n)+')'
def uid(s): return str(uuid.uuid5(uuid.NAMESPACE_URL,'esp32-loop-reva/'+s))
cache={}
def stock(lib,name):
    if lib not in cache:
        cache[lib]=parse((LIBROOT/'kicad-symbols'/f'{lib}.kicad_sym').read_text(encoding='utf8'))
    n=copy.deepcopy(next(v for v in children(cache[lib],'symbol') if uq(v[1])==name))
    ext=child(n,'extends')
    if ext:
        base=stock(lib,uq(ext[1])); basename=uq(base[1])
        for v in children(base,'symbol'): v[1]=q(uq(v[1]).replace(basename+'_',name+'_',1))
        props={uq(v[1]):v for v in children(n,'property')}
        base=[v for v in base if not(isinstance(v,list) and v[0]=='property' and uq(v[1]) in props)]
        base.extend(props.values()); base[1]=q(name); n=base
    return n

def pins(n):
    out=[]
    for sub in children(n,'symbol'):
        for p in children(sub,'pin'):
            a=child(p,'at')
            out.append((uq(child(p,'number')[1]),uq(child(p,'name')[1]),p[1],tuple(map(float,a[1:]))))
    return out

SYMS={}; BOM=[]; EXPECTED={}; FPS={}
GLOBALS={'VIN24','GND','V24_PROT','V3V3','SENSOR_PWR','AI_IN','AO_OUT',
         'I2C_SDA','I2C_SCL','AO_ENABLE','AO_FAULT_N','SYS_OK','ADC_RDY'}
ROOT_ID='a269929a-5104-4f3f-907a-1d34fef46421'

def library_symbol(lib,name):
    key=lib+'_'+name
    if key not in SYMS:
        n=stock(lib,name); old=uq(n[1]); n[1]=q(key)
        for s in children(n,'symbol'): s[1]=q(uq(s[1]).replace(old+'_',key+'_',1))
        SYMS[key]=n
    return key

def custom(name, pin_defs, footprint, url):
    # pin_defs = (number, name, electrical type, side); one unit, ordinary IC body.
    groups={s:[p for p in pin_defs if p[3]==s] for s in ('L','R')}
    h=max(len(g) for g in groups.values())*2.54+2.54
    n=parse(f'(symbol {q(name)} (pin_names (offset 0.635)) (in_bom yes) (on_board yes) '
            f'(property "Reference" "U" (at 0 {h/2+5} 0) (effects (font (size 1.27 1.27)))) '
            f'(property "Value" {q(name)} (at 0 {h/2+2} 0) (effects (font (size 1.27 1.27)))) '
            f'(property "Footprint" {q(footprint)} (at 0 0 0) (effects (font (size 1.27 1.27)) hide)) '
            f'(property "Datasheet" {q(url)} (at 0 0 0) (effects (font (size 1.27 1.27)) hide)) '
            f'(symbol {q(name+"_0_1")} (rectangle (start -12.7 {h/2}) (end 12.7 {-h/2}) (stroke (width 0) (type default)) (fill (type background)))) '
            f'(symbol {q(name+"_1_1")}))')
    for side,ps in groups.items():
        for i,(num,pname,typ,_) in enumerate(ps):
            x=-17.78 if side=='L' else 17.78; y=(len(ps)-1)*1.27-i*2.54
            child(n,'symbol')
            n[-1].append(parse(f'(pin {typ} line (at {x} {y} {0 if side=="L" else 180}) (length 5.08) (name {q(pname)} (effects (font (size 1.27 1.27)))) (number {q(num)} (effects (font (size 1.27 1.27)))))'))
    SYMS[name]=n
    return name

def footprint_local(fp):
    if not fp: return ''
    if fp not in FPS:
        lib,name=fp.split(':'); src=LIBROOT/'kicad-footprints'/(lib+'.pretty')/(name+'.kicad_mod')
        if not src.exists(): raise FileNotFoundError(src)
        dest=PROJECT/'libraries/LoopIO.pretty'; dest.mkdir(parents=True,exist_ok=True)
        shutil.copyfile(src,dest/src.name)
        FPS[fp]='LoopIO:'+name
    return FPS[fp]

def fmt(v): return f'{v:.4f}'.rstrip('0').rstrip('.') if v else '0'

class Sheet:
    def __init__(self,name,title,page):
        self.name=name; self.title=title; self.page=page; self.id=ROOT_ID if page==1 else uid(name)
        self.path='/'+ROOT_ID if page==1 else '/'+ROOT_ID+'/'+uid('sheet-'+name)
        self.objects=[]; self.used=set(); self.counter=0;self.terminals=[]
        self.note(15,15,title,2.54)
        self.note(15,22,'ESP32 / 24 V / 4-20 mA     |     Rev A - engineering prototype     |     2026-09-07',1.27)
    def oid(self): self.counter+=1; return uid(self.name+'/'+str(self.counter))
    def note(self,x,y,t,size=1.27):
        self.objects.append(f'(text {q(t)} (at {x} {y} 0) (effects (font (size {size} {size})) (justify left top)) (uuid {self.oid()}))')
    def line(self,x1,y1,x2,y2):
        self.objects.append(f'(polyline (pts (xy {x1} {y1}) (xy {x2} {y2})) (stroke (width 0.254) (type default)) (uuid {self.oid()}))')
    def section(self,x,y,title,desc=''):
        self.note(x,y,title,1.8); self.line(x,y+5,min(x+110,400),y+5)
        if desc:self.note(x,y+8,desc,1.05)
    def wire(self,a,b):
        if a==b:return
        self.objects.append(f'(wire (pts (xy {fmt(a[0])} {fmt(a[1])}) (xy {fmt(b[0])} {fmt(b[1])})) (stroke (width 0) (type default)) (uuid {self.oid()}))')
    def label(self,net,x,y,justify='left'):
        # Global labels link sheet interfaces, ordinary labels stay within their sheet.
        if net in GLOBALS:
            rot=180 if justify=='right' else 0
            self.objects.append(f'(global_label {q(net)} (shape bidirectional) (at {fmt(x)} {fmt(y)} {rot}) (effects (font (size 1.0 1.0)) (justify {justify})) (uuid {self.oid()}) (property "Intersheetrefs" "${{INTERSHEET_REFS}}" (at {fmt(x)} {fmt(y)} {rot}) (effects (font (size 1 1)) hide)))')
        else:
            self.objects.append(f'(label {q(net)} (at {fmt(x)} {fmt(y)} 0) (effects (font (size 1.0 1.0)) (justify {justify} bottom)) (uuid {self.oid()}))')
    def add(self,ref,key,x,y,nets,value=None,fp=None,angle=0,desc=''):
        x=round(round(x/1.27)*1.27,4);y=round(round(y/1.27)*1.27,4)
        n=SYMS[key]; self.used.add(key); objid=uid(ref)
        props={uq(p[1]):uq(p[2]) for p in children(n,'property')}
        value=value or props.get('Value',key)
        fp=footprint_local(fp if fp is not None else props.get('Footprint',''))
        nn={str(k):v for k,v in nets.items()}
        coords={}; ar=math.radians(angle)
        for num,pname,typ,(px,py,pa) in pins(n):
            xx=x+px*math.cos(ar)-py*math.sin(ar); yy=y-px*math.sin(ar)-py*math.cos(ar)
            coords[num]=(round(xx,4),round(yy,4),round((pa+angle)%360))
        # Every physical pin must be explicitly connected or marked unused.
        assert set(nn)==set(coords),(ref,set(coords)-set(nn),set(nn)-set(coords))
        top=min(v[1] for v in coords.values()); bottom=max(v[1] for v in coords.values())
        passive=ref[0] in 'RCLDF' and len(coords)==2
        px=x+3 if passive and angle==0 and ref[0] in 'RCLF' else x
        py=y-1.5 if passive and angle==0 and ref[0] in 'RCLF' else top-(10 if ref.startswith('U') else 8 if ref.startswith('J') else 5)
        just=' (justify left)' if px!=x else ''
        if ref.startswith('U') and any(v[2]==270 for v in coords.values()):
            px=x-12.7;just=' (justify right)'
        o=f'(symbol (lib_id {q("LoopIO:"+key)}) (at {x} {y} {angle}) (unit 1) (in_bom yes) (on_board yes) (dnp no) (uuid {objid})'
        o+=f'(property "Reference" {q(ref)} (at {px} {py} 0) (effects (font (size 1.27 1.27)){just}))'
        o+=f'(property "Value" {q(value)} (at {px} {py+2.54} 0) (effects (font (size 1.1 1.1)){just}))'
        for pn,pv in [('Footprint',fp),('Datasheet',props.get('Datasheet','')),('Description',desc)]:
            o+=f'(property {q(pn)} {q(pv)} (at {x} {y} 0) (effects (font (size 1 1)) hide))'
        for num in coords: o+=f'(pin {q(num)} (uuid {uid(ref+"/"+num)}))'
        o+=f'(instances (project "chatgpt_astra_test2" (path {q(self.path)} (reference {q(ref)}) (unit 1)))))'
        self.objects.append(o)
        seen={};vertical_groups={}
        for num,(xx,yy,pa) in coords.items():
            net=nn[num]
            if (xx,yy) in seen:
                assert seen[(xx,yy)]==net,(ref,'stacked net mismatch')
                continue
            seen[(xx,yy)]=net
            if net is None:
                self.objects.append(f'(no_connect (at {fmt(xx)} {fmt(yy)}) (uuid {self.oid()}))'); continue
            dx,dy={0:(-6.35,0),180:(6.35,0),90:(0,6.35),270:(0,-6.35)}[pa]
            end=(round(xx+dx,4),round(yy+dy,4));self.wire((xx,yy),end)
            vg=(net,pa,end[1])
            if pa in (90,270) and vg in vertical_groups:
                self.wire(vertical_groups[vg],end)
                self.objects.append(f'(junction (at {fmt(vertical_groups[vg][0])} {fmt(end[1])}) (diameter 0) (color 0 0 0 0) (uuid {self.oid()}))')
                continue
            vertical_groups[vg]=end
            li=len(self.objects)
            self.label(net,*end,'right' if pa in (0,90,270) else 'left')
            self.terminals.append((net,end,pa,li))
        EXPECTED[ref]={'sheet':self.name,'pins':nn,'symbol':key,'footprint':fp}
        if not ref.startswith('#'):BOM.append({'Reference':ref,'Value':value,'Footprint':fp,'Datasheet':props.get('Datasheet',''),'Description':desc})
        return coords
    def save(self):
        # Join adjacent, aligned supply/return branches into visible rails.
        # Reject a rail if another terminal would be shorted by its segment.
        groups={}
        for net,end,pa,li in self.terminals:
            if pa in (90,270) and net in {'GND','V3V3','V24_PROT','VIN_FUSED'}:
                groups.setdefault((net,end[1],pa),[]).append((end[0],li))
        for (net,y,pa),points in groups.items():
            points.sort()
            for (x1,li1),(x2,li2) in zip(points,points[1:]):
                if x2-x1>100 or x2==x1:continue
                if any(n!=net and abs(p[1]-y)<0.01 and x1<=p[0]<=x2 for n,p,_,_ in self.terminals):continue
                self.wire((x1,y),(x2,y));self.objects[li2]=''
                for x in (x1,x2):self.objects.append(f'(junction (at {fmt(x)} {fmt(y)}) (diameter 0) (color 0 0 0 0) (uuid {self.oid()}))')
        ls=[]
        for key in sorted(self.used):
            n=copy.deepcopy(SYMS[key]); n[1]=q('LoopIO:'+key);ls.append(dump(n))
        header=f'(kicad_sch (version 20250114) (generator "eeschema") (generator_version "9.0") (uuid {self.id}) (paper "A3") (title_block (title {q(self.title)}) (date "2026-09-07") (rev "A - prototype") (company "ESP32 Loop I/O") (comment 1 "Engineering review required before fabrication")) (lib_symbols {" ".join(ls)})'
        if self.page==1:header+='(sheet_instances (path "/" (page "1")))'
        (PROJECT/(self.name+'.kicad_sch')).write_text(header+'\n'+'\n'.join(self.objects)+'\n(embedded_fonts no))\n',encoding='utf8')

def build():
    def key(lib,name):return library_symbol(lib,name)
    R=key('Device','R'); C=key('Device','C'); D=key('Device','D'); TVS=key('Device','D_TVS'); Z=key('Device','D_Zener')
    L=key('Device','L'); F=key('Device','Fuse'); FLAG=key('power','PWR_FLAG'); TP=key('Connector','TestPoint')
    rfp='Resistor_SMD:R_0805_2012Metric'; cfp='Capacitor_SMD:C_0805_2012Metric'; dfp='Diode_SMD:D_SOD-123'
    def r(s,ref,x,y,val,a,b,fp=rfp):s.add(ref,R,x,y,{'1':a,'2':b},val,fp)
    def c(s,ref,x,y,val,a,b='GND',fp=cfp):s.add(ref,C,x,y,{'1':a,'2':b},val,fp)
    def diode(s,ref,x,y,val,a,k,fp=dfp):s.add(ref,D,x,y,{'1':k,'2':a},val,fp)
    def flag(s,ref,x,y,net):s.add(ref,FLAG,x,y,{'1':net},fp='')
    def tp(s,ref,x,y,net):s.add(ref,TP,x,y,{'1':net},net,'TestPoint:TestPoint_Pad_D1.5mm')
    root=Sheet('chatgpt_astra_test2','01 / SYSTEM INTERFACES',1)
    power=Sheet('power','02 / POWER AND SENSOR SUPPLY',2)
    mcu=Sheet('controller','03 / ESP32 AND USB',3)
    ai=Sheet('analog_input','04 / PROTECTED CURRENT INPUT',4)
    ao=Sheet('analog_output','05 / PRECISION CURRENT OUTPUT',5)
    sheets=[root,power,mcu,ai,ao]
    for s,(x,y) in zip(sheets[1:],[(170,60),(300,60),(170,150),(300,150)]):
        root.objects.append(f'(sheet (at {x} {y}) (size 90 35) (fields_autoplaced yes) (stroke (width 0) (type default)) (fill (color 0 0 0 0)) (uuid {uid("sheet-"+s.name)}) (property "Sheetname" {q(s.title)} (at {x} {y-1} 0) (effects (font (size 1.27 1.27)) (justify left bottom))) (property "Sheetfile" {q(s.name+".kicad_sch")} (at {x} {y+36} 0) (effects (font (size 1.27 1.27)) (justify left top))) (instances (project "chatgpt_astra_test2" (path "/{ROOT_ID}" (page "{s.page}")))))')
    root.section(20,35,'FIELD TERMINALS','All returns and USB ground are common. No galvanic isolation.')
    conn2=key('Connector_Generic','Conn_01x02');conn3=key('Connector_Generic','Conn_01x03')
    tfp='TerminalBlock_Phoenix:TerminalBlock_Phoenix_MKDS-1,5-2-5.08_1x02_P5.08mm_Horizontal'
    root.add('J1',conn2,85,65,{'1':'VIN24','2':'GND'},'18-30 V DC',tfp)
    root.add('J2',conn3,85,110,{'1':'SENSOR_PWR','2':'AI_IN','3':'GND'},'CURRENT INPUT','TerminalBlock_Phoenix:TerminalBlock_Phoenix_MKDS-1,5-3-5.08_1x03_P5.08mm_Horizontal')
    root.add('J3',conn2,85,155,{'1':'AO_OUT','2':'GND'},'CURRENT OUTPUT',tfp)
    root.note(20,190,'INPUT: two-wire sensor + to J2.1, sensor - to J2.2.\nExternally powered source: signal to J2.2, return to J2.3.\nOUTPUT: passive receiver + to J3.1, receiver - to J3.2.\nDo not connect AO to an actively powered loop input.',1.4)
    root.note(170,108,'VIN24 -> protected 24 V + 3.3 V\nSENSOR_PWR: approximately 40 mA limit',1.27)
    root.note(300,108,'USB-C programming; 24 V board power required\nI2C, output enable and fault monitoring',1.27)
    root.note(170,198,'AI_IN -> limiter -> 100 ohm shunt -> ADC\nNominal range: 4-20 mA; measure 0-25 mA',1.27)
    root.note(300,198,'DAC -> XTR111 -> protected sourcing output\n4-20 mA into 0-500 ohms, including cable',1.27)
    root.note(20,235,'VALIDATION TARGETS\nRoom-temperature accuracy after calibration: +/-16 uA. 10 samples/s.\nBench-check miswire response, startup transients and loop compliance.\nNo IEC surge qualification or temperature accuracy claim at this revision.',1.27)
    flag(root,'#FLG01',125,65,'VIN24');flag(root,'#FLG02',125,90,'GND')

    # Power: TPS26600 PWP pinout; RTN remains distinct from system GND.
    power.section(20,35,'24 V ENTRY / eFUSE','RTN is the internal reference: never short it to system GND.')
    power.add('F1',F,40,65,{'1':'VIN24','2':'VIN_FUSED'},'500mA / >=60V','Fuse:Fuse_1206_3216Metric')
    power.add('D1',TVS,85,65,{'1':'VIN_FUSED','2':'GND'},'SMBJ33CA','Diode_SMD:D_SMB')
    c(power,'C1',125,65,'100n / 100V','VIN_FUSED')
    ef=key('Power_Management','TPS26600PWP')
    power.add('U1',ef,80,125,{'1':'VIN_FUSED','2':'VIN_FUSED','3':'EF_UV','4':None,'5':'EF_OV','6':'EF_RTN','7':'VIN_FUSED','8':'EF_RTN','9':'GND','10':None,'11':'EF_ILIM','12':'EF_DVDT','13':None,'14':None,'15':'V24_PROT','16':'V24_PROT','17':'EF_RTN'},'TPS26600PWPR')
    r(power,'R1',30,185,'130k / 0.1%','VIN_FUSED','EF_UV');r(power,'R2',70,185,'10k / 0.1%','EF_UV','EF_RTN')
    r(power,'R3',110,185,'274k / 0.1%','VIN_FUSED','EF_OV');r(power,'R4',150,185,'10k / 0.1%','EF_OV','EF_RTN')
    r(power,'R5',30,225,'30.1k / 1%','EF_ILIM','EF_RTN');c(power,'C2',80,225,'10n / 50V','EF_DVDT','EF_RTN')
    c(power,'C3',125,225,'22u / 63V','V24_PROT',fp='Capacitor_SMD:C_1210_3225Metric')
    diode(power,'D2',130,145,'SS110','GND','V24_PROT','Diode_SMD:D_SMA')
    power.note(20,250,'UV rising approx. 16.66 V; OV rising approx. 33.80 V.\nCurrent limit approx. 399 mA. Auto-retry current limiting.\nFLT unused: avoids reverse-input coupling into MCU ground.',1.1)
    power.section(180,35,'3.3 V / 1 A BUCK','400 kHz. Short VIN-CIN-PGND loop; minimize switch-node copper.')
    power.add('U2',key('Regulator_Switching','LMR36510ADDA'),225,85,{'1':'GND','2':'V24_PROT','3':'V24_PROT','4':None,'5':'BUCK_FB','6':'BUCK_VCC','7':'BUCK_BOOT','8':'BUCK_SW','9':'GND'},'LMR36510ADDAR')
    power.add('L1',L,300,80,{'1':'BUCK_SW','2':'V3V3'},'22uH / Isat >=2A','Inductor_SMD:L_Bourns_SRN6045TA')
    c(power,'C4',185,130,'2.2u / 100V','V24_PROT',fp='Capacitor_SMD:C_1210_3225Metric')
    c(power,'C5',225,130,'220n / 100V','V24_PROT')
    c(power,'C6',270,130,'100n / 16V','BUCK_BOOT','BUCK_SW');c(power,'C7',320,130,'1u / 16V','BUCK_VCC')
    for ref,x in [('C8',185),('C9',230),('C10',275)]:c(power,ref,x,175,'22u / 10V','V3V3',fp='Capacitor_SMD:C_1206_3216Metric')
    r(power,'R6',320,175,'100k / 0.1%','V3V3','BUCK_FB');r(power,'R7',370,175,'43.2k / 0.1%','BUCK_FB','GND')
    flag(power,'#FLG03',375,80,'V3V3');flag(power,'#FLG04',150,65,'VIN_FUSED')
    power.section(185,205,'SENSOR SUPPLY / 40 mA LIMIT','All LT3092 current returns through its load; no ground branch.')
    lt=custom('LT3092EST', [('3','IN','passive','L'),('1','SET','passive','L'),('2','OUT / TAB','passive','R')], 'Package_TO_SOT_SMD:SOT-223-3_TabPin2','https://www.analog.com/media/en/technical-documentation/data-sheets/lt3092.pdf')
    power.add('U3',lt,220,240,{'3':'V24_PROT','1':'SENS_SET','2':'SENS_RAW'},'LT3092EST#PBF')
    r(power,'R8',285,235,'40.2k / 0.1%','SENS_SET','SENSOR_PWR');r(power,'R9',345,235,'10R / 0.1%','SENS_RAW','SENSOR_PWR')

    # MCU, supervisor, USB and user controls.
    mcu.section(20,35,'ESP32-S3-WROOM-1-N8','No PSRAM. GPIO19/20 reserved for native USB. Antenna keepout required.')
    mod=key('RF_Module','ESP32-S3-WROOM-1'); mn={num:None for num,*_ in pins(SYMS[mod])}
    mn.update({'1':'GND','40':'GND','41':'GND','2':'V3V3','3':'ESP_EN','27':'BOOT_N','12':'I2C_SDA','17':'I2C_SCL','18':'AO_ENABLE','19':'AO_FAULT_N','20':'ADC_RDY','37':'UART_TX','36':'UART_RX','13':'USB_DM_MCU','14':'USB_DP_MCU','21':'LED_STATUS'})
    mcu.add('U4',mod,80,100,mn,'ESP32-S3-WROOM-1-N8')
    c(mcu,'C11',30,165,'10u / 10V','V3V3');c(mcu,'C12',80,165,'100n / 16V','V3V3')
    r(mcu,'R10',30,205,'10k','V3V3','ESP_EN');r(mcu,'R11',80,205,'10k','V3V3','BOOT_N');c(mcu,'C13',130,205,'1u / 10V','ESP_EN')
    sw=key('Switch','SW_Push');swfp='Button_Switch_SMD:SW_SPST_TL3342'
    mcu.add('SW1',sw,35,245,{'1':'ESP_EN','2':'GND'},'RESET',swfp);mcu.add('SW2',sw,100,245,{'1':'BOOT_N','2':'GND'},'BOOT',swfp)
    mcu.section(170,35,'SUPERVISION / I2C / DEBUG','SYS_OK disconnects ADC and inhibits AO below 3.08 V nominal.')
    mcu.add('U5',key('Power_Supervisor','TPS3839DBZ'),215,80,{'1':'GND','2':'SYS_OK','3':'V3V3'},'TPS3839G33DBZR')
    diode(mcu,'D3',275,80,'BAT54W','ESP_EN','SYS_OK')
    c(mcu,'C14',180,125,'100n / 16V','V3V3');r(mcu,'R12',225,125,'4.7k','V3V3','I2C_SDA');r(mcu,'R13',275,125,'4.7k','V3V3','I2C_SCL')
    r(mcu,'R14',180,170,'1k','LED_STATUS','LED_A')
    mcu.add('D4',key('Device','LED'),230,170,{'1':'GND','2':'LED_A'},'GREEN','LED_SMD:LED_0805_2012Metric')
    mcu.add('J5',key('Connector_Generic','Conn_01x04'),280,210,{'1':'GND','2':'UART_TX','3':'UART_RX','4':'V3V3'},'UART / 3.3 V ONLY','Connector_PinHeader_2.54mm:PinHeader_1x04_P2.54mm_Vertical')
    mcu.note(170,240,'I2C: ADS1115 0x48; DAC80501 0x49 (A0 tied to VDD).\nBOOT held low during RESET enters ROM download mode.\nSYS_OK is supply supervision, not a firmware watchdog.',1.1)
    mcu.section(310,35,'USB-C / DATA ONLY','No VBUS-to-board power connection.')
    uc=key('Connector','USB_C_Receptacle_USB2.0_16P');un={num:None for num,*_ in pins(SYMS[uc])}
    for num in ['A1','A12','B1','B12','S1']:un[num]='GND'
    for num in ['A4','A9','B4','B9']:un[num]='USB_VBUS'
    for num in ['A6','B6']:un[num]='USB_DP'
    for num in ['A7','B7']:un[num]='USB_DM'
    un.update({'A5':'USB_CC1','B5':'USB_CC2'})
    mcu.add('J4',uc,345,95,un,'USB-C','Connector_USB:USB_C_Receptacle_HRO_TYPE-C-31-M-12')
    r(mcu,'R15',330,155,'5.1k / 1%','USB_CC1','GND');r(mcu,'R16',380,155,'5.1k / 1%','USB_CC2','GND')
    mcu.add('U6',key('Power_Protection','USBLC6-2SC6'),350,205,{'1':'USB_DM','6':'USB_DM_ESD','3':'USB_DP','4':'USB_DP_ESD','5':'USB_VBUS','2':'GND'},'USBLC6-2SC6')
    r(mcu,'R17',325,238,'22R','USB_DP_ESD','USB_DP_MCU');r(mcu,'R18',375,238,'22R','USB_DM_ESD','USB_DM_MCU')
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

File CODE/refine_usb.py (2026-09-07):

"""Manual USB pair routing; run once against the pre-USB refinement board.

Equivalent ESD channels are swapped in the matching schematic and intent.
The named fabrication stackup is documented separately; impedance needs fab control.
"""
from pathlib import Path
import json,re,sys
import pcbnew as p
import wx
wx.Log.EnableLogging(False)
root=Path(__file__).resolve().parents[1];base=root/'CAD/chatgpt_astra_test2/chatgpt_astra_test2';target=base.with_suffix('.kicad_pcb')
pro=json.loads(base.with_suffix('.kicad_pro').read_text())
for nc in pro['net_settings']['classes']:
    if nc['name']=='USB':nc.update(clearance=.15,track_width=.25,diff_pair_width=.25,diff_pair_gap=.15,via_diameter=.5,via_drill=.25)
pro['board']['design_settings']['rules'].update(min_via_diameter=.5,min_through_hole_diameter=.25)
base.with_suffix('.kicad_pro').write_text(json.dumps(pro,indent=2)+'\n')
mgr=p.GetSettingsManager();mgr.LoadProject(str(base.with_suffix('.kicad_pro')));b=p.LoadBoard(str(target))
remove=set()
copper_only='--copper-only' in sys.argv
for t in b.GetTracks():
    usb='USB_D' in t.GetNetname()
    points=[t.GetPosition()] if isinstance(t,p.PCB_VIA) else [t.GetStart(),t.GetEnd()]
    xs=[p.ToMM(a.x) for a in points];ys=[p.ToMM(a.y) for a in points]
    corridor=max(xs)>=92 and min(xs)<=116 and max(ys)>=60 and min(ys)<=78
    # Clear the local controller routing to accommodate relocated parts and pair.
    ground_return=t.GetNetname()=='GND' and ((isinstance(t,p.PCB_VIA) and (round(xs[0],2),round(ys[0],2)) in [(96.8,60.6),(90.8,63.8),(90.8,65.2),(94.8,64)]) or (not isinstance(t,p.PCB_VIA) and abs(xs[0]-93.8625)<.001 and abs(ys[0]-64)<.001))
    if usb or (corridor and not copper_only) or ground_return:remove.add(t.m_Uuid.AsString())
s=target.read_text();target.write_text(re.sub(r'\n\t\((?:segment|via)\n.*?\n\t\)',lambda m:'' if any(u in m[0] for u in remove) else m[0],s,flags=re.S))
b=p.LoadBoard(str(target));fps={f.GetReference():f for f in b.GetFootprints()}
def xy(x,y):return p.VECTOR2I(p.FromMM(x),p.FromMM(y))
def pad(r,n):return next(a for a in fps[r].Pads() if a.GetNumber()==str(n))
for ref,x,y in [('R18',112.5,65.8),('R17',112.5,68.8),('U5',107,75),('C14',103.8,73.4),('D3',109,71.8),('R10',137,75),('R16',99.5,70.5)]:
    f=fps[ref];f.SetPosition(xy(x,y))
    if ref=='R10':f.SetOrientationDegrees(0)
prefix='/03 / ESP32 AND USB/'
for pin,name in [('1','USB_DM'),('6','USB_DM_ESD'),('3','USB_DP'),('4','USB_DP_ESD')]:pad('U6',pin).SetNet(b.FindNet(prefix+name))
def path(net,pts,layer=p.F_Cu,width=.25):
    pts=[xy(*a) if isinstance(a,tuple) else a for a in pts]
    for a,z in zip(pts,pts[1:]):
        t=p.PCB_TRACK(b);t.SetStart(a);t.SetEnd(z);t.SetLayer(layer);t.SetWidth(p.FromMM(width));t.SetNetCode(net);b.Add(t)
def via(net,x,y):
    v=p.PCB_VIA(b);v.SetPosition(xy(x,y));v.SetWidth(p.FromMM(.5));v.SetDrill(p.FromMM(.25));v.SetViaType(p.VIATYPE_THROUGH);v.SetLayerPair(p.F_Cu,p.B_Cu);v.SetNetCode(net);b.Add(v)
def route(a,z,pts=(),width=.25):
    a=pad(*a);z=pad(*z);assert a.GetNetCode()==z.GetNetCode();path(a.GetNetCode(),[a.GetPosition(),*pts,z.GetPosition()],width=width)
# Paired protected trunk, with series resistors near the module.
route(('U6',6),('R18',1),[(97.7,63.05),(99.65,65),(101,65),(101.5,64.5),(101.5,62.9945),(102.5,62.9945),(102.5,64.5),(103,65),(108.5,65),(109.3,65.8)])
route(('U6',4),('R17',1),[(97.7843,64.95),(98.2343,65.4),(107,65.4),(110.4,68.8)])
route(('R18',2),('U4',13),[(114.7,65.8),(115.58,66.68)])
route(('R17',2),('U4',14),[(114.7,68.8),(115.55,67.95)])
# USB-C duplicate data contacts join at symmetric midpoints on B.Cu.
for name,pins,xs,y in [('USB_DP',['B6','A6'],[94.25,95.25],60.3),('USB_DM',['A7','B7'],[94.75,95.75],61.1)]:
    net=b.FindNet(prefix+name).GetNetCode()
    for pin,x in zip(pins,xs):path(net,[pad('J4',pin).GetPosition(),(x,y)],width=.15);via(net,x,y)
    middle=(sum(xs)/2,y);path(net,[(xs[0],y),middle,(xs[1],y)],p.B_Cu,.15)
    if name=='USB_DP':
        path(net,[middle,(92.75,62.3),(91.6,62.3),(91.6,64.95)],p.B_Cu);via(net,91.6,64.95);path(net,[(91.6,64.95),pad('U6',3).GetPosition()])
    else:
        path(net,[middle,(94.65,61.7),(93.925,61.7),(92.4,63.225)],p.B_Cu);via(net,92.4,63.225);path(net,[(92.4,63.225),pad('U6',1).GetPosition()])
# Ground returns beside the crossover transitions and ESD reference pin.
g=b.FindNet('GND').GetNetCode()
for x,y in [(96.8,60.6),(90.8,63.8),(90.8,65.2),(94.8,64)]:via(g,x,y)
path(g,[pad('U6',2).GetPosition(),(94.8,64)])
z=p.ZONE(b);z.SetNet(b.FindNet('GND'));z.SetLayer(p.In2_Cu);z.SetLocalClearance(p.FromMM(.2));z.SetMinThickness(p.FromMM(.2));z.SetPadConnection(p.ZONE_CONNECTION_FULL)
poly=z.Outline();poly.NewOutline()
for x,y in [(90.5,59.8),(98,59.8),(98,66),(90.5,66)]:v=xy(x,y);poly.Append(v.x,v.y)
if not copper_only:b.Add(z)
from build_board import place_references
place_references(b,{r:f for r,f in fps.items() if not r.startswith('H')})
b.BuildConnectivity();p.ZONE_FILLER(b).Fill(b.Zones());p.SaveBoard(str(target),b);mgr.UnloadProject(b.GetProject(),False)

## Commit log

2026-09-07 Add ESP32 24V current-loop prototype schematic
    [analog_input.kicad_sch, analog_output.kicad_sch, chatgpt_astra_test2.kicad_pcb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]
2026-09-07 Place serviceable 100x80mm four-layer ESP32 board
    [chatgpt_astra_test2.kicad_pcb]
2026-09-07 Start buck converter and DAC PCB routing
    [chatgpt_astra_test2.kicad_pcb]
2026-09-07 Route buck feedback and analog sense connections
    [chatgpt_astra_test2.kicad_pcb]
2026-09-07 Restore explicit routing classes and fabrication constraints
    [chatgpt_astra_test2.kicad_pcb]
2026-09-07 Route remaining board networks with protected analog paths
    [chatgpt_astra_test2.kicad_pcb]
2026-09-07 Add D2 ground stitch and document remaining layout work
    [chatgpt_astra_test2.kicad_pcb]
2026-09-07 Complete PCB connectivity and resolve local pin escapes
    [chatgpt_astra_test2.kicad_pcb]
2026-09-07 Refine USB pair and add prototype thermal copper and stackup
    [chatgpt_astra_test2.kicad_pcb, controller.kicad_sch]
2026-09-07 Ran out of resets, final output
    [chatgpt_astra_test2-B_Cu.gbl, chatgpt_astra_test2-B_Mask.gbs, chatgpt_astra_test2-B_Paste.gbp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]
